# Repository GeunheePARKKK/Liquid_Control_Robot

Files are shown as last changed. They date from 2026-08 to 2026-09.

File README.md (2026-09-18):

# Liquid Control Robot

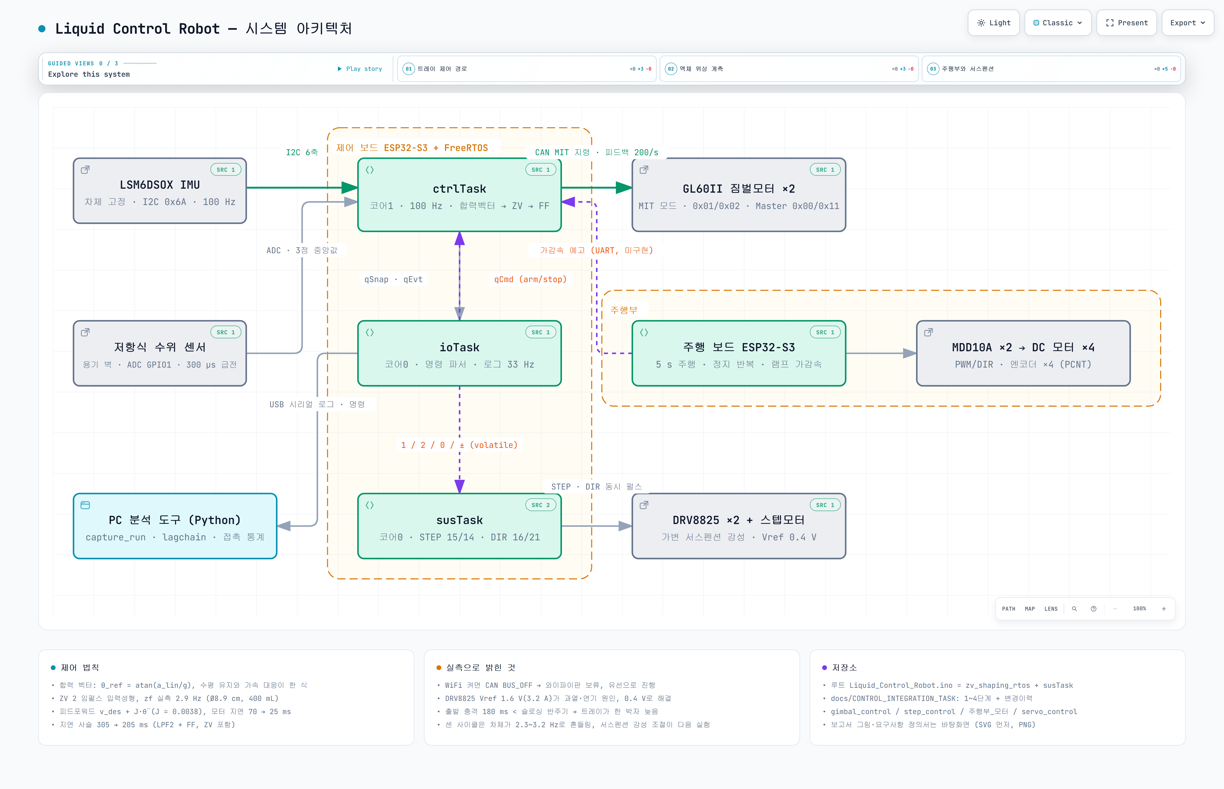
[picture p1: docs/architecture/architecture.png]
architecture


https://geunheeparkkk.github.io/Liquid_Control_Robot/architecture/architecture.html

액체 화물 이송 로봇 제어 시스템 프로젝트입니다.

2026 하계 논문경진대회, 한이음 드림업 공모전 

# 현재 구조

- 'docs': 설계 문서 및 제어 알고리즘 자료
- 'servo_control': 논문경진대회 제출 시 썼던 제어 코드
- 'hardware': 하드웨어와 관련된 파일들

현재는 프로젝트 구조만 구성한 초기 단계입니다.

# POWERSHELL에서 업데이트하는 법

git pull --rebase origin main

git add .

git commit -m "Update"

git push

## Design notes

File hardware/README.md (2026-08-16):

**URDF VIEWER**

https://gkjohnson.github.io/urdf-loaders/javascript/example/bundle/

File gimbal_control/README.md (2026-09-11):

# gimbal_control

짐벌모터 제어 코드.

| 파일 | 내용 |
|---|---|
| [motor_test.ino](motor_test.ino) | 짐벌모터 **2축 동시 구동 테스트** |

---

## 모터 설정 (CubeMars 툴에서 설정 완료)

같은 CAN 버스에 모터 2개가 물려 있다.

| 모터 | CAN ID | Master ID | 상태 |
|:---:|:---:|:---:|---|
| 1축 | `0x01` | `0x00` | 단독 구동 확인 완료 |
| 2축 | `0x02` | `0x11` | 2축 동시 구동 테스트 중 |

> Master ID는 모터가 피드백을 올릴 때 쓰는 식별자.
> 실제로 어떤 값으로 올라오는지는 `motor_test.ino` 로그의 `rxid` 로 확인할 것.

---

## motor_test.ino

두 모터에 **동일한 목표**를 보내 ±0.5 rad을 0.5초 주기로 왕복시킨다.
두 축이 같은 동작을 하는지, 피드백이 각각 정상적으로 올라오는지 확인하는 용도.

### CAN 프로토콜

| 항목 | 값 |
|---|---|
| 속도 | 1 Mbit/s |
| 핀 | TX = GPIO4, RX = GPIO5 |
| 종단저항 | 100Ω |
| 송신 ID | `0x100 \| CAN_ID` (위치/속도 모드) |
| 송신 데이터 | `[0:3]` 목표 위치 float LE / `[4:7]` 속도 제한 float LE |

**유니버설 명령** — `0xFF` × 7 + 명령 바이트

| 바이트 | 동작 |
|:---:|---|
| `0xFB` | 에러 해제 |
| `0xFC` | enable |
| `0xFD` | disable |
| `0xFE` | 현재 위치를 영점으로 |

**수신 프레임**

| 바이트 | 내용 |
|---|---|
| `data[0]` | 상위 4bit = 에러 코드, **하위 4bit = 모터 CAN ID** |
| `data[1:2]` | 위치 (±12.5 rad) |
| `data[6]` | MOS 온도 |
| `data[7]` | 로터 온도 |

> 모터가 2대이므로 수신 프레임은 반드시 `data[0] & 0x0F` 로 어느 모터 것인지
> 구분해야 한다. 1축 시절 코드는 이 구분이 없어 2축에서는 값이 섞인다.

### 정상 동작 예시

```
모터 2개 초기화 완료 (CAN ID: 0x01, 0x02)
[모터1] rxid=0x000 상태=0 pos=+0.50rad temp=32/35
[모터2] rxid=0x011 상태=0 pos=+0.50rad temp=31/34
```

### 한쪽만 응답할 때

1. 종단저항 — 모터 2개면 버스 양 끝에 각각 필요할 수 있음
2. 2축 모터의 CAN ID가 CubeMars 툴에서 실제로 저장됐는지
3. CANH / CANL 분기 배선

---

배선 상세는 [hardware/배선도.md](../hardware/배선도.md) 참고.

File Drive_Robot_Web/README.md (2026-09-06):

# Drive_Robot_Web — ESP32-S3 주행 로봇 웹 브라우저 리모컨

ESP32-S3가 직접 WiFi 핫스팟(AP)과 웹서버를 띄워서, 노트북/휴대폰 브라우저로
W/A/S/D 키를 눌러 실시간 주행 제어하는 리모컨 UI. 공유기·인터넷 불필요.

## 🌐 접속 주소

> ### http://192.168.4.1

⚠ **먼저 ESP32의 WiFi에 연결해야 접속됩니다.** `192.168.4.1`은 ESP32가 만든
자체 네트워크 안에서만 통하는 주소라서, 다른 WiFi나 LTE에서는 열리지 않는다.

| 항목 | 값 |
|---|-----|
| WiFi 이름 (SSID) | `Drive_Robot` |
| WiFi 비밀번호 | `drive1234` |
| 웹 UI | `http://192.168.4.1` |
| WebSocket 포트 | 81 (UI가 자동으로 연결) |

## 사용 순서

1. `drive_web_ui/drive_web_ui.ino` 를 ESP32-S3에 업로드 (보드: **ESP32S3 Dev Module**)
2. 노트북/휴대폰 WiFi 목록에서 **`Drive_Robot`** 접속 (비밀번호 `drive1234`)
3. 브라우저에서 **`http://192.168.4.1`** 열기
4. W/A/S/D — 누르고 있는 동안만 이동, 떼면 즉시 정지 (데드맨 방식)

## 기능

- **W/A/S/D 데드맨 조작** — 누르는 동안만 이동. W+A 같은 동시 입력 조합 가능
- **화면 터치 버튼** — 휴대폰에서도 리모컨으로 사용 가능
- **속도 슬라이더** (0~255)
- **시리얼 모니터 대체** — 하단 명령창에서 임의 명령 전송(`?`, `v200`, `stop` 등),
  보드 출력은 로그창에 실시간 표시. USB 시리얼(115200)도 그대로 공존
- **안전 장치 4중**
  1. 400ms 무소식이면 자동 정지 (WiFi 끊김·브라우저 멈춤 대비 워치독)
  2. 브라우저 탭 이탈/창 포커스 상실 시 정지
  3. WebSocket 연결 끊김 시 정지
  4. Space 키 / STOP 버튼 비상 정지

## 필요한 라이브러리

- **WebSockets** by Markus Sattler ([links2004/arduinoWebSockets](https://github.com/Links2004/arduinoWebSockets))
  — 라이브러리 매니저에서 `WebSockets` 검색 후 설치
- `WiFi.h` / `WebServer.h` 는 ESP32 보드 패키지 내장

## 주행 코드 연결점 (TODO)

현재 모터 출력은 스텁(로그 출력만)이라 모터 없이도 안전하게 UI 테스트 가능.
실제 주행 코드는 `drive_web_ui.ino` 의 두 함수만 채우면 된다:

| 함수 | 역할 |
|---|---|
| `setMotors(fl, fr, rl, rr)` | 4개 모터 드라이버에 PWM 출력 (−255 ~ +255, 부호 = 방향) |
| `handleLine(String)` | 시리얼/웹 명령창 공용 명령 처리 — 기존 코드의 handleLine 이식 자리 |

## 파일 구성

```
drive_web_ui/
├── drive_web_ui.ino   펌웨어 — WiFi AP + HTTP 서버 + WebSocket + 데드맨 워치독
└── web_ui.h           내장 웹 UI (HTML/CSS/JS) — 수정 시 재업로드 필요
```

## WebSocket 프로토콜 (포트 81)

| 방향 | 메시지 | 의미 |
|---|---|---|
| 브라우저 → 보드 | `k:<mask>` | 키 상태 비트마스크 (bit0=W, bit1=A, bit2=S, bit3=D). 눌린 동안 100ms마다 재전송 |
| 브라우저 → 보드 | `v:<0~255>` | 속도 |
| 브라우저 → 보드 | `c:<text>` | 임의 명령줄 (시리얼 모니터와 동일 처리) |
| 브라우저 → 보드 | `x` | 비상 정지 |
| 보드 → 브라우저 | 텍스트 줄 | UI 로그창에 표시 |

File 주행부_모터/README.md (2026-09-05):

# 주행부 ESP32-S3 배선

DC 모터 4개 + MDD10A 2개 + 엔코더 4개를 **별도의 ESP32-S3(2번 보드)** 한 장에 붙인다.
짐벌·수위센서·스텝모터는 지금까지 쓰던 1번 보드에 그대로 남는다.

작성 2026-09-06.

---

## 구성

| 보드 | 담당 | 핀 사용 |
|---|---|---|
| **1번 ESP32-S3** (기존) | 짐벌 CAN, 차체 IMU, 수위센서, **스텝모터 2개** | 1·2 수위 / 4·5 CAN / 11·12 I2C / 19·20 USB / 17·18 보드 간 UART / **14·15·16·21 스텝** |
| **2번 ESP32-S3** (신규) | **DC 모터 4개, MDD10A 2개, 엔코더 4개** | 아래 표 |

두 보드는 UART 한 줄로 잇는다. 2번 보드가 가감속 명령을 내는 순간 1번 보드에 알리면,
짐벌이 IMU로 가속을 재기 전에(65ms 앞서) 트레이를 먼저 기울일 수 있다.

---

## 2번 보드 핀맵

### 왼쪽 구동부 — MDD10A 1 + 왼쪽 앞/뒤 모터

| MDD10A 핀 | 기능 | ESP32-S3 |
|---|---|---|
| PWM 1 | 앞바퀴 속도 | **GPIO 4** |
| DIR 1 | 앞바퀴 방향 | **GPIO 5** |
| PWM 2 | 뒷바퀴 속도 | **GPIO 6** |
| DIR 2 | 뒷바퀴 방향 | **GPIO 7** |
| GND | 로직 GND | ESP32 GND (공통) |

### 오른쪽 구동부 — MDD10A 2 + 오른쪽 앞/뒤 모터

| MDD10A 핀 | 기능 | ESP32-S3 |
|---|---|---|
| PWM 1 | 앞바퀴 속도 | **GPIO 39** |
| DIR 1 | 앞바퀴 방향 | **GPIO 40** |
| PWM 2 | 뒷바퀴 속도 | **GPIO 41** |
| DIR 2 | 뒷바퀴 방향 | **GPIO 42** |
| GND | 로직 GND | ESP32 GND (공통) |

### 엔코더 4개

| 엔코더 | A상 (보라) | B상 (파랑) | Vcc (갈색) | GND (녹색) |
|---|---|---|---|---|
| 왼쪽 앞 | **GPIO 8** | **GPIO 9** | 3V3 | GND |
| 왼쪽 뒤 | **GPIO 10** | **GPIO 11** | 3V3 | GND |
| 오른쪽 앞 | **GPIO 12** | **GPIO 13** | 3V3 | GND |
| 오른쪽 뒤 | **GPIO 14** | **GPIO 15** | 3V3 | GND |

A상·B상 모두 **PCNT(펄스카운터) 하드웨어**가 센다. 우노에서 쓰던 인터럽트 0/1 + PCINT 구분이
필요 없고, 4개 엔코더 전부 쿼드러처(방향 포함)로 CPU 부하 없이 읽힌다.

### 보드 간 UART (1번 보드와)

| 2번 보드 | 1번 보드 | |
|---|---|---|
| **GPIO 17** (TX) | GPIO 18 (RX) | |
| **GPIO 18** (RX) | GPIO 17 (TX) | |
| GND | GND | **공통 필수** |

### 남는 핀

`1 2 16 21 47` 자유. `3`(스트래핑)·`38`/`48`(보드 LED)은 출력 용도로만.

---

## 우노 배선과의 대응

| 기능 | 우노 (예전) | 2번 ESP32-S3 |
|---|---|---|
| 왼앞 PWM / DIR | D5 / A0 | 4 / 5 |
| 왼뒤 PWM / DIR | D6 / A1 | 6 / 7 |
| 오른앞 PWM / DIR | D9 / A2 | 39 / 40 |
| 오른뒤 PWM / DIR | D10 / A3 | 41 / 42 |
| 왼앞 엔코더 A / B | D2 (INT0) / D4 | 8 / 9 |
| 왼뒤 엔코더 A / B | D8 (PCINT) / D11 | 10 / 11 |
| 오른앞 엔코더 A / B | D3 (INT1) / D7 | 12 / 13 |
| 오른뒤 엔코더 A / B | D12 (PCINT) / D13 | 14 / 15 |
| 엔코더 Vcc | 쉴드 V핀 (5V) | **3V3** ← 아래 참고 |

---

## 반드시 확인할 것

### 1. 엔코더 전압 — 5V를 넣으면 핀이 상한다

우노 쉴드에서는 엔코더 Vcc가 5V였고, 그러면 A/B 출력도 5V로 나온다.
**ESP32-S3 GPIO는 5V를 못 받는다.** 엔코더 갈색선을 **3V3**에 물려서 출력을 3.3V로 낮춘다.
대부분의 DC모터 홀 엔코더는 3.3~5V 동작이다. 사양이 5V 전용이면 A/B 각각에
저항 분압(예: 2kΩ + 3.3kΩ)이나 레벨시프터를 넣는다.

### 2. MDD10A 로직 레벨

MDD10A는 3.3V / 5V 로직을 모두 받는다. 별도 처리 없이 GPIO 직결.
**MDD10A GND와 ESP32 GND는 반드시 공통.**

### 3. 전원

- 모터 전원은 MDD10A의 배터리 단자로. ESP32에는 모터 전류가 흐르지 않게.
- ESP32 3V3에서 엔코더 4개(각 10~20mA) 정도는 문제없다.
- 1번 보드에서 CAN 두절이 반복된 이력이 있다. 모터 전원과 짐벌 24V가 같은 배터리면
  가감속 순간의 전압 처짐을 봐야 한다.

### 4. 2번 보드 Arduino IDE 설정

새 스케치 폴더마다 `Tools → USB CDC On Boot = Enabled`. 기본이 Disabled라 잊으면
시리얼이 안 뜬다.

---

## 1번 보드에 붙는 스텝모터 2개

| DRV8825 | 1번 보드 |
|---|---|
| STEP 1 / DIR 1 | **GPIO 15 / 16** |
| STEP 2 / DIR 2 | **GPIO 14 / 21** |
| ENABLE ×2 | GND (항상 켜짐) 또는 남는 핀 하나 공유 |
| RESET, SLEEP | 3V3 (필수) |

`step_control/drv8825_s3_test.ino` 의 STEP/DIR 5/4 는 CAN과 겹치므로 1번 보드에서는 위 핀으로 옮긴다.
1번 보드는 RTOS 라 STEP 펄스를 `delayMicroseconds` 루프로 만들면 100Hz 제어 태스크가 막힌다.
LEDC 나 RMT 로 내야 한다.

---

## 소프트웨어 (2번 보드)

- PWM: LEDC, 20kHz (MDD10A 상한), 4채널
- 엔코더: PCNT 4유닛, 쿼드러처 모드
- 주행 명령을 낼 때 UART 로 1번 보드에 `가속 시작 / 목표 가속도 / 램프 길이`를 보낸다
- 가감속 램프는 **0.7초 이상**으로 둔다. 짐벌 보상이 확실히 먹는 대역이 0.7Hz 아래다

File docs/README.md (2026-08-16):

# Documents

제어 알고리즘, 실험 계획, 논문 및 설계 문서를 보관합니다.

## AI 협업 문서

세 명이 역할을 나누어 각자의 AI와 작업할 때 다음 순서로 자료를 제공합니다.

1. [공통 작업 규약](COMMON_CONTEXT.md)
2. 본인의 역할 문서
3. 역할 문서에 지정된 소스와 데이터시트

역할별 문서:

- [담당 1: GL60II 및 CAN 통신](MOTOR_CAN_TASK/README.md)
- [담당 2: 이중 IMU 및 데이터](SENSOR_DATA_TASK/README.md)
- [담당 3: 제어 알고리즘 및 통합](CONTROL_INTEGRATION_TASK/README.md)

각 담당자는 AI가 제안한 변경사항을 검토하고 승인한 뒤 자신의 브랜치에서 작업합니다. 핀, 센서 종류, 통신 설정과 안전 제한은 `Config.h/.cpp`에서만 정의하며, 다른 모듈은 이를 읽어서 사용합니다.

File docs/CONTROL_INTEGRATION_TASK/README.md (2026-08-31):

# 제어 통합 — 축 정의 및 신호 규약

## 폴더 구성

| 폴더 | 내용 | 상태 |
|---|---|---|
| [`[0단계] 센서 및 모터 설정`](%5B0%EB%8B%A8%EA%B3%84%5D%20%EC%84%BC%EC%84%9C%20%EB%B0%8F%20%EB%AA%A8%ED%84%B0%20%EC%84%A4%EC%A0%95) | IMU 읽기, 배선·통신 진단 | 완료 |
| [`[1단계] 수평제어`](%5B1%EB%8B%A8%EA%B3%84%5D%20%EC%88%98%ED%8F%89%EC%A0%9C%EC%96%B4) | `motor_cmd = −θ_base` | `g1.0` 검증 완료 |
| [`[2단계] 합력벡터`](%5B2%EB%8B%A8%EA%B3%84%5D%20%ED%95%A9%EB%A0%A5%EB%B2%A1%ED%84%B0) | `θ_ref = atan(a_lin/g)` | **작업 중** |
| [`[3단계] ZV 입력성형`](%5B3%EB%8B%A8%EA%B3%84%5D%20ZV%20%EC%9E%85%EB%A0%A5%EC%84%B1%ED%98%95) | `θ_ref` 에 ZV / ZVD | **작업 중** |
| [`[4단계] RTOS 태스크 분리`](%5B4%EB%8B%A8%EA%B3%84%5D%20RTOS%20%ED%83%9C%EC%8A%A4%ED%81%AC%20%EB%B6%84%EB%A6%AC) | `loop()` 을 `ctrl`+`io` 로 분리 | **실기 검산 완료** |
| `capture.py` | 시리얼 로그 캡처 — **전 단계 공용 도구** | — |

`capture.py` 는 특정 단계에 속하지 않아 최상위에 둔다.

### 0단계 — 센서 및 모터 설정

| 파일 | 용도 |
|---|---|
| `IMU_Reading.ino` | IMU 읽기만 (SPI). 상보필터·신뢰도 가중 검증 |
| `MIT_안전점검.ino` | 무동력 상태로 CAN 주소 충돌·게인 탐침 |
| `IMU_핀찾기.ino` | SPI 응답 없을 때 CS 핀 스캔 |
| `IMU_I2C확인.ino` | SPI 죽었을 때 칩 생사 판별 |

### 1단계 — 수평제어

| 파일 | 용도 |
|---|---|
| `모터_수평제어_I2C.ino` | **현행** — IMU I2C |
| `모터_수평제어_MIT.ino` | 같은 제어, IMU 는 SPI (SPI 사망으로 보류) |
| `모터_수평제어.ino` | 위치/속도 모드판 (되돌릴 때용) |

### 2단계 — 합력벡터

| 파일 | 용도 |
|---|---|
| `합력벡터_제어.ino` | 1단계에 `θ_ref` 추가. `ACC_GAIN` 기본 0 |
| `README.md` | 시리얼 명령 파라미터 기능 정리 |

### 3단계 — ZV 입력성형

| 파일 | 용도 |
|---|---|
| `ZV_입력성형.ino` | `θ_ref` 에 ZV/ZVD. `ZV_ON` 기본 꺼짐 |

각 `.ino` 의 변경 이력은 같은 이름의 `_변경이력.md` 에 있다.
`gimbal_control/motor_test_MIT.ino` 는 모터만 돌려보는 테스트다.

## 진행 단계

```
[완료] 1단계  수평제어        motor_cmd = −θ_base
[다음] 2단계  합력 벡터        θ_ref = atan2(a_linear, g)
[작업] 3단계  ZV 입력성형      θ_shaped = ZV(θ_ref)   수평 항에는 걸지 않는다
```

---

## 축 정의

| 이름 | 회전축 | 의미 |
|---|---|---|
| **pitch** | **X축 중심 회전** | 앞뒤 기울기 |
| **roll** | **Y축 중심 회전** | 좌우 기울기 |

---

## 센서 → 각도 매핑

```cpp
// pitch : X축 중심 회전
float rate_pitch = ((float)gx - gyro_bias_x) / GYRO_LSB;                    // X축 자이로
float pitch_acc  = atan2((float)ay,  sqrt(ax*ax + az*az)) * (180.0 / PI);   // Y축 가속도

// roll : Y축 중심 회전
float rate_roll  = ((float)gy - gyro_bias_y) / GYRO_LSB;                    // Y축 자이로
float roll_acc   = atan2((float)-ax, sqrt(ay*ay + az*az)) * (180.0 / PI);   // X축 가속도
```

| | 회전축 | 자이로 | 가속도 |
|---|---|---|---|
| pitch | X | `gx` | `ay` |
| roll | Y | `gy` | `-ax` |

> 회전축과 사용하는 가속도 축이 서로 다르다. X축 중심으로 돌면 Y축 가속도가
> 변하기 때문. 코드 읽을 때 혼동하기 쉬운 지점.

---

## 시리얼 출력 4개

```cpp
Serial.printf("pitch:%.2f,pitch_acc:%.2f,roll:%.2f,roll_acc:%.2f\n",
              pitch_filtered, pitch_acc, roll_filtered, roll_acc);
```

| 출력 이름 | 변수 | 정체 | 용도 |
|---|---|---|---|
| **`pitch`** | `pitch_filtered` | 상보필터 결과 (자이로+가속도 융합) | **제어 입력** |
| `pitch_acc` | `pitch_acc` | 가속도계 단독 계산값 | 진단 전용 |
| **`roll`** | `roll_filtered` | 상보필터 결과 | **제어 입력** |
| `roll_acc` | `roll_acc` | 가속도계 단독 계산값 | 진단 전용 |

- 단위: **도(°)**, 4개 전부
- 기준: **중력 기준 절대 각도** (베이스 대비 상대각이 아님)
- 출력 주기: 10Hz (제어 루프는 100Hz)
- 포맷: `이름:값` 쉼표 구분 — 아두이노 시리얼 플로터 호환

### `_acc` 를 함께 출력하는 이유

제어에 쓰는 값이 아니라 **필터가 제대로 동작하는지 보는 참고선**이다.

| 관측 | 의미 |
|---|---|
| 정지 시 `pitch` ≈ `pitch_acc` | 정상 (실측 0.03° 이내) |
| 움직일 때 둘이 벌어짐 | 정상 — 가속도계가 관성에 오염된 것 |
| 둘이 **반대 방향**으로 움직임 | 자이로 부호 반전 필요 |
| 정지 후에도 안 붙음 | 드리프트 발생 |

제어 코드로 넘어가면 `_acc` 두 개는 디버깅 목적 외에는 빼도 된다.

---

## 모터 대응

### 확정된 것 — 물리 축과 모터 (2026-08-29 실측)

무동력 상태에서 각 축을 손으로 돌려 확인했다. 돌린 축의 모터만 위치가 변했다.

| 물리 축 | 모터 CAN ID | Master ID |
|---|---|---|
| **바깥축** | `0x01` | `0x00` |
| **안쪽축** | `0x02` | **`0x11`** |

> Master ID 가 `0x11` 인 이유는 MIT 모드 명령 주소(`0x001`/`0x002`)와 겹치지
> 않게 하기 위함이다. 겹치면 한 모터가 다른 모터의 피드백을 명령으로 읽어
> 폭주한다. [`모터_수평제어_MIT.ino_변경이력.md`](%5B1%EB%8B%A8%EA%B3%84%5D%20%EC%88%98%ED%8F%89%EC%A0%9C%EC%96%B4/%EB%AA%A8%ED%84%B0_%EC%88%98%ED%8F%89%EC%A0%9C%EC%96%B4_MIT.ino_%EB%B3%80%EA%B2%BD%EC%9D%B4%EB%A0%A5.md) 참고.

### 미확정 — pitch/roll 과 모터

코드의 `CAN_ID_PITCH` / `CAN_ID_ROLL` 은 **임시 배정**이다.

`pitch` 는 "IMU 보드의 X축 중심 회전"인데, 시운전 동안 IMU 를 손에 들고 있어
짐벌의 어느 축과도 고정된 관계가 없었다. **차체에 실장한 뒤** 아래 순서로 확정한다.

1. IMU 의 +X축이 짐벌의 어느 축과 나란한지 확인
2. 그 축을 담당하는 모터를 `CAN_ID_PITCH` 에 배정
3. `DIR_PITCH` / `DIR_ROLL` 부호를 다시 확인

### 참고 — 문서 간 표기가 엇갈린다

X/Y 라는 이름은 쓰지 않기로 했다. 출처마다 반대로 적혀 있기 때문이다.

| 출처 | Pitch | Roll |
|---|---|---|
| 논문 + 이전 서보 코드 | Y축 모터 | X축 모터 |
| 한이음 보고서 | Motor_X | Motor_Y |

그래서 코드에서는 담당 각도로 이름 붙였다 (`CAN_ID_PITCH`, `CAN_ID_ROLL`).

---

## 부호 방향 (검증 완료)

기준은 **브레이크아웃 보드에 인쇄된 X / Y / Z 축 화살표**다.
로봇의 앞뒤좌우가 아니라 보드 자체의 축을 기준으로 판단한다.

### 코드에서 유도한 예상

가속도계는 **위를 향한 축이 +1g** 를 읽는다 (ST 표준 규약).

```cpp
pitch_acc = atan2( ay, ...)    // ay > 0  →  pitch +
roll_acc  = atan2(-ax, ...)    // ax < 0  →  roll +
```

| | 조건 | 물리적 의미 |
|---|---|---|
| **`+pitch`** | `ay > 0` | 보드의 **+Y 축 쪽이 위로** 들림 |
| **`+roll`** | `ax < 0` | 보드의 **+X 축 쪽이 아래로** 내려감 |

### 실측 확인 결과 ✅ (2026-08-27)

**예상과 실측이 일치. 부호 반전 불필요, 코드 수정 없이 그대로 사용.**

| 항목 | 예상 | 실측 |
|---|---|---|
| +Y 축 상승 시 `pitch` | `+` | **`+` 일치** |
| +X 축 하강 시 `roll` | `+` | **`+` 일치** |

확정된 부호 규약.

| 부호 | 물리적 상태 |
|---|---|
| `pitch > 0` | 보드 **+Y 축 쪽이 위로** 들림 |
| `pitch < 0` | 보드 **+Y 축 쪽이 아래로** 내려감 |
| `roll > 0` | 보드 **+X 축 쪽이 아래로** 내려감 |
| `roll < 0` | 보드 **+X 축 쪽이 위로** 들림 |

> **제어기는 이 부호를 줄이는 방향으로 모터를 구동해야 한다.**
> 반대로 걸면 기울어짐을 키우는 방향이 되어 발산한다.

### 재확인 절차

센서를 다시 장착하거나 방향을 바꾸면 아래 절차로 다시 확인한다.
코드 수정 없이 기존 시리얼 출력만 보면 된다.

1. 보드를 평평하게 두고 `pitch` / `roll` 이 0 근처인지 확인
2. **+Y 축 쪽을 들어올린다** → `pitch` 부호 기록
3. 평평하게 되돌린 뒤 **+X 축 쪽을 내린다** → `roll` 부호 기록

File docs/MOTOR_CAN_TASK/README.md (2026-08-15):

# 담당 1: GL60II 및 CAN 통신

## 목표

ESP32-S3의 TWAI 컨트롤러와 외부 CAN 트랜시버를 사용하여 GL60II 두 대에 Position/Velocity 명령을 보내고, 모터 피드백과 통신 상태를 상위 모듈에 제공합니다.

## AI에 제공할 자료

1. `docs/ai-handoff/COMMON_CONTEXT.md`
2. 이 문서
3. `firmware/gimbal_control/Gimbal.h`
4. `firmware/gimbal_control/Gimbal.cpp`
5. `firmware/gimbal_control/Config.h` — 읽기 전용
6. `Gimbal Motor Drive User Manual.pdf`
7. `ESP32-S3-DEVKITC-1-N16R8V_Espressif_Systems.pdf`

## 파일 소유권

- 수정 가능: `Gimbal.h`, `Gimbal.cpp`
- 읽기 전용: `Config.h/.cpp`
- 수정 금지: `Sensor.*`, `Control.*`, `gimbal_control.ino`

새 테스트 파일이나 공용 헤더가 필요하면 팀의 승인을 먼저 받습니다.

## 구현 책임

- Config에서 CAN 핀, 속도, 모터 ID와 타임아웃을 읽어 TWAI 초기화
- GL60II Position/Velocity 표준 11-bit CAN 프레임 생성
- 활성화, 비활성화, 현재 위치 영점, 오류 해제 명령 제공
- 목표 위치 rad와 최대속도 rad/s를 GL60II 형식으로 변환
- 피드백에서 모터 ID, 위치, 속도, 토크, 온도와 오류 코드 해석
- Config에 설정된 두 모터의 최신 피드백을 각각 보관
- 마지막 정상 피드백 시각과 통신 건강 상태 제공
- 잘못된 CAN ID, DLC, 범위 또는 오래된 피드백 거부

## 공개 인터페이스 목표

```cpp
class GimbalBus {
public:
    bool begin();
    bool enable(uint8_t motorId);
    bool disable(uint8_t motorId);
    bool clearError(uint8_t motorId);
    bool setCurrentPositionZero(uint8_t motorId);
    bool commandPositionVelocity(
        uint8_t motorId,
        float positionRad,
        float maxVelocityRadS);
    void poll();
    bool getFeedback(uint8_t motorId, MotorFeedback& out) const;
    bool healthy(uint8_t motorId, uint32_t nowMs) const;
};
```

`GimbalBus`는 IMU, 합력 계산, P와 ZV를 알지 못합니다. 설정값은 Config에서 읽고 프로토콜 계층에서 명령 범위를 검증합니다.

## 구현 순서

1. 매뉴얼에서 Position/Velocity 프레임과 공통 명령 확인
2. ID와 float 바이트 순서 인코딩·디코딩 함수 작성
3. TWAI 초기화와 송수신 처리
4. 한 모터 활성화와 무부하 소각도 명령
5. 두 모터 피드백 분리
6. 타임아웃과 오류 상태 제공

## 안전 및 금지사항

- `begin()`에서 모터를 자동 활성화하지 않습니다.
- 영점 설정을 부팅 시 자동 호출하지 않습니다.
- 피드백을 받지 못했을 때 임의의 값을 만들지 않습니다.
- MIT와 Velocity 모드는 현재 범위에 추가하지 않습니다.
- 통신 타임아웃을 감지하되 시스템 전체 정책은 통합 담당자에게 맡깁니다.
- 핀, ID, 제한값을 `Gimbal` 파일에 하드코딩하지 않습니다.

## 완료 기준

- 매뉴얼 예제와 생성된 CAN ID 및 데이터 바이트가 일치함
- 한 모터가 무부하 소각도 명령을 수행하고 피드백이 갱신됨
- Config로 지정된 두 모터의 피드백이 서로 섞이지 않음
- 잘못된 DLC와 알 수 없는 ID가 거부됨
- 타임아웃 후 `healthy()`가 false를 반환함

## AI 전달용 프롬프트

```text
COMMON_CONTEXT.md, MOTOR_CAN_TASK.md와 제공된 소스 및 데이터시트를 모두 읽어라.
너는 GL60II/TWAI 담당자이며 Gimbal.h와 Gimbal.cpp만 소유한다.
먼저 현재 상태, 데이터시트에서 확인한 프로토콜과 구현 계획을 설명하고 변경 승인을 요청하라.
승인 전에는 파일을 수정하지 마라.
Position/Velocity 모드만 구현하고 센서 및 P/ZV 제어를 추가하지 마라.
핀, CAN ID, 속도와 제한값은 Config에서 읽고 Gimbal 파일에 하드코딩하지 마라.
다른 담당자의 파일은 수정하지 마라.
작업 후 변경 API, 프레임 검증, 하드웨어 시험 절차와 남은 위험을 보고하라.
```

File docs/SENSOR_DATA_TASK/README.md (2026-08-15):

# 담당 2: 이중 IMU 및 데이터

## 목표

하부 베이스와 상부 트레이의 IMU를 안정적으로 읽고, 센서별 물리 단위 데이터와 유효 상태를 제어 모듈에 제공합니다. 이후 슬로싱 주파수 학습에 사용할 데이터 형식을 준비합니다.

## AI에 제공할 자료

1. `docs/ai-handoff/COMMON_CONTEXT.md`
2. 이 문서
3. `firmware/gimbal_control/Sensor.h`
4. `firmware/gimbal_control/Sensor.cpp`
5. `firmware/gimbal_control/Config.h` — 읽기 전용
6. 실제로 확정된 각 IMU의 공식 데이터시트
7. 검증된 기존 센서 코드가 있다면 센서 관련 부분만 별도 제공

## 작업 전 필수 확인

Config에 설정할 두 IMU의 정확한 모델, CS 핀과 공용 SPI 핀을 먼저 확정해야 합니다. 공식 데이터시트에서 다음 항목을 확인하지 못하면 레지스터 코드를 추측하지 않습니다.

- WHO_AM_I 기대값
- 지원 SPI 모드와 최대 클럭
- 초기화 레지스터
- 연속 읽기 시작 주소와 바이트 순서
- 가속도·자이로 측정 범위와 스케일
- 센서 장착 축 변환

서로 다른 IMU 모델을 사용하면 각 센서의 초기화, SPI 설정, 엔디언과 스케일을 분리합니다.

## 파일 소유권

- 수정 가능: `Sensor.h`, `Sensor.cpp`, 승인된 데이터 관련 파일
- 읽기 전용: `Config.h/.cpp`
- 수정 금지: `Gimbal.*`, `Control.*`, `gimbal_control.ino`

## 구현 책임

- Config에서 SPI 핀, CS 핀, 센서 종류와 타임아웃을 읽어 초기화
- 센서별 WHO_AM_I 검사와 초기화 상태 반환
- 원시값을 m/s²와 rad/s로 변환
- 정지 상태 자이로 바이어스 측정
- 필요한 가속도 보정값 제공
- 센서별 샘플 타임스탬프와 `valid` 상태 제공
- 포화, 읽기 실패와 오래된 데이터 검출
- 두 센서 데이터를 일관된 베이스·트레이 축 기준으로 제공
- 시간, 두 IMU, 목표각과 모터 피드백을 결합할 CSV 열 정의 제안

## 공개 인터페이스 목표

```cpp
bool initSensors();
bool calibrateSensorsStationary(uint16_t sampleCount);
bool readSensors(ImuPair& out);
bool sensorsHealthy(uint32_t nowUs);
```

센서 모듈이 자세 추정까지 담당하게 변경하려면 통합 담당자와 먼저 인터페이스를 합의합니다.

## 구현 순서

1. 실제 IMU 모델과 공식 데이터시트 확정
2. 센서별 단독 WHO_AM_I 시험
3. 센서별 원시값과 물리 단위 변환 시험
4. 두 센서 공용 SPI 동시 구성
5. 정지 바이어스 보정
6. 축 방향과 부호 검증
7. 목표 제어주기에서 누락과 지연 측정
8. 통합 데이터 형식 제안

## 안전 및 금지사항

- 센서 초기화 실패를 정상 상태로 숨기지 않습니다.
- 한 센서의 레지스터, 스케일과 바이트 순서를 다른 센서에 재사용하지 않습니다.
- 모터, CAN, P와 ZV 코드를 Sensor에 넣지 않습니다.
- 핀과 센서 종류를 `Sensor` 파일에 하드코딩하지 않습니다.
- 검증되지 않은 데이터를 정상 CNN 학습 데이터로 표시하지 않습니다.

## 완료 기준

- 각 센서의 WHO_AM_I가 공식 기대값과 일치함
- 정지 상태에서 가속도 크기가 약 1 g이고 자이로 평균이 0에 가까움
- 알려진 방향으로 기울일 때 축과 부호가 정의와 일치함
- 두 센서를 함께 읽어도 데이터가 섞이지 않음
- 목표 제어주기에서 샘플 시각과 유효 상태가 안정적으로 갱신됨
- 센서를 분리하면 실패 상태를 보고함

## AI 전달용 프롬프트

```text
COMMON_CONTEXT.md, SENSOR_DATA_TASK.md와 제공된 센서 소스 및 공식 데이터시트를 모두 읽어라.
너는 이중 IMU와 데이터 담당자이며 Sensor.h와 Sensor.cpp만 소유한다.
먼저 두 IMU의 모델, 레지스터, SPI 모드와 스케일이 자료에서 확인되는지 보고하라.
확인되지 않은 하드웨어 정보는 추측하지 마라.
변경 대상과 이유를 설명하고 승인을 받은 뒤에만 파일을 수정하라.
핀, 센서 종류와 타임아웃은 Config에서 읽고 Sensor 파일에 하드코딩하지 마라.
모터, CAN, P, ZV 코드를 추가하거나 다른 담당자의 파일을 수정하지 마라.
작업 후 센서별 설정, 단위, 축 방향, 검증 결과와 장비 시험 항목을 보고하라.
```

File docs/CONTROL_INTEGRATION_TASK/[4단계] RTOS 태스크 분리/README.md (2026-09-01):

# 4단계 — RTOS 태스크 분리

3단계 [`ZV_입력성형.ino`](../%5B3%EB%8B%A8%EA%B3%84%5D%20ZV%20%EC%9E%85%EB%A0%A5%EC%84%B1%ED%98%95/ZV_%EC%9E%85%EB%A0%A5%EC%84%B1%ED%98%95.ino) 에서 출발해 `loop()` 을 태스크로 쪼갰다.

| 파일 | 용도 |
|---|---|
| [`zv_shaping_rtos.ino`](zv_shaping_rtos.ino) | **현행** — RTOS 분리 뒤 축별 게인·속도 피드포워드·지연 계측까지 반영 |
| [`zv_shaping_rtos.ino_변경이력.md`](zv_shaping_rtos.ino_변경이력.md) | 무엇을 왜 바꿨나 |
| [`지연_개선_실험/`](%EC%A7%80%EC%97%B0_%EA%B0%9C%EC%84%A0_%EC%8B%A4%ED%97%98/) | 합력 직접보상 지연 실험 방법·원본 로그·분석 도구·결과 |

> 아두이노 IDE는 스케치 폴더명과 `.ino` 이름이 같아야 한다. 레포에서는 단계별 문서와
> 함께 두기 위해 이 위치를 유지한다. 업로드할 때는 `zv_shaping_rtos`라는 ASCII 폴더에
> `.ino`를 복사해 연다. IDE가 레포 안의 파일을 임의로 옮기거나 개명하게 두지 않는다.

---

## 결론부터

| | 3단계 | 4단계 |
|---|---|---|
| 최초 RTOS 분리 시 제어식·명령 | — | 동일. 실행 구조만 2개 태스크로 분리 |
| 최초 RTOS 분리 당시 출력 문자열 | — | 동일 (문자열 131종 전수 대조) |
| 이후 현행판 추가 | — | 축별 게인, 속도 피드포워드, `raw_pitch/raw_roll` 계측 |
| 실행 구조 | `loop()` 하나 | `ctrl`(코어1) + `io`(코어0) |
| 제어 주기 보장 | `micros()` 폴링 | `vTaskDelayUntil` |
| 최대 틱 실행시간 | 미측정 | **550~593 µs** (예산 10 ms 의 5.6 %) |
| 시리얼이 제어를 막는가 | 막는다 | **안 막는다** |

실기 확인은 [변경이력](zv_shaping_rtos.ino_변경이력.md#실기-검산) 에 숫자로 적었다.

---

## ⚠ 설계안에서 바꾼 것 — 태스크를 5개가 아니라 2개로

앞선 4단계 제안은 `ctrl` / `can_tx` / `can_rx` / `io` / `safety` 5개였다.
**2개만 만들었다.** 이유는 셋이다.

### ① 제안이 짚은 핵심이 2개로 달성된다

> 핵심은 `io` 를 코어 0 의 낮은 우선순위로 빼는 것이다.

그대로 했다. `io` 가 아무리 막혀도 코어 1 의 `ctrl` 은 영향을 안 받는다.

### ② 남은 셋은 쪼갤 근거가 측정으로 사라졌다

한 틱이 **550 µs** 다. 10 ms 예산의 5.6 % 다.

| 제안 태스크 | 왜 안 만들었나 |
|---|---|
| `can_tx` | 송신은 틱 안에서 끝난다. 정상 CAN 에서 **TX실패 0**. 따로 뺄 이유가 없다 |
| `can_rx` | 피드백이 **초당 100회** (50Hz × 2축) 로 오고 100Hz 폴링이 그것과 같은 주기다. 유실 0 |
| `safety` | 판정 대상이 `act_deg` 와 `lastFb` 뿐이다. 별 태스크로 빼면 **읽는 시점이 제어와 어긋나** 오히려 늦게 잡는다 |

### ③ 태스크를 늘리면 공유 상태 위험이 제곱으로 늘어난다

제안서가 지적한 ZV 계수 문제가 정확히 그것이다. 태스크 2개에서도
**락 1개, 큐 3개, 요청 플래그 1개**가 필요했다. 5개면 여기에
`act_deg` · `armed` · `cmd_pitch/roll` · `lastFb` 가 전부 경합 대상이 된다.

**측정된 이득이 없는데 검증 못 할 위험을 늘리지 않는다.** 지금 구조는
"제어식이 안 바뀌었다"를 문자열 전수 대조와 로그 비교로 증명할 수 있다.

필요해지면 `can_rx` 부터 추가하면 된다. 락과 큐가 이미 그 자리에 있다.

---

## 정정 — 시리얼 61% 계산은 성립하지 않는다

제안서의 근거는 이랬다.

```
스트림 한 줄 140자 → 115200 8N1 에서 12.3 ms → 20ms 주기의 61%
```

**ESP32-S3 는 네이티브 USB CDC 라 baud 가 무의미하다.** `Serial.begin(115200)` 의
숫자는 무시되고 실제로는 USB Full-Speed(12 Mbps) 로 나간다. 170자 한 줄이
12.3 ms 가 아니라 수십 µs 다.

실측이 그것을 확인한다. 스트림을 33Hz 로 흘리는 중 **최대 틱 550 µs** 였다.
한 줄에 12.3 ms 가 걸린다면 틱이 최소 12.3 ms 였어야 한다.

**그런데 결론은 맞았다.** 이유가 대역폭이 아니라 이것이다.

> **USB CDC 는 PC 가 읽어가지 않으면 `Serial.printf` 가 그 자리에서 막힌다.**

호스트가 소비를 멈추면 TinyUSB 링버퍼가 차고, 쓰기가 타임아웃까지 블록한다.
그동안 IMU 읽기도 CAN 송신도 멈춘다. **분리해야 하는 이유는 대역폭이 아니라
호스트 의존성이다.** 그래서 4단계는 해야 하는 작업이 맞다.

`readStringUntil` 최대 1초 블록과 `lastLoop += 10000` 몰아치기 지적은 둘 다
맞았고, 각각 문자 단위 비동기 파서와 `vTaskDelayUntil` + 매 틱 재동기로 처리했다.

---

## 쓰는 법

3단계 명령 `arm` `stop` `g` `ag` `ad` `kp` `kd` `f` `r` `d` `dp` `dr` `zv`
`zf` `zd` `zm` `?` `t` `z`는 그대로다. 현행판에는 축별 게인 `kpp` `kpr` `kdp`
`kdr`과 속도 피드포워드 `vf`가 추가됐다.

```
① 24V 끄기
② zv_shaping_rtos 업로드   (도구 → USB CDC On Boot = Enabled)
③ 부팅 배너 확인
④ 24V 켜기                 ← 부팅 뒤에 켜면 모터가 disable 로 깨어난다
⑤ arm
```

부팅 배너에 `2단계 — 합력 벡터 목표각` 이라고 나온다. 3단계에서 안 고친 문구를
그대로 뒀다 (출력 동결). 아래 `zv1/zv0` 줄이 보이면 4단계다.

### 계측 줄

```
[rtos] 최대틱 556us  10ms초과 0  재동기 1 | TX실패 0 샘플드롭 0 이벤트드롭 0 명령드롭 0
```

2초마다 나온다. `#define RTOS_DIAG 0` 으로 두면 이 줄이 사라지고 출력이 3단계와
완전히 같아진다.

| 항목 | 정상값 | 의미 |
|---|---|---|
| `최대틱` | ~550 µs | 2초 창의 최대 제어 틱 시간. 예산 10,000 |
| `10ms초과` | 0 | 데드라인 놓친 횟수 |
| `재동기` | arm 당 1 | `arm` 의 `delay` 250 ms 뒤 시계 재설정 (설계대로) |
| `TX실패` | 0 | CAN 송신 실패. 모터 전원이 없으면 늘어난다 |
| `샘플드롭` | 0 | PC 가 안 읽어가면 늘어난다. **제어는 안 멈춘다** |

---

## 아직 안 된 것

### `ZV_FREQ` 실측 — 3단계에서 넘어온 숙제

`2.40Hz` 는 계산값이다. 물을 채우고 재야 한다.

```
한 번 기울였다 놓고 → 출렁임 10회에 몇 초인지 → 10 / 초 = Hz → zf<값>
```

### `t`(시험구동) 중에는 보호가 꺼져 있다 — 3단계에도 있는 문제

`motorSweep()` 은 앞에서 `motorsDisarm()` 을 부르므로 `armed == false` 다.
`drainCAN()` 안의 검사가 전부 `armed` 로 막혀 있어서, **8초 구동 내내
모터 이상·위치 폭주·피드백 두절이 감시되지 않는다.** 복귀 루프
(`while (fabsf(p) > 0.5f)`)는 `drainCAN()` 자체를 안 부른다.

이번에는 손대지 않았다 (제어 동작 동결). `sweeping` 플래그를 두고 검사 조건을
`(armed || sweeping)` 으로 바꾸면 된다. **실기에서 `t` 를 쓰기 전에 고치는 게 좋다.**

### 드라이버 `CAN Timeout = 0`

CAN 이 끊겨도 드라이버가 스스로 멈추지 않는다. 업로드 중 리셋되면 모터가
마지막 지령을 계속 붙잡는다. 로봇에 올리기 전에 200~500 ms 로 넣는 게 좋다.

### USB 로그 줄 깨짐 0.45%

1111줄 중 5줄에서 중간 몇 바이트가 빠졌다. 3단계 로그(1137줄)는 0줄이었으니
**이 구조에서 새로 생긴 것이 맞다.**

`Serial` 은 `io` 태스크 한 곳에서만 쓴다 (함수별 전수 감사 완료). 태스크 경합이
아니라 ESP32-S3 USB CDC 가 연속 `write()` 를 처리하다 흘리는 것으로 보이는데
**원인을 확정하지 못했다.**

지령은 CAN 으로 나가므로 **모터 제어와는 무관하고**, 로그 표시만의 문제다.
완화책은 `io` 태스크의 각 출력 뒤에 `Serial.flush()` 를 넣는 것이다 —
`io` 가 막혀도 제어는 코어 1 에서 계속 돈다. 아직 넣지 않았다.

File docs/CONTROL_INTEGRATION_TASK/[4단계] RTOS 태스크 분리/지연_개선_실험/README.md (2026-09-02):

# 4단계 합력 직접보상 지연 개선 실험

이 폴더는 `zv_shaping_rtos.ino`의 **합력 목표 생성부터 모터 엔코더 응답까지**
구간별 지연을 분리하고, 필터·CAN 주기·모터 게인이 응답성과 안정성에 미치는 영향을
실기에서 비교한 자료다.

현재 실물 시험의 목표는 ZV 성능 검증이 아니다. 단일 베이스 IMU가 계산한 합력 목표를
모터가 가능한 한 빠르고 안정적으로 추종하게 만드는 **직접보상 경로**를 먼저 확정한다.
ZV는 전 시험에서 껐다.

상세 수치와 판단은 [`결과_분석.md`](%EA%B2%B0%EA%B3%BC_%EB%B6%84%EC%84%9D.md)에 있다.

## 폴더 구성

| 경로 | 내용 |
|---|---|
| `tools/capture.py` | ESP32-S3 시리얼을 arm 전후로 캡처한다 |
| `tools/check_tuning.py` | 드룹·슬루·지연·추종률·정지 떨림을 계산한다 |
| `logs/` | 이 문서의 판단에 사용한 원본 로그 15개 |
| `requirements.txt` | PC 분석 도구 의존성 |
| [`soft_return_rtos.ino`](soft_return_rtos.ino) | 가속 종료 HOLD·최소저크 복귀를 추가한 실험 펌웨어 |
| [`소프트_복귀_제어.md`](%EC%86%8C%ED%94%84%ED%8A%B8_%EB%B3%B5%EA%B7%80_%EC%A0%9C%EC%96%B4.md) | 로직·명령·안전·실험 및 판정 방법 |

`capture.py`와 `check_tuning.py`는 실험 당시 사용한 버전을 그대로 보존했다.

`soft_return_rtos.ino`는 아래 지연 개선 결과 뒤에 추가한 후속 실험 코드다. 기존
15개 로그와 `결과_분석.md`의 수치는 모두 소프트 복귀를 사용하기 전 결과이며, 새 로직은
아직 액체 실험으로 검증되지 않았다.

## 실험 환경

```text
상자 바닥               LSM6DSOX IMU 1개
상자 위                 2축 GL60II 짐벌
안쪽축 PITCH            CAN 0x02
바깥축 ROLL             CAN 0x01, 안쪽 짐벌과 트레이 전체를 함께 회전
제어 태스크             100 Hz
로그 스트림             약 33 Hz
```

이 시험에는 트레이 IMU가 없다. `act_pitch/act_roll`은 모터 엔코더 관절각이지 트레이
절대각이 아니다. 강체·영점·유격이 이상적이라는 가정 아래에서만 트레이 움직임의
대용값으로 쓴다.

또한 앞뒤 방향은 바퀴가 굴러가지만 좌우 방향은 상자를 바닥에서 끈다. 좌우 시험에는
정지마찰·stick-slip·상자 회전·바닥 충격이 섞일 수 있으므로 PITCH와 ROLL의 절대 성능을
그대로 비교하지 않는다. 같은 방향, 비슷한 입력 대역의 로그끼리만 A/B 비교한다.

## 로그 신호

현행 펌웨어는 다음 필드를 출력한다.

```text
t
raw_pitch/raw_roll
pre_pitch/pre_roll
pitch/roll
ref_pitch/ref_roll
zv_pitch/zv_roll
cmd_pitch/cmd_roll
act_pitch/act_roll
```

신호 사슬은 다음처럼 해석한다.

```text
물리 가속
  → raw
  → ACC_LPF
  → ref
  → ZV
  → want = ACC_GAIN·zv − GAIN·base_angle
  → CMD_LPF
  → pre
  → slew
  → cmd
  → CAN/MIT 모터
  → act
```

`want`는 로그에 직접 없으며 분석기가 `zv`, 베이스 자세, `GAIN`, `ACC_GAIN`, 각도
제한으로 재구성한다. 재구성한 `want`에 동일한 `CMD_LPF`를 적용하면 `pre`가 약 1%
오차로 재현되는 것을 확인했다.

## PC 준비

Python 3 환경에서:

```powershell
python -m pip install -r requirements.txt
```

시리얼 모니터와 `capture.py`는 같은 포트를 동시에 열 수 없다. 캡처 전에 Arduino IDE
시리얼 모니터를 닫는다.

## 안전 절차

1. 펌웨어 업로드 때 24 V 모터 전원을 끈다.
2. ESP32 부팅 뒤 24 V를 켠다.
3. 트레이가 중립이고 걸리는 물체가 없는지 확인한다.
4. 24 V 차단 스위치에 손을 둔 상태에서 `arm`한다.
5. 발진·충격·이상음이 나면 즉시 전원을 차단한다.
6. 이 시험에는 물을 올리지 않는다.
7. `t` 시험구동은 보호 로직이 꺼지는 구간이 있으므로 사용하지 않는다.

포트를 열면 ESP32가 리셋되어 이전 시리얼 설정이 모두 사라진다. 비교에 필요한 설정은
반드시 `capture.py --cmd`에 전부 적는다.

## 표준 수동 입력

완전한 정현파 입력 장치를 사용할 수 없어 다음 절차로 반복성을 높였다.

1. 메트로놈을 60 BPM으로 켠다.
2. 네 박자를 한 동작 구간으로 사용한다.
3. 두 손으로 상자 중심을 잡아 앞뒤로 밀고 정지한다.
4. 같은 방식으로 좌우로 밀고 정지한다.
5. 회전이 섞이지 않도록 양손 힘을 대칭으로 준다.
6. 모든 후보에서 같은 박자·거리·순서로 26초를 기록한다.

수동 입력은 완전히 같지 않다. 분석 결과의 `흔든 대역`이 약 0.15~0.20 Hz 이상 다르면
시간지연을 직접 비교하지 않는다. 동일 설정도 최소 2회, 기준 설정은 3회 반복한다.

## 캡처

현행 잠정 설정의 예다.

```powershell
cd tools

python capture.py --port COM8 `
  --cmd "zv0,vf1,ad0.20,f0.30,r120,d1,kpp2.0,kdp0.13,kpr2.0,kdr0.40,arm" `
  --pre 6 --post 26 --out run_01.txt
```

핵심 설정:

| 명령 | 의미 |
|---|---|
| `zv0` | ZV 끔. 직접보상 경로만 시험 |
| `vf1` | MIT `v_des` 속도 피드포워드 켬 |
| `ad0.20` | ACC 목표각 EMA의 현재값 비율 20% |
| `f0.30` | 최종 명령 EMA의 현재값 비율 30% |
| `r120` | 슬루 상한 120 deg/s |
| `d1` | CAN 명령 100 Hz |
| `kpp/kdp` | 안쪽 PITCH 게인 |
| `kpr/kdr` | 바깥 ROLL 게인 |

### 소프트 복귀 후속 실험

가속 종료 때 남은 합력 목표각을 잠시 유지한 뒤 최소저크 곡선으로 수평 복귀하는
실험 버전은 `soft_return_rtos.ino`다. 상세 원리와 파라미터 범위는
[`소프트_복귀_제어.md`](%EC%86%8C%ED%94%84%ED%8A%B8_%EB%B3%B5%EA%B7%80_%EC%A0%9C%EC%96%B4.md)를
참고한다.

```powershell
python capture.py --port COM8 `
  --cmd "zv0,sr1,sra1.5,sre0.75,srd30,srh100,srr120,vf1,ad0.20,f0.30,r120,d1,kpp2.0,kdp0.13,kpr2.0,kdr0.40,arm" `
  --pre 6 --post 26 --out SOFT_RETURN_01.txt
```

기능은 기본 OFF이며 `sr1`로 켠다. `sr1`과 기존 `zv1`은 동시에 동작하지 않는다.

## 분석

한 파일:

```powershell
python check_tuning.py ..\logs\CAN100_01.txt
```

여러 파일 비교:

```powershell
python check_tuning.py `
  ..\logs\baseline_01.txt `
  ..\logs\baseline_02.txt `
  ..\logs\baseline_03.txt `
  ..\logs\CAN100_01.txt `
  ..\logs\CAN100_02.txt
```

중요 지표:

| 지표 | 해석 |
|---|---|
| `cmd→act` | CAN·모터·기구의 동적 응답 |
| `want→act − cmd→act` | CMD_LPF 기여분의 근사 |
| `raw→act − want→act` | ACC 전처리 기여분의 근사 |
| 추종률 | `std(act)/std(cmd)`. 1 초과는 동적 증폭 |
| 외란 몫 | 모터 명령으로 설명되지 않는 출력 분산 |
| 떨림 | 정지 구간 엔코더의 고주파 표준편차 |
| 흔든 대역 | 입력 스펙트럼 누적파워 50% 지점 |

`check_tuning.py`의 지연은 광대역 수동 입력의 상호상관 최대점이다. 고정된 물리적
전달지연이 아니며 입력 주파수에 따라 달라진다. 출력되는 `슬로싱 위상`도 계산 주기
456 ms에 지연을 단순 환산한 참고값일 뿐, 실제 액체 위상이나 ZV 효과의 측정값이 아니다.

## 현재 잠정값

```text
zv0, vf1, ad0.20, f0.30, r120, d1
kpp2.0, kdp0.13, kpr2.0, kdr0.40
```

이 값은 펌웨어 기본값으로 확정한 것이 아니다. 캡처 명령으로 적용한 현재 최선 후보다.
ROLL은 여전히 `cmd→act` 약 85 ms, 추종률 약 1.4라 추가 검증이 필요하다.

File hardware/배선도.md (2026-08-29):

# 배선도 (ESP32-S3)

현재 배선 상태 정리. 연결 절차는 [모터_ESP32연결.md](모터_ESP32연결.md) 참고.

| 구분 | 상태 |
|---|---|
| 짐벌모터 ×2 (CAN) | 연결 완료 |
| 베이스 IMU (**I2C**, 0x6A) | 연결 완료 |
| 트레이 IMU (**I2C**, 0x6B) | 예정 |
| 모터 드라이버 UART | 핀만 예약 (미사용) |

---

## 1. ESP32-S3 핀 배정 (전체)

| GPIO | 연결 대상 | 신호 | 비고 |
|:---:|---|---|---|
| **4** | CAN 트랜시버 | TXD | TWAI TX |
| **5** | CAN 트랜시버 | RXD | TWAI RX |
| **11** | IMU 공통 | **SDA** | I2C 데이터 |
| **12** | IMU 공통 | **SCL** | I2C 클럭 |
| ~~9, 10, 13~~ | — | — | SPI 시절 CS·MISO. **현재 미사용** |
| **17** | — | UART TX | 예약 (드라이버 UART 전환용) |
| **18** | — | UART RX | 예약 |
| **3V3** | 트랜시버 + IMU ×2 | VCC | |
| **GND** | 전체 공통 | GND | 전원(−)까지 전부 묶기 |

---

## 2. 전원

| 항목 | 값 |
|---|---|
| 공급 전압 | **24V** (모터 허용 8~32V) |
| 전류 제한 | 1~2A (테스트 시) |
| ESP32 / IMU / 트랜시버 | 3.3V |

---

## 3. CAN — 짐벌모터 ×2

모터 케이블: XT30(2+2) ↔ 4가닥

| 케이블 색 | 신호 | 연결 위치 |
|---|---|---|
| 🔴 빨강 | 전원 + | 전원공급기 + (24V) |
| ⚫ 검정 | 전원 − | 전원공급기 − (+ 공통 GND) |
| ⚪ 흰색 | CAN_H | 트랜시버 CANH |
| 🔵 파랑 | CAN_L | 트랜시버 CANL |

> 흰색/파랑이 바뀌면 통신만 안 되고 고장은 안 남. 빨강/검정 극성만 주의.

### 트랜시버 ↔ ESP32-S3

| 트랜시버 | ESP32-S3 |
|---|---|
| VCC | 3V3 |
| GND | GND |
| TXD | GPIO 4 |
| RXD | GPIO 5 |

### 종단저항

- CANH ↔ CANL 사이에 **100Ω**
- 모터 2개가 같은 버스에 붙으므로 **CAN ID를 서로 다르게** 설정해야 함

---

## 4. SPI — IMU ×2

보드 라벨이 I2C 표기(`SDA`/`SCL`/`SDO`)지만 SPI 4-wire 모드에서는 아래와 같이 동작.

| IMU 보드 라벨 | SPI 기능 | ESP32-S3 |
|---|---|---|
| **SDA** | MOSI | GPIO 11 |
| **SCL** | SCK | GPIO 12 |
| **SDO** | MISO | GPIO 13 |
| **CS** | Chip Select | **베이스 10** / 트레이 9 |
| VIN | 전원 | 3V3 |
| GND | 접지 | GND |

`SDA` / `SCL` / `SDO` 3개는 두 IMU가 **병렬 공유**, `CS`만 개별.

```
ESP32-S3                    베이스 IMU        트레이 IMU
                            (현재 사용)       (미연결, 예정)
─────────                   ──────────        ──────────
  3V3 ──────┬─────────────── VIN ──────┬──────── VIN
  GND ──────┼─────────────── GND ──────┼──────── GND
GPIO11 ─────┼─────────────── SDA ──────┼──────── SDA
GPIO12 ─────┼─────────────── SCL ──────┼──────── SCL
GPIO13 ─────┼─────────────── SDO ──────┼──────── SDO
GPIO10 ─────┼─────────────── CS         │
GPIO 9 ─────┼──────────────────────────┴──────── CS
            └── 10kΩ 풀업 ×2 → 3V3
```

### SPI 설정

| 항목 | 값 |
|---|---|
| 클럭 | 1 MHz |
| 모드 | SPI_MODE0 |
| 비트 순서 | MSBFIRST |

```cpp
SPI.begin(12, 13, 11);   // (SCK, MISO, MOSI)
```

### 트레이 IMU 케이블 (회전부)

트레이 IMU는 짐벌 위에서 회전하므로 일반 배선과 다르게 처리.

| 항목 | 사양 |
|---|---|
| 전선 | 연선(stranded) 실리콘, 28~30 AWG |
| 배선 경로 | 회전축에 최대한 가깝게 + 서비스 루프 |
| 차폐 | 실드는 ESP32 쪽 **한쪽만** 접지 |
| 직렬저항 | SCL·SDA에 33~100Ω |
| 디커플링 | IMU 옆 100nF + 케이블 끝단 10µF |
| 모터 전원선 | 같이 묶지 말고 물리적으로 분리 |

---

## 5. 공통 그라운드

아래 4곳을 반드시 한 점으로 묶는다.

```
전원공급기 (−)  ─┐
CAN 트랜시버 GND ─┤
ESP32-S3 GND     ─┼── 공통 GND
IMU ×2 GND       ─┘
```

IMU GND는 모터 전류가 흐르는 경로와 공유하지 않고 **전용선으로 ESP32까지 직결**.

---

## 6. ESP32-S3 사용 금지 핀

| GPIO | 이유 |
|---|---|
| 19, 20 | USB D− / D+ |
| 22 ~ 25 | S3에 존재하지 않음 |
| 26 ~ 32 | SPI 플래시 |
| 33 ~ 37 | 옥타 PSRAM 모듈(N8R8 등) |
| 0, 3, 45, 46 | 스트래핑 핀 |
| 43, 44 | UART0 (시리얼 모니터) |
| 38 | DevKit RGB LED |

**여유 핀:** 1, 2, 6, 7, 8, 14, 15, 16, 21, 47, 48

---

## 7. 배선 검증

전원 인가 후 순서대로 확인.

| 대상 | 확인 방법 | 정상 |
|---|---|---|
| 모터 보드 | 표시등 | 초록불(Enable) 점등 / 빨간불 미점멸 |
| IMU (LSM6DSOX) | `WHO_AM_I` = `0x0F \| 0x80` | `0x6C` |

IMU 응답 이상 시:

| 응답 | 의심 |
|---|---|
| `0xFF` | MISO 미연결 / CS가 안 내려감 |
| `0x00` | MISO 단선 / GND 미연결 |

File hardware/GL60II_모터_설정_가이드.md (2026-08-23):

# GL60II 모터 — ESP32 연결 및 설정 가이드

작업일: 2026-08-23 · 상태: **배선 완료 + CAN ID 변경(파라미터 설정) 완료**

간단한 CAN 배선만 필요하면 [`모터_ESP32연결.md`](모터_ESP32연결.md) 를 본다.
이 문서는 거기서 한 걸음 더 나가서, **드라이버 파라미터(CAN ID 등)를 직접 바꿔야 할 때**
필요한 시리얼 배선·설정·절차와, 그 과정에서 겪은 문제들을 정리한 것이다.

- CAN 프로토콜과 실제 동작 코드: [`hardware/MOTOR_HANDOFF.md`](MOTOR_HANDOFF.md)
- 진단용 스케치: `hardware/motor_serial_tools/`

---

## 0. ⚠️ 먼저 확인하세요 — 가장 많이 걸리는 함정 두 가지

시리얼이 안 뜬다고 배선을 다시 뜯기 전에, 이 두 개부터 확인한다.
아래를 안 보고 몇 시간을 배선 탓으로 돌린 적이 있어서 맨 위에 적어둔다.

### ① 이 ESP32-S3 보드는 USB-C 단자가 **두 개**다

보드에 `USB`, `COM` 이라고 적힌 USB-C 포트가 각각 따로 있다. 물리적으로 완전히
다른 경로다 (하나는 ESP32 칩의 네이티브 USB, 다른 하나는 온보드 USB-시리얼 변환칩을
거친다).

| CDC 설정 (Tools → USB CDC On Boot) | 꽂아야 하는 단자 |
|---|---|
| **Enabled** | 반드시 **`USB`** 라고 적힌 단자 |
| Disabled | `COM` 이라고 적힌 단자 |

**엇갈리면 화면이 완전히 텅 빈다.** 배선(TX/RX, GND, 풀다운 등)은 전부 정상인데 그냥
"연결은 됐지만 코드가 보는 포트가 아닌" 상태가 되고, 증상만 보면 배선 불량과 구분이 안 된다.
시리얼이 안 뜨면 배선보다 **이 단자 매칭을 제일 먼저** 확인한다.

### ② 드라이버는 전원만 켠다고 먼저 말을 걸지 않는다

매뉴얼 p17에는 "전원을 인가하면 시리얼 포트가 정보를 출력한다"고 적혀 있지만,
**실제로는 상위 SW(CubeMars)가 먼저 질의를 보내야 응답이 온다.** 드라이버가 자발적으로
보내는 데이터는 없다. 그래서 "포트 열고 → 전원 켜고 → 로그 뜨는지 기다리기"는
애초에 성립하지 않는 테스트다. 확인하려면 상위 SW로 `ReadParam`을 눌러야 한다 (4장 참고).

이 두 가지가 겹치면 "배선 다 맞는데 아무것도 안 뜬다"는 증상이 나오고, 케이블 연속성
체크·GND 교차검증·TX/RX 스왑·풀다운 테스트를 아무리 해도 원인이 안 잡힌다. 그 테스트들
자체가 틀린 게 아니라, 순서상 **① 단자 확인이 먼저**여야 한다는 뜻이다.

---

## 1. 시리얼 3핀 배선 (파라미터 설정용, 별도 케이블 필요)

CAN/전원 배선은 [`모터_ESP32연결.md`](모터_ESP32연결.md) 를 그대로 따르고, 거기에
아래 시리얼 3핀만 추가로 연결한다. 드라이버에는 커넥터가 두 개이고, **둘 다 동시에
연결한 상태로 작업했다.**

| 드라이버 3핀 | ESP32-S3 |
|---|---|
| GND | GND |
| **가운데 핀** | **GPIO17** |
| **끝 핀** | **GPIO18** |

> **매뉴얼(p7)의 핀 순서(1=GND, 2=TX, 3=RX)와 실제가 반대였다.**
> 처음에 GND 다음 핀을 GPIO18에 연결했을 때는 통신이 안 됐고,
> GPIO17로 바꾸자 바로 됐다. 위 조합을 기준으로 삼는다.

이 커넥터는 **CJT A1257, 1.25mm 간격**이라 모터에 딸려온 케이블에는 없다.
`GH1.25 3핀 케이블` (JST GH 호환) 을 별도로 구해야 한다. 브레드보드용 흔한
듀폰 점퍼(2.54mm)는 간격이 두 배라 안 들어간다.

### 배선 시 주의 (노이즈)

드라이버 PWM 노이즈(40kHz, 25µs 주기)가 시리얼 선에 유도되어 통신을 방해할 수 있다.

- 3핀 시리얼 선을 모터 3상 선·24V 전원선에서 멀리 뗄 것
- 신호선을 GND 선과 꼬아서(트위스트) 배선할 것
- 선 길이를 최소화할 것

### 전체 배선도 (실제로 동작한 구성)

```
  전원공급기 24V (전류제한 2A 이상)
    |
    +- 빨강 --------------------------+
    +- 검정 ------------+-------------+
    |                   |         +---+---------------------------+
    |                   |         |    GL60II 드라이버             |
    |                   |         |                               |
    |                   |         |  (2) XT30(2+2)  전원 + CAN     |
    |                   |         |      빨강 = 전원 +             |
    |                   |         |      검정 = 전원 -             |
    |                   |         |      흰색 = CAN_H  ---------+  |
    |                   |         |      파랑 = CAN_L  --------+|  |
    |                   |         |                           ||  |
    |                   |         |  (1) 3핀 시리얼 (1.25mm)   ||  |
    |                   |         |      GND ----------+      ||  |
    |                   |         |      가운데 -------|--+   ||  |
    |                   |         |      끝 ----------|--|-+  ||  |
    |                   |         +-------------------|--|-|--++--+
    |                   |                             |  | |  ||
    |              +----+-----------------------------+--+-+--++---+
    |              |                                  |  | |  ||   |
    |              |   SN65HVD230 트랜시버              |  | |  ||   |
    |              |     GND   CANH   CANL  <----------|--|-|--++   |
    |              |            +--100옴--+            |  | |       |
    |              |     VCC   TXD    RXD              |  | |       |
    |              +------+-----+------+---------------+--+-+-------+
    |                   3V3  GPIO4  GPIO5           GND GPIO17 GPIO18
    |              +------+-----+------+---------------+--+-+-------+
    +- GND 공통 ---+              ESP32-S3                            |
                   |         "USB" 단자 --> PC                        |
                   +------------------------------------------------+
```

---

## 2. 확정된 시리얼 통신 설정 (파라미터 읽기/쓰기용)

| 항목 | 값 |
|---|---|
| **Baud rate** | **921600** |
| Data bits / Parity / Stop bits | 8 / None / One |
| COM 포트 (PC 쪽, Windows 장치관리자 표시) | ESP32 네이티브 USB CDC 포트 (PC마다 번호 다름) |
| CubeMars USB모드 | UART |

### Arduino IDE 설정

```
Tools -> Board            -> ESP32S3 Dev Module
Tools -> USB CDC On Boot  -> Enabled
케이블                     -> 보드의 "USB" 단자 ("COM" 단자 아님, 0장 참고)
```

### 사용한 스케치

`hardware/motor_serial_tools/serial_bridge/serial_bridge.ino` (MOTOR_BAUD = 921600)

---

## 3. 드라이버 파라미터 원본 (변경 전 백업)

**모터 #1 기준. 문제 생기면 이 값으로 되돌린다.**

원본 화면 캡처: [`docs/img/motor_params_original.png`](../docs/img/motor_params_original.png)

### Drive parameters

| 항목 | 값 | 비고 |
|---|---|---|
| **CAN ID** | 0x01 → **0x02 로 변경** | 이번 작업 대상 |
| **Master ID** | 0x00 | 변경 안 함 |
| NPP (극쌍수) | 14 | |
| GR (감속비) | 1 | 직결 |
| UV / OV (저·과전압) | 15 / 32 | V |
| OT (과열) | 100 | °C |
| CAN Timeout | 0 | 비활성 |
| Acc / Dec | 2 / -2 | |
| SpeedLimit | 53.37238 | |
| Overcurrent | 0.8 | |

### Amplitude — ⚠ 여기가 중요

| 항목 | 값 | 매뉴얼 기본값 |
|---|---|---|
| PMAX | 12.5 | 12.5 (일치) |
| **VMAX** | **30** | **200 (다름!)** |
| TMAX | 10 | 10 (일치) |
| KT_OUT | 0 | |
| Gear factor | 1 | |
| Damping factor | 4 | |

### Motor parameters

| 항목 | 값 |
|---|---|
| PhaseRes (R) | 2950.447 mR |
| PhaseInd (L) | 2547.01 uH |
| FluxLinkage (λ) | 0.01676579 Wb |
| Fri Coeff | 0.0004747659 |
| Inertia | 0.0001308374 kg·m² |

### Control settings

| 항목 | 값 |
|---|---|
| ControlMode | **2:Pos** (위치 모드) |
| CurrentBW | 1000 |
| Speed KP / KI | 0.003630572 / 0.003926991 |
| Position KP / KI | 54 / 0 |

### 기타

| 항목 | 값 |
|---|---|
| Firmware 버전 | V1.6.8.5 |

---

## 4. 상위 SW 조작 순서 (파라미터 변경 재현용)

```
1. Arduino IDE 시리얼 모니터 닫기 / IDE 닫기
2. ESP32 에 serial_bridge.ino 업로드 (MOTOR_BAUD 921600)
3. 모터 24V 전원 ON        <- 반드시 켜야 한다. 안 켜면 무조건 시간 초과
4. CubeMars.exe 실행
5. Serial Port 구역: 포트 선택, Baud 921600 확인 -> OpenPort
6. "Set parameters" 탭 -> "ReadParam"           <- 반드시 먼저 읽어야 한다 (0-② 참고)
7. 값 수정 (예: CAN ID)
8. "WriteParam"
9. 모터 전원 OFF -> ON
10. "ReadParam" 으로 변경 확인
```

상위 SW: 제조사 배포판 `gl-ii-upper-computer-v1-0.zip` 을 풀면 `CubeMars.exe` 하나가 나온다.
별도 설치 없이 실행된다. 서명이 없어 Windows SmartScreen 경고가 뜨면
"추가 정보" → "실행" 으로 넘기면 된다. (리포에는 포함하지 않았다 — 제조사 배포물)

### 절대 누르지 말 것

| 금지 | 이유 |
|---|---|
| **Calibrate** | 모터가 회전하며 센서 교정을 다시 한다. 드라이버 보드 재장착·3상 배선 변경·펌웨어 업데이트 시에만 필요(매뉴얼 4.3). 기존 교정값이 깨진다 |
| **Upgrade (펌웨어)** | 실패하면 드라이버가 벽돌된다 |
| CAN ID 외 다른 파라미터 | 위 3장 백업값과 달라지면 원인 추적이 어려워진다 |

### COM 포트는 한 프로그램만 독점한다

**Arduino IDE 시리얼 모니터가 열려 있으면 CubeMars 가 포트를 못 연다.**
"포트를 먼저 열어라" 메시지가 뜨면 이것부터 확인한다.
업로드할 때는 반대로 CubeMars 를 닫아야 한다.

---

## 5. ⚠ VMAX = 30 — 코드 수정이 필요하다

[`hardware/MOTOR_HANDOFF.md`](MOTOR_HANDOFF.md) 와 매뉴얼은 속도 범위를 **±200 rad/s** 로
적고 있지만, **이 드라이버의 실제 VMAX 는 30** 이다. 매뉴얼 p48에도 명시돼 있다.

> Pos, Vel, Torque 는 각각 ±12.5, ±200, ±10 으로 프리셋되어 있으며, 이 세
> 파라미터는 모터의 실제 파라미터에 따라 조정할 수 있다. **제어 명령을 보낼 때는
> 설정된 값과 일치시키는 것이 필수적이다.**

### 영향받는 곳

**① 피드백 속도 해석** — 12bit 값을 ±VMAX 로 환산해야 한다

```cpp
// 틀림 (±200 가정)
motor_spd = uint_to_float(spd_int, -200.0f, 200.0f, 12);

// 맞음 (이 드라이버는 VMAX=30)
motor_spd = uint_to_float(spd_int, -30.0f, 30.0f, 12);
```

**② 위치/속도 명령의 속도 제한** — 상한이 30 rad/s 다. 그 이상 보내도 잘린다.

**③ 위치(±12.5)와 토크(±10)는 매뉴얼과 같으므로 그대로 두면 된다.**

`Config.h` 에 상수로 넣고 하드코딩하지 말 것.

---

## 6. 추가로 알아낸 사실 (같은 삽질 반복 금지)

### S-link 는 필요 없다

S-link 는 USB를 시리얼+CAN 으로 나눠주는 어댑터일 뿐이다(5V, 39×29×10mm).
**파라미터 읽기/쓰기는 시리얼로만 이루어지므로** ESP32 를 USB-시리얼 중계기로
쓰면 대체된다. CAN 연결은 PC에서 모터를 직접 돌리는 "Test" 화면에만 필요하고,
우리는 ESP32 로 돌리니 불필요하다.

근거: 제어 모드는 CAN으로 바꿀 수 없는데(매뉴얼 p41의 CAN 명령은 4개뿐),
CAN ID 가 제어 모드와 같은 `Drive parameters` 그룹에 있다 → 이 화면은 시리얼 경로다.

### CAN 으로는 ID / 제어모드를 바꿀 수 없다

매뉴얼 p41 Universal CAN 명령은 4개뿐이다.

| 명령 | 데이터 |
|---|---|
| Enable | `FF FF FF FF FF FF FF FC` |
| Disable | `FF FF FF FF FF FF FF FD` |
| 현재 위치 영점 | `FF FF FF FF FF FF FF FE` |
| 에러 해제 | `FF FF FF FF FF FF FF FB` |

ID·모드는 드라이버 플래시에 저장되고 상위 SW(시리얼)로만 쓴다.

### baud 는 듣기만 해서 알아낼 수 없다

`serial_probe` 로 8개 baud 전부 시도 → 어디서도 읽을 수 있는 데이터 없음.
`baud_measure` 로 비트폭 측정 → 값이 매번 다름(1000000, 500000, 41666...) = 노이즈였다.
25µs(40kHz) 성분이 반복 등장 → 드라이버 PWM 스위칭 노이즈가 선에 유도된 것.

**결론: baud 는 상위 SW의 `Serial Port` 설정 칸에서 눈으로 확인하는 게 정답이었다.**
(이것도 0-② "드라이버는 먼저 말하지 않는다"의 연장선이다.)

---

## 7. 남은 작업

- [ ] **모터에 라벨 붙이기** — CAN ID 0x02 로 바꾼 모터에 "2번" 표시.
      안 하면 나중에 어느 게 어느 건지 알 수 없다
- [ ] 두 번째 모터는 0x01 그대로 (바꿀 필요 없음)
- [ ] 두 모터를 같은 CAN 버스에 연결하고 개별 제어 확인
      `hardware/MOTOR_HANDOFF.md` 3장의 최소 동작 코드에서 `MOTOR_ID` 를
      `0x01` / `0x02` 로 바꿔가며 한쪽만 움직이는지 확인
- [ ] `Gimbal.cpp` 구현 시 **VMAX = 30** 반영 (5장)
- [ ] 시리얼 배선 노이즈 대책 (1장)
- [ ] `hardware/MOTOR_HANDOFF.md` 의 속도 범위 ±200 → ±30 정정

### 개별 제어 확인 방법

```
모터 #1 (ID 0x01) -> CAN ID 0x101
모터 #2 (ID 0x02) -> CAN ID 0x102

피드백은 둘 다 ID 0x0 로 오지만 Data[0] 하위 4비트가 모터 ID 라서 구분된다.
따라서 Master ID 는 둘 다 0x00 으로 둬도 된다.
```

---

## 부록: 사용한 진단 스케치

`hardware/motor_serial_tools/` 에 있다. 나중에 같은 문제가 생기면 순서대로 쓰면 된다.

| 스케치 | 용도 |
|---|---|
| `serial_bridge` | **PC ↔ 모터 중계 (고정 baud 921600). 실제로 성공한 것** |
| `pin_check` | 핀이 실제로 연결됐는지 판정 (풀업/풀다운 비교). UART 안 씀. 배선이 의심될 때 최단 판정 도구 |

### 만들었지만 리포에 포함하지 않은 것 (기록)

`serial_probe`, `serial_probe2`, `baud_measure`, `serial_bridge_auto` 네 개는
**baud 와 TX 핀을 알아내려고** 만든 도구다. 두 값이 확정됐으므로 제외했다.

특히 `serial_probe` / `baud_measure` 계열 — 드라이버가 스스로 보내는 출력을 잡아
baud 를 역산하는 접근 — 은 **이 드라이버에서는 원리적으로 불가능하다** (6장 참고).
**같은 시도를 반복하지 말 것.**

---

## 부록 B: 배경 개념 (처음 보는 사람용)

### 이 모터는 "말을 알아듣는 모터"다

보통 모터는 전선에 전기를 흘리면 돕니다. GL60II는 모터 뒤에 **작은 컴퓨터 보드(드라이버)**
가 붙어 있어서, 전기를 그냥 흘리는 게 아니라 **문장으로 명령을 보내야** 합니다.

> "3라디안 위치로 가라, 속도는 1rad/s로"

이걸 전기 신호로 만들어 보내면 드라이버가 알아듣고 알아서 그 각도까지 돌립니다.

### 대화 통로가 두 개 있다

드라이버 보드에 **꽂는 구멍(= 커넥터)이 두 개** 있습니다.

```
        +------------------------------+
        |    GL60II 드라이버 보드        |
        |                              |
        |   [#] (1)번 구멍 - 작은 3핀   |  ← 설정용 (시리얼)
        |                              |
        |   [#] (2)번 구멍 - 큰 XT30    |  ← 전원 + 조종용 (CAN)
        +------------------------------+
```

| 번호 | 커넥터 | 핀 구성 | 용도 |
|---|---|---|---|
| (1) | 작은 3핀 (CJT A1257, 1.25mm 간격) | GND / TX / RX | **설정** 변경 |
| (2) | 큰 XT30(2+2) | 전원+ / 전원− / CAN_H / CAN_L | 전원 공급 + **조종** |

### CAN = 단체 카톡방

CAN은 **전선 딱 두 가닥을 여러 장치가 공유**하는 통신입니다.

```
   ESP32 --+---------+---------+---- 전선 2가닥 (CAN_H, CAN_L)
           |         |         |
         모터1     모터2    (나중에 더)
```

전선이 하나뿐이니 메시지 앞에 **이름표(ID)** 를 붙입니다. 모터들은 흐르는 메시지를
전부 듣지만 **자기 이름표가 붙은 것만 실행**합니다.
단체 카톡방에서 "@철수 이거 해줘" 하면 철수만 반응하는 것과 같습니다.

장점: 모터가 10개여도 전선은 2가닥이면 됩니다.

### 시리얼(UART) = 1:1 면담

시리얼은 **장치 두 개를 일대일로 직접 연결**하는 방식입니다. 이름표 개념이 없고,
선으로 연결된 상대와만 대화합니다.

우리 경우엔 **PC와 모터 드라이버를 직접 연결**할 때 씁니다. ESP32는 여기 안 끼어듭니다.

### 용도 정리

| | CAN — (2)번 구멍 | 시리얼 — (1)번 구멍 |
|---|---|---|
| 하는 일 | **조종** "움직여라" | **설정** "이름을 2번으로 바꿔라" |
| 연결 | ESP32 ↔ 모터 | PC ↔ 모터 |
| 사용 시점 | 로봇 동작 중 계속 | 처음 한 번, 설정할 때만 |

### 헷갈리는 용어 두 개

**TWAI** = ESP32 칩 안에 들어있는 **CAN 통신 담당 회로의 이름**.
그냥 "ESP32의 CAN 기능"으로 읽으면 됩니다. (Espressif가 상표 문제로 CAN이라 안 부릅니다)

**트랜시버 (SN65HVD230)** = **통역사**.
ESP32는 3.3V로 신호를 만드는데 CAN 전선 위의 신호는 생김새가 다릅니다(두 선의
전압 차이로 0/1 표현). 그 사이를 변환해주는 작은 부품입니다.

```
  ESP32 --(3.3V 신호)-- 트랜시버 --(CAN 신호)-- 모터
        내부 언어           통역          외부 언어
```

### 커넥터 규격 주의

(1)번 구멍은 **1.25mm 간격**입니다. 브레드보드용 흔한 점퍼선(2.54mm)은
**간격이 두 배라서 안 들어갑니다.** 이거 모르고 시도하다 포기하는 경우가 많습니다.

```
   1.25mm 간격        2.54mm 간격
   ###                #  #  #
   ↑ 드라이버          ↑ 흔한 듀폰 점퍼
```

검색어: `GH1.25 3핀 케이블` / `1.25mm 3P 하네스` / `JST GH 3핀`
(CJT A1257은 JST GH와 호환됩니다. 디바이스마트, 엘레파츠 등에서 판매)

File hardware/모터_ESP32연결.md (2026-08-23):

# 모터 ESP32 연결 방법

**1. 모터에 원래 딸려온 케이블 확인**

한쪽 끝은 모터 보드에 이미 꽂혀있는 XT30(2+2) 커넥터, 반대쪽 끝은 피복 벗겨진 4가닥(빨강/검정/흰색/파랑)입니다.

- 빨강 = 전원 +
- 검정 = 전원 −
- 흰색 = CAN_H
- 파랑 = CAN_L

(흰색/파랑 중 어느 게 H인지 L인지는 반대로 연결해도 고장나지 않고 그냥 통신이 안 될 뿐이니, 안 되면 나중에 서로 바꿔보면 됩니다. 극성 있는 빨강/검정만 조심하면 돼요.)

**2. 전원 연결**

- 전원공급기 전압 24V로 맞추기 (허용범위 8~32V)
- 전류 제한 있으면 1~2A 정도로 낮게 설정
- 악어클립: 빨강 → 전원 +, 검정 → 전원 −
- 아직 전원 켜지 마세요, 배선 다 끝난 다음에 켤 겁니다

**3. CAN 트랜시버 배선**

- 모터 케이블의 흰색 → 트랜시버의 CANH
- 모터 케이블의 파랑 → 트랜시버의 CANL
- 트랜시버 VCC → ESP32-S3의 3V3 핀 (트랜시버가 3.3V 호환인 경우)
- 트랜시버 TXD → ESP32 아무 GPIO (예: GPIO4) — 나중에 코드에서 TWAI TX로 지정
- 트랜시버 RXD → ESP32 아무 GPIO (예: GPIO5) — 코드에서 TWAI RX로 지정

**4. 종단저항(100Ω) 연결**

트랜시버의 CANH-CANL 단자 사이에 그 100Ω 저항 다리를 양쪽에 걸쳐서 연결 (납땜하거나, 브레드보드 쓰면 그냥 꽂으면 됨)

**5. 그라운드 공통 연결 (제일 중요, 빼먹으면 안 됨)**

검정선(전원 −) ↔ 트랜시버 GND ↔ ESP32 GND, 이 세 군데를 전부 한 군데로 묶기

**6. 전원 켜기**

- 전원공급기 켜고 모터 보드 표시등 확인: 초록불(Enable) 켜지는지, 빨간불(Malfunction) 깜빡이지 않는지

- 이상 없으면 배선 완료

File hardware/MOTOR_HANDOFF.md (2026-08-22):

# GL60II 모터 구동 핸드오프 문서 (검증 완료: 2026-08-22)

## 1. 하드웨어 구성 (확정)
- MCU: **ESP32-S3** (Arduino IDE, 내장 TWAI 컨트롤러 사용)
- CAN 트랜시버: **SN65HVD230** (3.3V, VCC→3V3)
- 모터: **CubeMars GL60II KV28 + 전용 드라이버**
- 배선: 트랜시버 TXD→**GPIO4**, RXD→**GPIO5**, CANH↔흰색, CANL↔파랑,
  종단저항 100Ω CANH-CANL 사이, **GND 공통 필수** (전원− ↔ 트랜시버 GND ↔ ESP32 GND)
- 전원: 24V, 전류 제한 **최소 2A** (1A는 방향 전환 피크에 컷오프됨 — 실측)

## 2. CAN 프로토콜 (매뉴얼 `hardware/gl-ii-gimbal-motor-drive-user-manual.pdf` p.41~49에서 추출, 실기 검증됨)
- **표준 11-bit 프레임, 1Mbps 고정** (`TWAI_TIMING_CONFIG_1MBITS()`)
- CAN ID = `(제어모드 << 8) | 모터ID`
  - 모드 0 = MIT, 모드 1 = 위치/속도, 모드 2 = 속도
- **⚠️ 제어 모드는 CAN으로 변경 불가** — 드라이버 플래시에 저장, 상위 PC 툴(시리얼)로만 변경
- **현재 우리 드라이버 설정 (스캔으로 확정): 모드 1 (위치/속도), 모터 ID = 1, 피드백 ID(Master ID) = 0x0**
  - → 모든 명령은 **ID `0x101`** 로 전송

### 공통 명령 (DLC=8, ID=0x101)
| 명령 | 데이터 |
|---|---|
| Enable | `FF FF FF FF FF FF FF FC` |
| Disable | `FF FF FF FF FF FF FF FD` |
| 현재 위치 영점 | `FF FF FF FF FF FF FF FE` |
| 에러 해제 | `FF FF FF FF FF FF FF FB` |

### 위치/속도 명령 (DLC=8, ID=0x101)
- Data[0..3] = 목표 위치 (IEEE754 **float, little-endian**, 범위 ±12.5 rad)
- Data[4..7] = 속도 제한 (float LE, 범위 ±200 rad/s)

### 피드백 프레임 (ID=0x0)
- Data[0]: 상위니블=상태코드, 하위니블=모터ID
  - 0=Disable, 1=Enable, 8=과전압, 9=저전압, A=과전류, B=MOS과열, C=권선과열, D=통신끊김, E=과부하
- Data[1..2]: 위치 16bit → `raw*25.0/65535 - 12.5` rad
- Data[3..4]: 속도 12bit(±200), Data[4하위..5]: 토크 12bit(±10)
- Data[6]/Data[7]: 드라이버/모터 온도 (int8, °C)

## 3. 검증된 최소 동작 코드 (0.5초 왕복)
```cpp
#include "driver/twai.h"
#define MOTOR_ID 0x01
#define POS_RAD  0.5f   // 살살: ±0.5 rad
#define VEL_LIMIT 1.0f  // 살살: 1 rad/s

void sendPosVel(float pos, float vel) {
  twai_message_t m = {};
  m.identifier = 0x100 | MOTOR_ID;
  m.data_length_code = 8;
  memcpy(&m.data[0], &pos, 4);
  memcpy(&m.data[4], &vel, 4);
  twai_transmit(&m, pdMS_TO_TICKS(10));
}
void sendUniversal(uint8_t last) {
  twai_message_t m = {};
  m.identifier = 0x100 | MOTOR_ID;
  m.data_length_code = 8;
  memset(m.data, 0xFF, 7); m.data[7] = last;
  twai_transmit(&m, pdMS_TO_TICKS(10));
}
void setup() {
  Serial.begin(115200);
  twai_general_config_t g = TWAI_GENERAL_CONFIG_DEFAULT(GPIO_NUM_4, GPIO_NUM_5, TWAI_MODE_NORMAL);
  twai_timing_config_t  t = TWAI_TIMING_CONFIG_1MBITS();
  twai_filter_config_t  f = TWAI_FILTER_CONFIG_ACCEPT_ALL();
  twai_driver_install(&g, &t, &f); twai_start(); delay(100);
  sendUniversal(0xFB); delay(50);  // 에러 해제
  sendUniversal(0xFE); delay(50);  // 영점
  sendUniversal(0xFC); delay(100); // enable
}
void loop() {
  static bool dir = true; static uint32_t last = 0;
  if (millis() - last >= 500) { last = millis(); dir = !dir; }
  sendPosVel(dir ? POS_RAD : -POS_RAD, VEL_LIMIT);
  twai_message_t rx;
  while (twai_receive(&rx, 0) == ESP_OK)
    Serial.printf("상태=%X pos=%.2f\n", rx.data[0]>>4,
                  ((float)((rx.data[1]<<8)|rx.data[2]))*25.0f/65535.0f-12.5f);
  delay(20);
}
```

## 4. 삽질 로그 (같은 실수 반복 금지)
1. ❌ AK시리즈용 **확장 29-bit + ERPM int32** 프로토콜 → GL II는 완전히 다름 (표준 11-bit + float)
2. ❌ RMD식 `0x140+ID / 0xA1/0xA2` 프로토콜 → GL II 아님
3. ❌ 속도 모드(`0x201`) 명령 → 드라이버가 위치/속도 모드로 설정돼 있어 무시됨
4. ✅ **모드/ID 불명확할 땐 스캔**: 모드 0~2 × ID 0~127에 enable을 쏘고 피드백이 오는 조합을 찾으면 확정됨
5. 진단 순서: TWAI `state=1`+에러0 → 물리층 OK / `twai_transmit`이 ESP_OK(ACK) → 비트레이트 OK / 피드백 무응답 → 프레임 내용(모드/ID) 문제

## 5. 다음 단계
- 이 프로토콜을 팀 규약(`docs/ai-handoff/MOTOR_CAN_TASK.md`)대로 `firmware/gimbal_control/Gimbal.h/.cpp`의 `GimbalBus` 클래스로 이식
- 핀/ID/제한값은 `Config.h`에서 읽기 (하드코딩 금지)
- 두 번째 모터 추가 시 CAN ID 분리 필요 (PC 툴로 설정)

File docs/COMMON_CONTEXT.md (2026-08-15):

# Liquid Control Robot 공통 작업 규약

이 문서는 세 명의 팀원과 각 팀원이 사용하는 AI가 공유하는 프로젝트 기준입니다. 역할별 작업을 시작하기 전에 이 문서와 본인의 역할 문서를 순서대로 제공합니다.

## 프로젝트 목표

하부 IMU로 이동 베이스의 자세와 가속도를 측정하여 액체에 작용하는 합력 방향을 계산하고, 트레이가 합력 벡터에 수직하도록 목표 자세를 생성합니다. 상부 IMU는 실제 트레이 자세를 측정하며 외부 P 제어기는 추종 오차를 보정합니다. ZV 입력성형기는 이동 명령으로 발생하는 잔류 슬로싱을 줄입니다.

1D CNN은 제어기가 아니라 슬로싱 주파수 추정기입니다. 학습 데이터와 검증된 모델이 준비되기 전에는 고정 주파수 ZV를 사용합니다.

## 시스템 경계

```text
하부·상부 IMU
    ↓
Sensor: 센서 읽기와 물리 단위 변환
    ↓
Control: 합력 목표각 → P → ZV
    ↓
Gimbal: GL60II CAN 명령·피드백
    ↓
GL60II 내장 드라이버: 위치·속도·전류 제어
```

- MCU는 ESP32-S3-DevKitC-1-N16R8V를 사용합니다.
- 모터는 GL60II 두 대를 사용합니다.
- ESP32-S3의 TWAI와 외부 CAN 트랜시버로 모터 버스에 연결합니다.
- GL60II의 실제 모드와 CAN ID는 초기 설정 과정에서 확인한 뒤 `Config`에 반영합니다.
- 두 IMU의 모델과 핀 배치는 확정 후 `Config`에 반영합니다.

## Config 단일 설정 원칙

핀, 센서 종류, 통신 설정, 제어주기, 축 방향과 안전 제한은 `Config.h/.cpp`에서만 정의합니다. 다른 파일은 값을 직접 선언하거나 숫자로 하드코딩하지 않고 `Config.h`를 포함하여 사용합니다.

```cpp
#include "Config.h"
```

Config가 제공해야 할 설정 범주는 다음과 같습니다. 실제 이름과 자료형은 공용 인터페이스를 확정할 때 정합니다.

```text
CAN_TX_GPIO, CAN_RX_GPIO, CAN_BITRATE
SPI_SCK_GPIO, SPI_MISO_GPIO, SPI_MOSI_GPIO
BASE_IMU_CS_GPIO, TRAY_IMU_CS_GPIO
BASE_IMU_TYPE, TRAY_IMU_TYPE
MOTOR_X_CAN_ID, MOTOR_Y_CAN_ID, MASTER_CAN_ID
CONTROL_PERIOD_US
MOTOR_POSITION_LIMIT_RAD, MOTOR_VELOCITY_LIMIT_RAD_S
FEEDBACK_TIMEOUT_MS, SENSOR_TIMEOUT_US
MOTOR_X_DIRECTION, MOTOR_Y_DIRECTION
MOTOR_X_ZERO_OFFSET_RAD, MOTOR_Y_ZERO_OFFSET_RAD
```

- 모터·센서 담당자는 필요한 설정항목을 통합 담당자에게 제안합니다.
- `Config.h/.cpp`는 통합 담당자만 수정합니다.
- 설정값이 확정되지 않은 경우 담당 파일에 임시 숫자를 넣지 않고 미확정 사항으로 보고합니다.
- 데이터시트로 확인되는 통신 규격과 실험으로 정해야 하는 배선·축 설정을 구분합니다.

## 파일 소유권

| 담당 | 수정 가능 파일 | 책임 |
|---|---|---|
| 모터·CAN | `Gimbal.h/.cpp` | TWAI, GL60II 명령·피드백 |
| 센서·데이터 | `Sensor.h/.cpp`, 승인된 `data/` 파일 | 이중 IMU, 물리 단위 데이터 |
| 제어·통합 | `Control.h/.cpp`, `Config.h/.cpp`, `gimbal_control.ino` | 목표각, P, ZV, 상태기계 |

- 담당자는 자신의 전담 파일만 수정합니다.
- 공용 자료형이나 공개 함수 변경은 세 담당자가 합의한 뒤 별도 변경으로 처리합니다.
- 다른 모듈의 내부 변수에 직접 접근하지 않고 공개 함수만 사용합니다.
- 새 파일 생성, 공용 파일 변경, Git 작업은 팀의 변경 절차에 따라 별도로 합의합니다.

## 공용 데이터 계약

다음은 모듈 사이에서 교환해야 하는 최소 정보입니다. 실제 공용 헤더를 만들기 전까지 역할별 AI가 서로 다른 단위나 중복 자료형을 임의로 만들지 않습니다.

```cpp
struct MotorFeedback {
    float positionRad;
    float velocityRadS;
    float torqueNm;
    int8_t driverTemperatureC;
    int8_t motorTemperatureC;
    uint8_t errorCode;
    uint32_t receivedAtMs;
    bool valid;
};

struct ImuSample {
    float axMps2;
    float ayMps2;
    float azMps2;
    float gxRadS;
    float gyRadS;
    float gzRadS;
    uint32_t sampledAtUs;
    bool valid;
};

struct ImuPair {
    ImuSample base;
    ImuSample tray;
};

struct ControlOutput {
    float xPositionRad;
    float yPositionRad;
    float maxVelocityRadS;
    bool enable;
};
```

내부 각도는 rad, 각속도는 rad/s, 가속도는 m/s², 토크는 N·m를 사용합니다. 사람이 읽는 출력에서 degree를 사용할 때는 필드명에 단위를 명시합니다.

## 안전 원칙

- 부팅 직후 모터를 자동 활성화하거나 자동 영점 설정하지 않습니다.
- 초기 모터 시험은 무부하 소각도에서 수행합니다.
- 위치·속도·제어 출력은 Config의 안전 제한을 적용합니다.
- 모터 피드백이나 IMU 값이 유효하지 않으면 신규 이동 명령을 생성하지 않습니다.
- 통신 모듈은 상태를 보고하고, 전체 비활성화 정책은 통합 상태기계가 결정합니다.
- 센서 축과 모터 방향은 추측하지 않고 축별 시험 후 Config에 기록합니다.
- 데이터시트에 없는 프로토콜, 레지스터, 핀 특성을 추측하지 않습니다.

## 개발 순서

1. GL60II 한 대 CAN 통신
2. GL60II 두 대 독립 통신
3. 이중 IMU 단독·동시 읽기
4. 합력 방향과 목표각 생성
5. 외부 P 제어
6. 고정 주파수 ZV
7. 데이터 수집과 1D CNN 검증
8. 검증된 CNN 주파수로 ZV 갱신

이번 구현에서 ESO, LQR, MPC는 제외합니다.

## AI 작업 공통 지시

- 제공된 자료를 먼저 읽고 현재 상태와 불확실한 부분을 보고합니다.
- 변경 전에 대상 파일, 변경 내용, 이유와 영향을 설명하고 팀원의 승인을 받습니다.
- 맡지 않은 파일은 수정하지 않습니다.
- Config에 있어야 할 값을 담당 파일에 하드코딩하지 않습니다.
- 컴파일·시험·Git 작업은 팀원의 승인을 받은 범위에서만 수행합니다.
- 종료 시 변경 파일, 검증 결과, 실제 장비에서 확인할 항목을 보고합니다.

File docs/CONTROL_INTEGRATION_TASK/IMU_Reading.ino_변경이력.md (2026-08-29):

# IMU_Reading.ino 변경 이력

[`IMU_Reading.ino`](IMU_Reading.ino) — 트레이 IMU(LSM6DSOX) 기울기 측정 코드의
작성 및 수정 기록. (2026-08-26)

| 푸시 시각 | 커밋 | 내용 |
|---|---|---|
| 2026-08-26 22:14 | `6f8df5f` | [최초 작성 — BMI160 코드에서 LSM6DSOX 로 이식](#1-최초-작성-6f8df5f) |
| 2026-08-26 22:52 | `369ac00` | [연속 무보정 구간 추적 + 파워다운 즉시 감지](#3-연속-구간-추적-추가-369ac00) |
| 2026-08-26 23:07 | `90e3c8c` | [가속도 신뢰도 가중 방식 전환 + ±4g 상향](#5-신뢰도-가중-전환-90e3c8c) |
| 2026-08-26 23:33 | `b7e41eb` | [중력 스케일 부팅 정규화 + 2차 벤치 테스트 기록](#7-중력-스케일-정규화-b7e41eb) |
| 2026-08-26 23:39 | `9763260` | [3차 벤치 테스트 기록 — IMU 읽기 단계 종료](#8-3차-벤치-테스트--정규화-검증-및-최종-확인) |
| 2026-08-26 23:44 | `f3d9854` | [정지 노이즈 원인 정정 — 모터 진동 아닌 손 떨림](#6-2차-벤치-테스트-신뢰도-가중--4g) |
| 2026-08-26 23:46 | `d74166c` | 작업기록.md → IMU_Reading.ino_변경이력.md 개명 |
| 2026-08-29 21:24 | `2369911` | 푸시 시각 컬럼 추가 |
| 2026-08-29 21:32 | `40b7384` | 표 항목에 본문 절 링크 연결 |

---

## 1. 최초 작성 (`6f8df5f`)

기존 서보 구조 코드에서 상보 필터, 자이로 영점 캘리브레이션, 100Hz 루프 구조를
가져오고 센서와 핀을 교체.

### 핀 변경

기존 코드의 SPI 핀은 ESP32-S3 에서 사용 불가.

| 기존 | 문제 | 변경 |
|---|---|---|
| `SDI_PIN = 23` | **S3 에 GPIO 22~25 자체가 없음** | `11` (MOSI) |
| `SDO_PIN = 19` | USB D− | `13` (MISO) |
| `SCK_PIN = 18` | UART 로 재배정됨 | `12` (SCK) |
| `CS_ACTIVE = 5` | CAN 으로 재배정됨 | `10` |

IMU 보드 라벨이 I2C 표기(`SDA`/`SCL`/`SDO`)지만 SPI 4-wire 에서는
`SDA` = MOSI, `SCL` = SCK, `SDO` = MISO 로 동작.

### 센서 변경 (BMI160 → LSM6DSOX)

| 항목 | BMI160 | LSM6DSOX |
|---|---|---|
| 데이터 주소 | `0x0C` | `0x22` |
| WHO_AM_I | `0x00` → `0xD1` | `0x0F` → `0x6C` |
| **`GYRO_LSB`** | 16.4 | **14.286** |
| 전원 시퀀스 | `0x7E` 커맨드 반복 | `CTRL3_C` 리셋 1회 |

> `GYRO_LSB` 주의. 16.4 는 ICM/MPU 계열 값이고 LSM6DSOX 는 70 mdps/LSB 라
> 14.286 이다. 안 바꾸면 에러 없이 각속도가 15% 작게 나온다.

바이트 순서(리틀엔디안, 자이로 먼저)는 BMI160 과 동일해 파싱 로직 재사용.

### 이때 추가한 방어 로직

디버깅 과정(아래 2절)에서 확인된 문제에 대응해 3가지를 함께 넣었다.

1. **부팅 진단** `dumpDiag()` — WHO_AM_I / CTRL 레지스터 / raw 12바이트 덤프
2. **리셋 감지 및 복구** — `CTRL1_XL` 이 변하면 재초기화
3. **`|a|` 검사** — 1g 를 벗어난 샘플은 가속도 보정 제외

---

## 2. 디버깅 이력

### 증상 1 — `pitch_acc` 가 `0.00` / `35.26` 두 값만 출력

```
pitch:6.82,pitch_acc:35.26,roll:6.20,roll_acc:-35.26
pitch:17.57,pitch_acc:0.00,roll:14.90,roll_acc:0.00
```

`arctan(1/√2) = 35.264°` 이므로 **ax = ay = az** 일 때만 나오는 값.
포화가 아니라 **데이터가 아예 안 들어오는 상태**였다.

```cpp
pitch_acc = atan2(ay, sqrt(ax² + az²))    // ax=ay=az=k 면 항상 35.26°
```

각도가 365° 까지 발산한 것은 원인이 아니라 결과였다. 가속도계가 죽으면
상보 필터가 절대 기준을 잃고 순수 자이로 적분이 되기 때문.

→ 배선 수정 후 해결. 이 판별을 자동화하기 위해 `dumpDiag()` 추가.

### 증상 2 — 잘 되다가 갑자기 깨짐

```
pitch:-52.50,pitch_acc:-52.49    ← 정지 상태, 0.01° 일치
pitch:-52.52,pitch_acc:-52.98    ← 여기까지 정상
pitch:-51.65,pitch_acc:-48.79    ← 움직이기 시작
pitch:-54.04,pitch_acc:-72.09    ← 즉시 깨짐
```

정지 상태에서는 완벽했고 **움직인 순간부터** 깨졌다. 설정 문제가 아닌 간헐적 오류.
`pitch_acc` 가 정확히 `0.00` 인 구간은 센서 리셋(파워다운) 신호.

→ 리셋 감지 및 복구 로직이 이 문제의 핵심 대응이었다. 이전에는 리셋 한 번에
센서가 파워다운으로 영구 방치되어 세션이 죽었다 (증상 1의 365° 발산이 그것).
복구 로직 추가 후 자가 회복되어 장시간 안정 동작.

### 증상 3 — 거부 카운터로 판단이 안 됨

```
[stat] reset:1  bit_err:1999 / 12323 (16.2%)
```

통신 오류인지 실제 움직임인지 구분 불가. 카운터가 두 원인을 섞어 세고 있었다.

또한 거부 **개수**보다 **연속 길이**가 중요하다는 점이 반영되지 않았다.
샘플을 버리면 그 순간 자이로 단독 적분이 되는데, 흩어져 있으면 무해하고
뭉치면 각도가 틀어진다. (1샘플 = 0.01초)

---

## 3. 연속 구간 추적 추가 (`369ac00`)

### ① 연속 무보정 구간 추적

```cpp
if (acc_ok) {
  rej_run = 0;
} else {
  if (++rej_run > rej_run_max) rej_run_max = rej_run;
}
```

| 최대연속 | 자이로 단독 시간 | 판정 |
|---|---|---|
| ≤ 5 | 0.05초 | 무해 |
| ~50 | 0.5초 | 드리프트 발생 |

### ② 파워다운 즉시 감지

기존에는 `CTRL1_XL` 을 1초 주기로만 확인해 리셋 시 최대 1초간 방치됐다.
`|a|` 가 0 에 가까우면 파워다운 신호이므로 그 자리에서 복구하도록 변경.

```cpp
if (a_mag < ACC_MAG_DEAD && readReg(REG_CTRL1_XL) != CTRL1_XL_VAL) {
  err_reset++;
  configSensor();
}
```

---

## 4. 1차 벤치 테스트 (하드 컷 / ±2g)

| 조건 | 결과 | 판정 |
|---|---|---|
| **정지** | 오류 **0 / 304** | 배선 정상 ✅ |
| 가볍게 움직임 | 최대연속 7~8 (0.08초) | 무해 ✅ |
| 격하게 흔듦 | 최대연속 **44** (0.44초), `\|a\|` **2.77g** | 문제 ❌ |

**정지 시 오류 0** — 이전의 16% 는 전부 실제 움직임이었고 하드웨어는 정상이었다.

격한 동작에서 두 가지 문제 확인.

1. `|a| = 2.77g` → **±2g 범위 포화**
2. 0.44초 연속 무보정 → 자이로 단독 적분으로 `roll` 이 -103° 까지 붕괴

로봇 주행 시 출발·정지에서 동일 상황이 발생하므로 제어 진입 전 수정 필요.

> 로그 해석 주의점도 발견. `최대연속` 이 부팅 이후 최고 기록이라 한 번 올라가면
> 안 내려가는데, 이를 "지금도 계속 빠지는 중" 으로 오해할 수 있었다.
> `bit_err` 가 122 에서 멈춰 있었던 것이 실제로는 정상이라는 증거였다.

---

## 5. 신뢰도 가중 전환 (`90e3c8c`)

### ① 측정 범위 ±2g → ±4g

```cpp
#define CTRL1_XL_VAL  0x68      // ±4g  (기존 0x60 = ±2g)
const float G_LSB = 8192.0;     // 기존 16384.0
```

### ② 하드 컷 → 신뢰도 가중

버리면 연속 구간이 생기므로, **버리지 않고 비중만 줄인다.**

```cpp
float dev   = fabsf(a_mag - 1.0f);
float trust = constrain(1.0f - dev / ACC_TRUST_FALLOFF, 0.0f, 1.0f);
float alpha = 1.0f - (1.0f - alpha_cf) * trust;

pitch_filtered = alpha*(pitch_filtered + rate_pitch*dt) + (1.0f-alpha)*pitch_acc;
```

| `\|a\|` | trust | 동작 |
|---|---|---|
| 1.00g | 1.00 | 평소대로 보정 |
| 1.25g | 0.50 | 절반만 반영 |
| 1.50g+ | 0.00 | 자이로 단독 |

가속 중에도 가속도계가 완전히 입을 다물지 않아 드리프트 누적이 줄어든다.
이 로직은 통신 오류 차단과 **선형 가속으로 인한 기울기 오염 방지**를 동시에
수행하므로 짐벌 제어 진입 후에도 유지할 것.

### ③ 진단 로그를 구간 기준으로

누적 표시는 한 번 튄 값이 계속 남아 오해를 만들었다. 직전 1초 구간 기준으로
바꾸고, 연속 길이는 최근/전체를 함께 표시.

```
[stat] reset:0  무보정:0/101  연속:0최근/44전체  |a|=1.01 trust=1.00
```

---

## 6. 2차 벤치 테스트 (신뢰도 가중 / ±4g)

### 결과 — 전 항목 개선 확인

| 조건 | 1차 (하드 컷 / ±2g) | 2차 (가중 / ±4g) | 개선 |
|---|---|---|---|
| 정지 — `pitch_acc` 흔들림 | 0.15° | **0.25°** | 동등 (정상) |
| 가볍게 기울임 — 최대연속 | 14 | **0** | 완전 해소 |
| 격하게 흔듦 — 최대연속 | 44 (0.44초) | **12 (0.12초)** | **3.7배 단축** |
| 격하게 흔듦 — `\|a\|` | 2.77g (포화) | **3.21g (포화 없음)** | 해소 |

가볍게 기울이는 구간에서 `trust` 가 0.82~0.90 으로 부드럽게 내려가며
**한 샘플도 버리지 않았다.** 격한 동작에서도 무보정 구간이 12샘플 이하로
짧게 끊겨 이전처럼 각도가 -103° 로 붕괴하지 않았다.

### 정지 상태 노이즈 원인 = 손 떨림 (센서를 들고 있었음)

정지 상태 `pitch_acc` 흔들림 폭 비교.

| 조건 | 흔들림 폭 | 통신 오류 |
|---|---|---|
| 센서를 손에 들고 정지 | **9.56°** | 0 |
| 센서를 바닥에 내려놓고 정지 | **0.25°** | 0 |

통신 오류는 양쪽 다 0 이므로 데이터는 정상이었고, **센서가 실제로 흔들린 것**이다.
원인은 손 떨림. 가만히 들고 있어도 미세 진동이 그대로 측정된다.

> **진동은 신뢰도 가중으로 걸러지지 않는다.**
> 옆방향 진동 0.087g 는 각도를 5° 흔들지만 크기는
> `√(1² + 0.087²) = 1.004g` 로 거의 그대로라 `|a|` 검사를 통과한다.
>
> 진동원이 손이든 모터든 동일하게 적용되는 특성이므로, 실장 후 진동이
> 확인되면 방진 마운트(고무 부싱·실리콘 그로밋)를 검토할 것.

> **초기 오판 기록.** 이 노이즈를 처음에 모터 진동으로 결론냈으나 오류였다.
> 노이즈가 사라진 측정에서 모터 전원이 꺼져 있었던 것은 사실이나, 같은 측정에서
> 센서를 손에서 내려놓은 변화가 함께 있었다. 교란 변수가 둘인 비교를 근거로
> 인과를 단정한 것. **모터 진동의 영향은 아직 측정된 바 없다.**

### 잔여 항목 — 중력 스케일 편차

```
|a|=0.97 trust=0.94
```

정지 상태인데 `trust` 가 1.00 이 아니었다. 가속도계가 1g 를 0.97g 로 3% 낮게
읽는 개체 편차 때문. 센서 스펙 범위 내지만 두 가지 부작용이 있다.

- 정지 시에도 가속도계를 94% 만 반영
- 신뢰도 감쇠 기준이 실제 1g 가 아닌 0.97g 에서 출발

→ 아래 7절에서 정규화로 해결.

---

## 7. 중력 스케일 정규화 (`b7e41eb`)

부팅 캘리브레이션에서 자이로 영점을 잴 때 정지 상태 `|a|` 도 함께 측정해
그 값으로 정규화한다.

```cpp
// setup() — 200회 루프에서 함께 누적
smag += sqrtf(fax*fax + fay*fay + faz*faz) / G_LSB;
...
float measured = smag / 200.0;
if (measured > 0.5f && measured < 1.5f) g_scale = measured;   // 이상값이면 생략

// loop()
float a_mag = sqrtf(...) / G_LSB / g_scale;    // 정지 시 정확히 1.000
```

캘리브레이션 중 센서를 움직이면 엉뚱한 값이 잡히므로 0.5~1.5 범위를
벗어나면 정규화를 건너뛰고 `g_scale = 1.0` 을 유지한다.

부팅 로그에 측정값이 찍힌다.

```
gyro bias  x:-12.3  y:5.7   g_scale:0.9712
```

---

## 8. 3차 벤치 테스트 — 정규화 검증 및 최종 확인

### 정지 상태에서 `trust = 1.00` 달성

```
[stat] reset:0  무보정:0/101  연속:0최근/0전체  |a|=1.00 trust=1.00
```

| 항목 | 정규화 전 | 정규화 후 |
|---|---|---|
| `\|a\|` | 0.97 | **1.00** |
| `trust` | 0.94 | **1.00** |
| `pitch` 변동 | — | **0.03°** (67.92 ~ 67.95) |
| `pitch_acc` 흔들림 | 0.25° | 0.34° |

가속도계를 100% 활용하게 됐고 신뢰도 감쇠 기준도 실제 1g 에서 출발한다.

### 축·부호 검증 통과

자이로 부호가 반대면 필터가 가속도계와 반대로 튀거나 발산하는데,
움직이는 동안 두 값이 같은 방향으로 움직이고 정지 시 다시 일치했다.

```
pitch:10.82,pitch_acc:15.44     ← 같이 상승
pitch:62.05,pitch_acc:61.64
pitch:67.92,pitch_acc:67.91     ← 정지 후 일치
```

roll 도 `-27 → +9` / `roll_acc` `-21 → +3.8` 로 동일. **두 축 모두 정상.**

### 전체 추이

| 조건 | 1차 (하드컷/±2g) | 2차 (가중/±4g) | 3차 (+정규화) |
|---|---|---|---|
| 정지 `trust` | — | 0.94 | **1.00** |
| 조금씩 — 최대연속 | 14 | 0 | 3 (0.03초) |
| 많이 — 최대연속 | **44** (0.44초) | 12 | **14** (0.14초) |

3차의 14는 2차의 12와 흔든 강도 차이 수준이며, 1차의 44 대비 약 1/3 로
안정화된 상태가 유지된다.

**IMU 읽기 단계는 검증 완료.** 이후 작업은 실장(방진·배선)과 제어 연동이다.

---

## 현재 설정 요약

| 항목 | 값 |
|---|---|
| 센서 | LSM6DSOX, SPI 1MHz MODE0 |
| 핀 | MOSI 11 / SCK 12 / MISO 13 / CS 10 |
| 가속도 | ±4g, ODR 416Hz, `G_LSB` 8192.0 |
| 자이로 | ±2000dps, ODR 416Hz, `GYRO_LSB` 14.286 |
| 제어 루프 | 100Hz (`dt` 0.01) |
| 상보 필터 | `alpha_cf` 0.98 |
| 신뢰도 감쇠 | `ACC_TRUST_FALLOFF` 0.5 |
| 중력 정규화 | `g_scale` — 부팅 시 자동 측정 (실측 0.97) |
| 출력 | 10Hz, 시리얼 플로터 포맷 |

---

## 검증 완료 항목 — IMU 읽기 단계 종료

- [x] 배선 정상 — 정지 시 통신 오류 0
- [x] 신뢰도 가중 효과 — 최대연속 44 → 12~14 (0.44초 → 0.14초)
- [x] ±4g 상향 유효 — 3.21g 포화 없이 측정
- [x] 정지 노이즈 원인 규명 — 손 떨림 (들고 9.56° / 내려놓고 0.25°)
- [x] 중력 정규화 — 정지 시 `trust = 1.00`
- [x] 축·부호 검증 — pitch / roll 양축 자이로 부호 정상
- [x] 물리 부호 방향 확정 (2026-08-27) — `+pitch` = +Y축 상승, `+roll` = +X축 하강.
      예상과 실측 일치, 코드 부호 반전 불필요. 상세는 [README](README.md)

## 다음 단계

- [ ] **모터 진동 영향 측정** — 센서를 고정한 상태에서 모터 전원 ON/OFF 비교 (미측정)
- [ ] 진동이 확인되면 트레이 IMU 방진 마운트 적용
- [ ] 트레이 IMU 를 짐벌 회전부에 실장 (연선·차폐·서비스 루프)
- [ ] 베이스 IMU (CS = GPIO9) 추가 → 이중 IMU 차동 센싱 복원
- [ ] 합력 벡터 목표각 산출 (논문 Phase 2) 이식
- [ ] roll 축에도 ZV 적용 — 이전 구조의 누락 사항
- [ ] CAN 짐벌모터 제어 연동
- [ ] `|a|` 가 3.9g 를 넘으면 ±8g 로 재상향 (`0x6C` / `G_LSB` 4096.0)

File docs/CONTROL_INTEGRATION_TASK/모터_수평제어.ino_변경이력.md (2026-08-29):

# 모터_수평제어.ino 변경 이력

[`모터_수평제어.ino`](모터_수평제어.ino) — 베이스 IMU 기반 트레이 수평제어 코드의
작성 및 수정 기록.

센서 읽기 부분의 이력은 [`IMU_Reading.ino_변경이력.md`](IMU_Reading.ino_변경이력.md),
축·부호 규약은 [`README.md`](README.md) 참고.

| 푸시 시각 | 커밋 | 내용 |
|---|---|---|
| 2026-08-27 20:49 | `35b67f5` | [최초 작성 — 순수 수평제어 (ZV·합력벡터 없음)](#1-최초-작성-35b67f5) |
| 2026-08-27 20:55 | `bd6a8fc` | 변경이력 신규 |
| 2026-08-27 21:03 | `0c82f2d` | [Enable 상태를 오류로 오판하던 버그 수정 + t 시험구동](#시운전-중-발견한-문제) |
| 2026-08-27 21:21 | `21dcbba` | [arm 무충격화, 주기 재동기, 지령 LPF](#시운전-중-발견한-문제) |
| 2026-08-27 21:32 | `768dc3e` | [모터 실제 위치 로깅 + CAN 전송 분주](#시운전-중-발견한-문제) |
| 2026-08-27 21:41 | `8db992a` | [발진 측정 기록 및 과한 결론 정정](#시운전-중-발견한-문제) |
| 2026-08-29 21:24 | `2369911` | 푸시 시각 컬럼 추가 |

---

## 진단 도구 — `capture.py`

시리얼 모니터를 열지 않고 **명령 전송과 로그 수집을 한 번에** 하는 스크립트.
Claude Code 터미널에서 바로 돌리면 로그가 그대로 대화에 들어와 분석할 수 있다.

```
!python docs/CONTROL_INTEGRATION_TASK/capture.py --port COM14 --pre 5 --post 12 --out C:\arm_test.txt
```

| 인자 | 뜻 |
|---|---|
| `--port` | COM 포트 (장치관리자 또는 아두이노 IDE에서 확인) |
| `--pre` | 명령 전 관찰 시간 [초] |
| `--cmd` | 보낼 명령 (기본 `arm`, `t`, `none` 가능) |
| `--post` | 명령 후 기록 시간 [초] |
| `--out` | 저장 파일 |

동작 순서

```
pre초 관찰 → 명령 전송 → post초 기록 → stop 자동 전송 → 파일 저장
```

- 각 줄 앞에 **명령 시점 기준 상대시간**이 붙는다. 음수 = 명령 이전
- 끝나면 항상 `stop` 을 보내므로 모터가 켜진 채 방치되지 않는다
- **아두이노 시리얼 모니터를 반드시 닫고** 실행할 것 (포트는 하나만 점유 가능)

> Windows 콘솔(cp949)이 일부 문자를 못 찍어 예외가 나던 문제로 파일 저장이
> 통째로 날아간 적이 있어, 출력은 실패해도 무시하고 저장은 `finally` 로 옮겼다.

---

## 1. 최초 작성 (`35b67f5`)

### 목적과 범위

1단계로 **순수 수평제어만** 구현한다. 차체가 기운 만큼 트레이를 반대로 돌려
절대 수평을 유지하는 것까지.

```
motor_cmd = −θ_base
```

**이 단계에 넣지 않은 것** (다음 단계로 미룸)

| 항목 | 이유 |
|---|---|
| 합력 벡터 목표각 | 수평제어가 안정된 뒤 `θ_ref` 자리에 넣는다 |
| Convolved ZV 입력성형 | 위와 동일. 두 개를 동시에 켜면 원인 분리가 안 됨 |
| 상단(트레이) IMU | 제어에 쓰지 않는다. 성능 검증과 CNN 데이터 수집 전용 |

### 제어 구조 — 개루프 피드포워드

제어에 쓰는 센서는 **베이스(차체) IMU 하나뿐**이다. 트레이 IMU 는 루프에 없다.

```
베이스 IMU → 상보필터 → θ_base → (−1) → 슬루/제한 → CAN → 모터
                                                          ↑
                                              모터 내부 엔코더가 위치 루프를 닫음
```

이 구조를 택한 이유.

1. **진동하는 센서가 루프에 없다** — 트레이 IMU 는 짐벌 위에서 흔들린다.
   그 노이즈가 피드백에 들어가면 그대로 모터 지령이 된다.
2. **모터 엔코더가 이미 루프를 닫는다** — CAN 통합형이라 위치 제어는 모터
   내부에서 처리. IMU 로 유도한 각도보다 훨씬 깨끗하다.
3. **평가의 독립성** — 트레이 IMU 가 제어에 관여하면 "제어가 잘 됐는지" 를
   객관적으로 측정할 수 없다. 루프 밖에 있어야 독립적인 측정치가 되고
   CNN 학습 데이터도 오염되지 않는다.

한이음 보고서의 "Feed-forward Pre-emptive Control" 이 이 구조.

### 두 코드의 병합

| 출처 | 가져온 부분 |
|---|---|
| `IMU_Reading.ino` | SPI 읽기, 상보필터, 신뢰도 가중, 중력 정규화, 진단 |
| `motor_test.ino` | TWAI 초기화, `sendPosVel`, `sendUniversal`, 피드백 파싱 |

**신뢰도 가중을 그대로 유지한 이유** — 수평제어에도 필요하다. 차체가 가속하면
가속도계가 오염되어 `θ_base` 가 틀어지고, 그러면 트레이를 엉뚱한 방향으로
돌리게 된다.

### 모터 이름을 X/Y 대신 담당 각도로

```cpp
#define CAN_ID_PITCH  0x01
#define CAN_ID_ROLL   0x02
```

문서 간 대응이 **서로 반대**로 적혀 있어 X/Y 라는 이름 자체를 쓰지 않기로 했다.

| 출처 | Pitch | Roll |
|---|---|---|
| 논문 + 이전 구동 코드 | Y축 모터 | X축 모터 |
| 한이음 보고서 | Motor_X | Motor_Y |

실제 물리 모터가 반대로 물려 있으면 위 두 상수만 맞바꾸면 된다.

### 안전 설계

센서 입력으로 모터가 움직이는 첫 코드이므로 아래를 넣었다.

| 장치 | 값 | 목적 |
|---|---|---|
| **arm 필수** | 부팅 시 `0xFD` | 전원 인가만으로 움직이지 않게 |
| **GAIN** | 0.3 시작 | 방향이 반대여도 천천히 움직여 대응할 시간 확보 |
| 각도 제한 | ±25° | 기구 간섭 방지 |
| 슬루 제한 | 60 deg/s | 지령 급변 방지 |
| 속도 제한 | 2 rad/s | 모터 측 제한 |
| 자동 disarm | — | 센서 파워다운 / 무보정 1초 초과 / 모터 오류코드 |

가장 큰 위험은 **모터 방향이 반대인 경우**다. 기울어짐을 줄이는 게 아니라
키우는 양의 피드백이 되어 발산한다. GAIN 을 낮게 시작하고 슬루를 건 것이
이에 대한 대비.

`DIR_PITCH` / `DIR_ROLL` 을 `-1.0` 으로 바꾸면 해당 축 방향이 뒤집힌다.

### 시리얼 명령

| 명령 | 동작 |
|---|---|
| `arm` | 에러해제 → 영점 → enable |
| `stop` / `s` | disable |
| `z` | 현재 위치를 모터 영점으로 |
| `g<값>` | 게인 변경 (0.0 ~ 1.5) |
| `?` | 현재 상태 출력 |

### 출력 포맷

```
pitch:12.34,cmd_pitch:-3.70,roll:-5.21,cmd_roll:1.56
[stat] ARMED reset:0 무보정:0/200 |a|=1.00 trust=1.00
```

`cmd_*` 는 실제로 CAN 으로 내보낸 지령각. 시리얼 플로터로 `pitch` 와
`cmd_pitch` 를 겹쳐 보면 추종 상태를 바로 확인할 수 있다.

---

## 시운전 중 발견한 문제

### ① Enable 상태를 오류로 오판 (`0c82f2d`)

피드백 `data[0]` 상위니블은 **오류코드가 아니라 상태코드**다.
정상 동작 중이면 `1`(Enable) 이 온다.

```cpp
if (err != 0 && armed) motorsDisarm(...);   // Enable(1) 도 오류로 판정
```

arm → enable → 모터가 "Enable" 보고 → 즉시 disarm. **모터가 아예 안 움직였다.**
`motor_test.ino` 가 이 니블을 `err` 라는 이름으로 출력만 하고 있어서 그대로 믿고
안전장치를 붙인 것이 원인. 판정 기준을 `>= 0x8` 로 고쳤다.

### ② arm 순간 크게 튐 (`21dcbba`)

enable 전에 목표 위치를 지정하지 않아, 드라이버가 **마지막으로 기억하던 목표**로
달려갔다. 시험 구동(`t`) 직후면 그 값이 ±0.5 rad = ±28°.
GAIN 을 낮춰도 그대로였던 이유가 이것. enable 전에 목표=현재위치를 먼저 보낸다.

### ③ 밀린 주기 몰아치기 (`21dcbba`)

100Hz 를 `lastLoop += 10000` 으로 누적하는데, 시험 구동(6초)처럼 오래 걸리는
작업 뒤에는 밀린 600회가 순식간에 실행되며 자이로를 6초치 적분하고 CAN 을
수백 프레임 쏟아냈다. 0.1초 이상 밀리면 재동기하도록 변경.

### ④ 지령은 고정인데 모터가 왕복 → 모터 `0x01` 쪽 문제 (원인 조사 중)

`capture.py` 로 12초 캡처한 결과, **지령은 완벽하게 안정적**이었다.

```
+0.27  cmd_pitch:-0.30     ← arm 직후, 0 에서 시작
+0.80  cmd_pitch:-16.58    ← 0.53초에 걸쳐 램프 (슬루 30°/s 대로)
+0.92 ~ +12.03             ← 이후 11초간 -16.58 ~ -16.67 (변동 0.09°)
```

계산도 정확했다. `pitch 55.27° × GAIN 0.3 = 16.58` → `cmd -16.58`.
IMU 도 정상 (`trust` 0.96~1.00, 무보정 0, 리셋 0).

그런데 **모터는 물리적으로 계속 왕복했다.** 지령이 고정인데 모터가 움직이므로
원인은 제어 코드 밖 — 드라이버 위치루프 또는 기구 쪽이다.

확인을 위해 추가한 것

- **모터 실제 위치 로깅** — 피드백 `data[1..2]` 를 각도로 변환해 `act_*` 로 출력.
  `cmd` 와 `act` 를 나란히 보면 진동의 진폭과 주기를 잴 수 있다.
- **CAN 전송 분주 (`CAN_DIV`)** — 위치/속도 모드 드라이버는 프레임을 받을 때마다
  내부 궤적을 새로 시작할 수 있다. 같은 목표를 100Hz 로 재전송하면 계속
  재시작하며 떨 수 있으므로 기본을 50Hz(`d2`)로 낮췄다.
  `motor_test.ino` 가 문제없던 주기가 50Hz 였다.
- 출력 주기를 10Hz → 50Hz 로 올려 진동을 관찰할 수 있게 했다.

#### 측정 결과 — 한 축만 발진

실제 위치를 찍어보니 **두 축의 거동이 완전히 달랐다.**

| | 지령 | 실제 | 변동폭 |
|---|---|---|---|
| 안정 축 | `+10.02` | `9.98 ~ 10.04` | **±0.03°** |
| 발진 축 | `-16.70` | `-35.8 ~ +1.9` | **약 38° p-p** |

발진 파형의 특징

- **주파수 1.75 Hz** (주기 0.575초, 8주기에 걸쳐 일정)
- 진폭이 12° → 25° → 35° → 38° 로 커지다 수렴 — **리밋사이클**
- 진동 **중심은 지령과 일치** (`(-35.8+1.8)/2 = -17.0` vs 지령 `-16.70`)
  → 목표는 제대로 받았고, 그 주위에서 멈추지 못하는 것
- 우리가 건 `LIMIT_DEG` 25° 를 넘어 -35.8° 까지 갔다.
  우리가 보낸 적 없는 각도이므로 **드라이버 내부 루프의 오버슛**

#### CAN ID 를 맞바꿔 확인

`CAN_ID_PITCH` / `CAN_ID_ROLL` 을 서로 바꿔 다시 측정했다.

| | 바꾸기 전 | 바꾼 후 |
|---|---|---|
| 물리 모터 `0x01` (바깥축) | pitch 지령 → **발진** | roll 지령 → **발진** |
| 물리 모터 `0x02` (안쪽축) | roll 지령 → 안정 | pitch 지령 → **안정** |

주파수는 양쪽 경우 모두 1.75 Hz 로 동일했다.

**이 시험으로 증명된 것**

> 모터 `0x01` 은 어떤 지령값(`-16.7°` / `+9.9°`)을 받든, 어느 제어 채널에
> 물리든 발진한다. 즉 제어 코드나 특정 지령값의 문제가 아니다.

**이 시험으로 증명되지 않은 것 (주의)**

코드에서 CAN ID 를 바꿔도 **모터가 물리적으로 도는 축은 바뀌지 않는다.**
바뀐 것은 "어느 지령이 어느 모터로 가느냐" 뿐이다. `0x01` 은 시종일관
바깥축에 붙어 있으므로, 아래 두 원인은 여전히 구분되지 않았다.

| 후보 | 상태 |
|---|---|
| `0x01` 드라이버 게인 | 파라미터 미확인 |
| 바깥축 관성 (roll 조립체 전체를 짊어짐) | 미확인. 1.75Hz 라는 낮은 주파수는 큰 관성과 부합 |

구분하려면 **바깥축에서 안쪽 조립체를 분리하고 `0x01` 단독으로** 돌려본다.

| 결과 | 원인 |
|---|---|
| 부하 없이도 발진 | 드라이버 게인 |
| 부하 없으면 안정 | 관성 대비 게인 과다 → `Position KP` 하향 |

#### 다음 조치

`hardware/GL60II_모터_설정_가이드.md` 3장 백업은 **"모터 #1 기준"** 인데
`CAN ID 0x01 → 0x02 로 변경` 이라고 적혀 있다. 즉 **백업에 기록된 모터가 지금
안정적인 `0x02`** 이고, 발진하는 `0x01` 은 파라미터를 손대지 않은 다른 개체다.
두 드라이버의 설정이 다를 수 있다.

CubeMars 툴로 양쪽을 `ReadParam` 해서 비교하고, 안정적인 `0x02` 기준으로 맞춘다.
특히 아래 4개.

| 항목 | `0x02` 백업값 | 비고 |
|---|---|---|
| **VMAX** | **30** | 가이드가 "매뉴얼 기본값 200과 다름" 이라 표시. `0x01` 은 공장값 200 일 수 있다 |
| **Position KP** | **54** | 위치루프 게인 — 발진의 직접 원인 |
| Speed KP / KI | 0.003630572 / 0.003926991 | |
| Damping factor | 4 | |

안정적으로 도는 모터가 이미 있으므로 새로 튜닝할 필요 없이 그 값을 복사하면 된다.

---

## 시운전 결과

아래 순서로 진행하고 결과를 기록할 것.

| 단계 | 확인 항목 | 결과 |
|---|---|---|
| 1 | 모터 없이 부호 확인 — `pitch` 와 `cmd_pitch` 가 반대 부호인가 | (미실시) |
| 2 | 모터 방향 — 트레이가 반대로 돌아 수평을 유지하는가 | (미실시) |
| 3 | 게인 상승 — 어느 GAIN 에서 진동이 시작되는가 | (미실시) |
| 4 | 정량 확인 — 20° 기울일 때 GAIN 1.0 에서 수평이 유지되는가 | (미실시) |

> 2단계 확인 전에는 GAIN 을 올리지 말 것. 방향이 반대면 발산한다.

### 기록할 항목

- `DIR_PITCH` / `DIR_ROLL` 최종 부호
- 진동 없이 쓸 수 있는 최대 GAIN
- 필요했던 `VEL_LIMIT` / `MAX_RATE` 조정값
- 20° 기울임에서의 트레이 실제 각도 (각도기 또는 상단 IMU)

---

## 축 대응은 아직 미확정

`CAN_ID_PITCH` / `CAN_ID_ROLL` 의 현재 값은 **임시 배정**이다.

`pitch` 는 "IMU 보드의 X축 중심 회전"인데, 시운전 동안 IMU 를 손에 들고 있어
짐벌의 어느 축과도 고정된 관계가 없다. 차체에 실장한 뒤 아래 순서로 확정한다.

1. IMU 의 +X축이 짐벌의 어느 축과 나란한지 확인
2. 그 축을 담당하는 모터를 `CAN_ID_PITCH` 에 배정
3. `DIR_PITCH` / `DIR_ROLL` 부호를 다시 확인

그 전까지는 "두 모터가 각각 지령 각도를 안정적으로 유지하는가" 만 본다.

---

## 다음 단계

- [ ] 시운전 4단계 완료 및 파라미터 확정
- [ ] `θ_ref` 자리에 합력 벡터 목표각 산출 추가
- [ ] Convolved ZV 입력성형 추가 (roll 축 포함 — 이전 구조의 누락 사항)
- [ ] 상단 트레이 IMU 추가 → 제어 성능 검증 및 CNN 데이터 수집

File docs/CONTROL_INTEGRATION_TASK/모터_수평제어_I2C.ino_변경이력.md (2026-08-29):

# 모터_수평제어_I2C.ino 변경 이력

[`모터_수평제어_I2C.ino`](모터_수평제어_I2C.ino) — IMU 를 I2C 로 읽는 수평제어 코드.

제어식·게인·안전장치는 [`모터_수평제어_MIT.ino`](모터_수평제어_MIT.ino) 와 같다.
그쪽 이력은 [`모터_수평제어_MIT.ino_변경이력.md`](모터_수평제어_MIT.ino_변경이력.md) 참고.

| 푸시 시각 | 커밋 | 내용 |
|---|---|---|
| 2026-08-29 21:00 | `b3faa3c` | [최초 작성 — SPI 에서 I2C 로 전환](#왜-i2c-로-바꿨나) |
| 2026-08-29 21:24 | `2369911` | [변경이력 신규](#검증-결과-2026-08-29) |

---

## 왜 I2C 로 바꿨나

### SPI 가 죽었다

베이스 IMU 가 SPI 로 `WHO_AM_I` 에 `0x00` 만 돌려주기 시작했다. 오전에는 같은
보드·같은 코드로 `0x6C` 가 정상으로 나오던 센서였다.

배제한 것들 — **전부 정상이었다.**

| 확인 | 방법 | 결과 |
|---|---|---|
| VIN 전원 | 보드 전원등 점등 | 정상 |
| GND | 도통 | 정상 |
| SDA (GPIO11) | 도통 | 0Ω |
| SCL (GPIO12) | 도통 | 0Ω |
| CS (GPIO10) | 도통 | 0Ω |
| SDO 풀다운 | SDO↔GND 저항 | 10kΩ (정상값) |
| CS 핀 위치 | `IMU_핀찾기.ino` 로 13핀 스캔 | 전부 `0x00` |
| 브레드보드 | 통째로 교체 | 변화 없음 |
| ESP32 | 오전에 되던 그 보드 | — |

### 그런데 I2C 로는 응답했다

`IMU_I2C확인.ino` 로 확인.

```
응답 주소: 0x6A
0x6A → WHO_AM_I 0x6C   ★ 칩 살아있음
판정: 칩 정상. SPI 경로만 문제다.
```

**칩은 멀쩡하고 SPI 인터페이스만 죽었다.** I2C 와 SPI 는 같은 다이에 있지만
입력단 회로가 일부 다르므로 한쪽만 상할 수 있다.

원인은 그 전에 몇 시간 이어진 **VIN 접촉 불량**으로 보인다. 전원이 빠르게
끊겼다 붙었다 하며 브라운아웃 구간을 반복해서 지나갔다.

> **오진 기록.** 이 시점에 칩 전체가 죽은 것으로 결론냈으나 틀렸다.
> I2C 를 시도해 보자는 판단이 나온 뒤에야 살아있음이 확인됐다.
> SPI 가 안 되면 I2C 를 먼저 시도할 것. 5분이면 갈린다.

### 성능은 문제없다

| | SPI | I2C |
|---|---|---|
| 속도 | 1 MHz | 400 kHz |
| 12바이트 읽기 | ~0.1 ms | **~0.3 ms** |
| 제어 주기 | 10 ms | 10 ms |

10ms 주기에 0.3ms 면 여유가 충분하다.

### 오히려 유리한 점 — 회전부 배선

트레이 IMU 는 짐벌 위에서 계속 회전한다. 그쪽으로 가는 선은 적을수록 좋다.

| | SPI | I2C |
|---|---|---|
| 공유 가능한 선 | SDA·SCL·SDO | SDA·SCL |
| IMU 마다 따로 필요한 선 | **CS** | 없음 (주소로 구분) |

```
베이스 IMU : SDO → GND → 주소 0x6A
트레이 IMU : SDO → 3V3 → 주소 0x6B
```

두 IMU 가 같은 두 선만 쓰면 되므로 **회전부로 가는 선이 하나 줄어든다.**

---

## 배선

```
IMU        ESP32-S3      비고
---        --------      ----
VIN   →    3V3
GND   →    GND
SDA   →    GPIO 11
SCL   →    GPIO 12
CS    →    3V3           ★ HIGH 고정 — 이래야 I2C 모드
SDO   →    GND           ★ 주소 하위비트 (GND=0x6A, 3V3=0x6B)
```

**GPIO10·13 은 쓰지 않는다.** SPI 판에서 CS·MISO 로 쓰던 핀이다.

풀업은 브레이크아웃 내장으로 동작했다. 선이 길어지면 4.7kΩ 을 SDA·SCL
각각에서 3V3 으로 달 것.

---

## 코드 차이

SPI 판에서 **센서 읽기 계층만** 바뀌었다.

| 항목 | SPI 판 | I2C 판 |
|---|---|---|
| 읽기 | `SPI.transfer(reg \| 0x80)` | `Wire` — MSB 규칙 없음 |
| 쓰기 | `SPI.transfer(reg & 0x7F)` | `Wire.write(reg, val)` |
| CS | GPIO10 토글 | 3V3 고정 (코드가 건드리지 않음) |
| 연속 읽기 | 12바이트 버스트 | repeated start 후 12바이트 |
| 오류 계수 | 없음 | `i2c_err` 추가 |

레지스터 주소·설정값(`CTRL1_XL 0x68` 등)은 인터페이스와 무관하게 동일하다.
`IF_INC`(CTRL3_C 의 `0x44`)가 1 이어야 연속 읽기에서 주소가 자동 증가하는 것도 같다.

**그대로 유지한 것** — 제어식, 게인(Kp 1 / Kd 0.1), 상보필터, 신뢰도 가중,
중력 정규화, 폭주 차단(±50°), 피드백 두절 감지, 시리얼 명령, MIT 모드 CAN 전송.

### 추가된 진단

```
[stat] ARMED ... 무보정:0/201 I2C오류:0
                              ↑
```

I2C 읽기 실패를 누적해 표시한다. 이 값이 계속 오르면 풀업이나 배선을 의심한다.

---

## 검증 결과 (2026-08-29)

| 항목 | 결과 |
|---|---|
| `WHO_AM_I` | `0x6C` (주소 0x6A) ✅ |
| `arm` | 정상 ✅ |
| **`GAIN 1.0`** | **정상 동작** ✅ |

**수평제어 완성.** 차체가 기운 만큼 트레이가 반대로 돌아 수평을 유지한다.

### SPI 판에서 측정해 둔 성능 (참고)

I2C 전환 전 `g0.3` 에서 `capture.py` 로 측정한 값. 제어식이 같으므로
I2C 판에서도 비슷할 것으로 보나 재측정하지 않았다.

| | PITCH | ROLL |
|---|---|---|
| 추종오차 (지연 보정 후) | 1.26° | 0.69° |
| **지연** | **150 ms** | **180 ms** |
| cmd 대비 act 진폭 | 78% | 81% |
| 축 간 간섭 | 0.077° | 거의 없음 |
| 정지 시 act 떨림 | 0.163° | 0.091° |

---

## 남은 항목

- [ ] `g1.0` 상태에서 성능 재측정 (지연·추종오차)
- [ ] **지연 150~180ms** — 안티슬로싱 단계에서 문제.
      슬로싱 주기 420ms 의 36% 다. `CMD_LPF`(57ms)·슬루·낮은 Kp 가 원인
- [ ] `act` 가 `cmd` 의 78% 까지만 가는 처짐 — `kp` 상향 검토
- [ ] 트레이 IMU 를 0x6B 로 추가
- [ ] 미세 진동·공진 — 차체 실장 후 재평가
- [ ] 다음 단계: 합력 벡터 목표각 → ZV 입력성형

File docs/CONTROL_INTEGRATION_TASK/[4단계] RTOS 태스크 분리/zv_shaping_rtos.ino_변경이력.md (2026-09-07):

# zv_shaping_rtos.ino 변경 이력

[`zv_shaping_rtos.ino`](zv_shaping_rtos.ino) — 4단계. 3단계를 태스크로 쪼갠 코드.

3단계는 [`../[3단계] ZV 입력성형/ZV_입력성형.ino_변경이력.md`](../%5B3%EB%8B%A8%EA%B3%84%5D%20ZV%20%EC%9E%85%EB%A0%A5%EC%84%B1%ED%98%95/ZV_%EC%9E%85%EB%A0%A5%EC%84%B1%ED%98%95.ino_%EB%B3%80%EA%B2%BD%EC%9D%B4%EB%A0%A5.md) 참고.

| 내용 |
|---|
| [최초 작성 — `loop()` 를 `ctrl` + `io` 로 분리](#무엇이-바뀌었나) |
| [나누면서 생긴 위험 6가지 — 찾아서 막은 내역](#나누면서-생긴-위험-6가지--전부-막았다) |
| [실측값 3개를 기본값으로](#실측값을-기본값으로) |
| [로그에 `t` / `pre_*` 추가](#슬루-판정용-필드) |
| [주기 CAN 송신 대기 0](#can-송신-대기-0) |
| [실기 검산](#실기-검산) |
| [축별 임피던스 게인 분리 — `kpp`/`kpr`/`kdp`/`kdr`](#축별-게인-분리-2026-09-01) ★ 절대 규칙 예외 |
| [`.ino` 를 상위 폴더로 이동](#ino-를-상위-폴더로-이동) |
| [`kp6` 실측 — 지연 절반으로](#kp6-실측-2026-09-01) |
| [회전시키면 부호가 뒤집힌다 — 지렛대 오차](#회전시키면-부호가-뒤집힌다) |
| [가속 종료 소프트 복귀 — `sr` 계열](#가속-종료-소프트-복귀) |
| [합력각 직접 방식 + 자세 보정 게이트 + SR v2](#합력각-직접-방식으로-바꿨다) |
| [실측 기본값 — `kpp4 kdp0.2 r120 f0.30 d1 zv1`](#실측-기본값) |
| [각도 상한 20/25/50 → 45/45/55](#각도-상한을-기구-한계까지) |
| [`zf` 2.40 → 2.00 실측값으로](#zf-를-실측값-200-으로) |
| [가속도계 내부 LPF2 켬 — 바퀴 충격 앨리어싱 제거](#가속도계-lpf2)|
| [모터 피드포워드 — `v_des` + `t_ff = J·θ̈`](#모터-피드포워드) |
| [피드포워드 실측 — 모터 70 → 25 ms, 기본 켜짐](#피드포워드-실측) |
| [수위 센서 로그 필드 `lvl:` 추가](#수위-센서-로그) |
| [와이파이판 `WIFI_이용/zv_shaping_wifi.ino` 추가](#와이파이판) |
| [와이파이판: CAN 을 와이파이보다 먼저 설치, 설치 결과 확인](#와이파이판-can-설치-순서) |
| [루트 통합본 `Liquid_Control_Robot.ino` — 가변 서스펜션 스텝모터 합침](#루트-통합본-liquid_control_robotino) |

---

## 절대 규칙

> **제어 수식, 명령어, 출력 내용을 바꾸지 않는다. 실행 구조만 바꾼다.**

계산식은 복사만 했다. 손으로 다시 쓰지 않았다.

검증은 두 가지로 했다.

**① 문자열 전수 대조** — 두 파일의 리터럴을 모두 뽑아 비교했다.

```
3단계 131종 137개  /  4단계 137종 143개
사라진 출력 : 0건
새 문자열   : "%s\n"(qprintln 내부)  "ctrl"  "io"  그리고 [rtos] 계측 줄 2개
```

**② 삭제된 코드 줄 전수 확인** — 들여쓰기·주석을 무시하고 원본에서 없어진 줄을
전부 뽑았더니 아래 6가지뿐이었고, **제어 수식 줄은 하나도 없었다.**

| 없어진 줄 | 수 | 왜 |
|---|---|---|
| `float GAIN = ...` 등 선언 | 17 | `volatile` 이 붙음 |
| `Serial.printf` / `println` | 13 | `qprintf` / `qprintln` 로 (내용 동일) |
| `arm` `stop` `t` `z` 처리 | 7 | 요청 큐로 |
| `float &d = ...` | 1 | `volatile float &d` |
| `zvRecalc(); zvClear();` | 4 | 잠금 추가 |
| `loop()` 머리 + 스트림 printf | 15 | `vTaskDelayUntil` + 스냅샷 큐 |

---

## 무엇이 바뀌었나

```
3단계                          4단계
loop() {                       ctrl (코어1, 우선순위6)   io (코어0, 우선순위2)
  handleSerial()                 vTaskDelayUntil(10ms)     큐에서 꺼내 출력
  10ms 지났나?                   요청 실행 (arm/stop/t/z)   handleLine()
  IMU→필터→ZV→제어→CAN           IMU→필터→ZV→제어→CAN
  로그 출력                      숫자만 큐에 ──────────────→
}                              loop() = vTaskDelay(1000)  껍데기
```

`ctrl` 본문의 순서는 3단계 `loop()` 와 같다.
`readIMU` → 상보필터 → 이상감지 → `drainCAN` → 합력벡터 → ZV → 제어 →
`sendBoth` → 출력 → 2초 상태.

`loop()` 를 지우지 않은 이유는 아두이노 `loopTask` 가 태스크 워치독에게 살아있다고
보고하는 역할을 겸하기 때문이다. 지우면 리셋이 걸릴 수 있어 껍데기로 남겼다.

### `dt` 가 가정에서 약속으로

`const float dt = 0.01;` 을 상보필터와 슬루(`MAX_RATE * dt`)가 쓴다.
3단계에는 그것을 보장하는 장치가 없었다 — 안 늦었을 뿐이다.
`vTaskDelayUntil` 은 OS 가 지킨다.

---

## 나누면서 생긴 위험 6가지 — 전부 막았다

**RTOS 자체의 문제가 아니다.** 일이 한 줄로 서 있으면 원리적으로 불가능했던 일들이
두 줄로 나누면 가능해진다. 그 "가능해진 것"이 위험이다.

```
3단계    A가 끝나야 B가 시작   →  둘이 부딪힐 수가 없다
4단계    A와 B가 진짜 동시에   →  부딪힐 수 있다
```

그래서 나누기 전에 여섯 곳을 막아야 했다. **여섯 개가 남아 있는 것이 아니라,
여섯 개를 찾아서 막았고 실기로 확인했다는 뜻이다.**

| # | 나누면 가능해지는 일 | 막은 장치 | 실기 확인 |
|---|---|---|---|
| ① | 두 태스크가 동시에 `Serial` 에 써서 줄이 섞인다 | 큐 2개, `io` 만 `Serial` 을 만진다 | 태스크 경합으로 인한 섞임 0건 |
| ② | `arm` 250ms 동안 제어 지령이 계속 나간다 | 명령 큐 + `ctrlBusy` | `arm` 중 지령 없음, `재동기 1` |
| ③ | ZV 계수 4개가 섞인 조합으로 읽힌다 | 스핀락 `zvMux` | `zd` 응답의 `A1/A2/A3` 가 3단계와 동일 |
| ④ | 시리얼 파서가 최대 1초 막혀 큐가 넘친다 | 문자 단위 비동기 파서 | `샘플드롭 0` |
| ⑤ | 밀린 틱을 간격 없이 몰아서 실행한다 | 매 틱 끝에서 재동기 | `10ms초과 0` |
| ⑥ | IDLE 태스크가 굶어 워치독이 리셋한다 | 반드시 기다리는 함수만 사용 | 26초 연속 구동 중 리셋 0 |

①②③④는 **코드 리뷰에서 지적받아 고친 것**이다. 처음 구현에는 `pendingCmd` 변수
유실, sweep 중 설정 변경, `zv1` 의 락 밖 대입, `readStringUntil` 블록이 실제로
남아 있었다. 아래에 각각 어떤 상태였고 어떻게 바꿨는지 적는다.

---

### ① 동시 출력 → 줄이 섞인다

**3단계에서는 불가능했다.** 출력하는 곳이 `loop()` 한 군데뿐이었다.

**안 막으면** 이렇게 된다.

```
정상 : t:123,pre_pitch:6.28,...,cmd_pitch:6.28
섞임 : t:123,pre_p!! 모터 이상itch:6.28,...
```

`check_tuning.py` 는 한 줄 안에서 `pre_pitch` 와 `cmd_pitch` 를 짝지어 읽는다.
줄이 깨지면 분석이 무너진다.

**막은 방법.** `Serial` 은 `io` 태스크만 만진다. `ctrl` 은 큐에 넣고 지나간다.
함수별로 전수 감사해 `ctrl` 쪽 출력 13곳을 `qprintf` / `qprintln` 으로 바꿨다.

```cpp
QueueHandle_t qEvt  = NULL;     // 텍스트 12통  — 모터이상·폭주차단·두절·DISARM 이유
QueueHandle_t qSnap = NULL;     // 샘플 32통   — 33Hz 스트림
```

**큐를 두 개로 나눈 이유가 따로 있다.** 하나로 두면 PC 가 멈춘 순간 샘플이 자리를
먼저 차지해서 **정작 원인이 되는 이벤트가 버려진다.** 제어는 돌아도 사후 분석이
막힌다. `io` 는 `qEvt` 를 먼저 비운다.

스트림은 **숫자만** 큐에 넣는다. `%.2f` 13개 포맷(수백 µs)은 `io` 가 진다.

`ctrl` 쪽 출력은 **대기 0** 이다. 처음에는 5ms 를 기다리게 했는데, PC 가 안 읽어서
큐가 차면 로그 한 줄마다 제어가 멈춘다 — 그걸 없애려고 나눈 것이라 앞뒤가 안 맞았다.
리뷰 지적으로 0 으로 바꿨다. 잃은 줄은 `dgEvtDrop` 으로 센다.

> **남은 것.** 태스크 경합은 없앴지만 USB 계층에서 0.45% 가 깨진다.
> 원인 미확정. [README 의 「아직 안 된 것」](README.md#usb-로그-줄-깨짐-045) 참고.

---

### ② `arm` 은 250ms, `t` 는 8초 블록한다  ← 제일 위험했다

```cpp
broadcastUniversal(0xFB);  delay(50);   // 에러 해제
broadcastUniversal(0xFE);  delay(50);   // 영점
sendBoth();                delay(50);
broadcastUniversal(0xFC);  delay(100);  // enable
```

**3단계에서는 이 250ms 동안 제어도 같이 멈춰 있었다.**

**안 막으면** — `io` 에서 실행하면 그동안 `ctrl` 이 CAN 지령을 계속 쏜다.
**영점을 재정의하는 중에 지령이 끼어든다.** 3단계에서는 물리적으로 불가능한
상황이고, 모터가 어디로 갈지 모른다. `motorsArm()` 은 I2C 도 쓰는데 `Wire` 는
두 태스크가 동시에 만지면 깨진다.

**막은 방법.** 요청 큐로 넘기고 `ctrl` 이 직접 실행한다. 같은 코드가 같은 것을
멈춘 채로 돌아서 3단계와 동작이 같아진다.

```cpp
QueueHandle_t qCmd = NULL;        // 명령 6통
volatile bool ctrlBusy = false;   // arm / t 실행 중
```

여기서 세부 세 가지를 리뷰에서 지적받아 고쳤다.

| 처음 구현 | 무엇이 잘못됐나 | 고친 것 |
|---|---|---|
| `volatile uint8_t pendingCmd` 변수 하나 | `ctrl` 이 읽고 지우는 사이에 들어온 명령이 사라지고, 연속 입력은 앞의 것을 덮어쓴다 | **큐** 로 바꿨다. `stop` 은 자리가 없으면 앞 명령을 하나 버려서라도 넣는다 |
| 명령 처리 뒤 공통으로 `ctrlBusy = false` | 큐에 `[z, arm]` 이 있으면 `z` 가 먼저 풀어버려 arm 250ms 동안 파서가 다시 열린다 | **`arm` 과 `t` 가 끝날 때만** 푼다 |
| `ctrlBusy = true; ctrlSend(1);` | 큐에 못 넣으면 풀어줄 사람이 없어 파서가 영영 멈춘다 | `ctrlSend` 를 `bool` 로 바꿔 **실패하면 되돌린다** |

**`ctrlBusy` 를 "차단" 이 아니라 "파서 정지" 로 한 이유.** 3단계는 sweep 8초 동안
`handleSerial()` 이 아예 안 불려서, 입력이 UART 버퍼에 쌓였다가 끝난 뒤 처리된다.
`ctrlBusy` 중 `Serial.read()` 를 하지 않으면 바이트가 그대로 남아 **동작이 정확히
같아진다.** 거부하거나 따로 보관하는 것보다 정확하다.

이걸 안 막으면 sweep 도중 `dr` 이 들어와 복귀 직후 roll 방향이 뒤집힌다.
출력 순서 문제가 아니라 모터가 달라지는 문제였다.

---

### ③ ZV 계수는 4개가 한 세트다

```cpp
void zvRecalc() {
  zv_n1 = ...;   // 반주기 [샘플]
  zv_A1 = ...;   // 임펄스 진폭
  zv_A2 = ...;
  zv_A3 = ...;
}
```

**안 막으면** `ctrl` 이 바꾸는 도중에 읽는다.

```
zv_A1 = 새 값,  zv_A2 = 옛 값   ← 섞인 조합
→ 그 틱만 엉뚱한 성형을 한다
```

`zvClear()` 는 링버퍼 float 256개를 지우므로 반만 지워진 것을 읽을 수도 있다.

**막은 방법.** 스핀락. `zvRecalc` · `zvClear` · `ctrl` 의 ZV 계산 블록 세 곳이다.

```cpp
portMUX_TYPE zvMux = portMUX_INITIALIZER_UNLOCKED;
```

**처음 구현에서 `zv1` 하나가 빠져 있었다.** 리뷰 지적으로 고쳤다.

```cpp
ZV_ON = ...;                                    // 락 밖 — 그 사이 한 틱이 지나간다
if (ZV_ON) { ZV_LOCK(); zvClear(); ZV_UNLOCK(); }
```

```cpp
bool zvOn = (s.substring(2).toInt() != 0);      // 변환은 락 밖에서 먼저
ZV_LOCK();
ZV_ON = zvOn;
if (zvOn) zvClear();
ZV_UNLOCK();
```

문자열 변환을 락 밖으로 뺀 것도 의도적이다. 임계구역 안에서 `String` 을 만들면
**인터럽트가 막힌 채로 힙을 건드린다.**

`zf` `zd` `zm` 은 처음부터 변경 전체를 잠갔다. 요청 큐 대신 락을 쓴 이유는 `zd` 가
계산 직후 `A1/A2/A3` 를 바로 찍기 때문이다 — 미루면 옛 값이 찍혀 출력이 달라진다.

**반면 홑겹 변수는 막을 필요가 없다.** `GAIN` `MOTOR_KP` `MAX_RATE` `ZV_ON`
`stream` 등은 32비트 단일 접근이 원자적이라 옛 값 아니면 새 값이지 섞인 값이
안 나온다. `volatile` 만 붙였다. `dp`/`dr` 의 `float &d` 는 `volatile float &d`
로 바꿔야 컴파일된다.

---

### ④ `readStringUntil` 은 최대 1초 막힌다

```cpp
String s = Serial.readStringUntil('\n');   // 개행이 안 오면 기본 1초 대기
```

**3단계에서는 이래도 됐다.** 막히면 전체가 같이 멈추니 잃는 것이 없었다.

**안 막으면** — `io` 가 그 1초 동안 큐를 못 비운다. **32칸 샘플 큐는 33Hz 에서
1초면 찬다.** 터미널이 `k` `p` `2` 를 나눠 보내기만 해도 로그가 통째로 날아간다.

**막은 방법.** 문자 단위 비동기 파서. `handleSerial()` 을 `handleLine(const char*)`
로 바꿨고, 명령·응답 내용은 그대로다.

```cpp
while (!ctrlBusy && Serial.available()) {
  char c = Serial.read();
  if (c == '\n' || c == '\r') { if (n) { line[n] = 0; n = 0; handleLine(line); } }
  else if (n < sizeof(line) - 1) line[n++] = c;
}
```

`'\r'` 도 종결로 본다. 3단계는 `readStringUntil('\n')` 뒤에 `trim()` 을 했으니
결과가 같다.

---

### ⑤ 밀린 틱을 몰아서 실행한다

**처음 구현은 `arm`/`t` 뒤에만 시계를 맞췄다.** 리뷰에서 이것으로 부족하다는
지적을 받았다.

`configSensor()` 는 **명령이 아니라 센서 이상 감지에서 자동으로 불리고**, 정상
실행만으로 150ms 를 쓴다.

```cpp
writeReg(REG_CTRL3_C, 0x01);  delay(50);    // 소프트 리셋
...                           delay(100);
```

I2C 가 응답 없으면 여기에 최대 50ms 가 더 붙는다.

**안 막으면** `vTaskDelayUntil` 이 밀린 틱을 **10ms 간격 없이 연속으로 따라잡는다.**
제어 계산과 CAN 전송이 한꺼번에 몰린다.

**막은 방법.** 특정 명령 뒤가 아니라 **매 틱 끝에서** 실제 지연을 검사한다.

```cpp
if ((TickType_t)(xTaskGetTickCount() - xLastWake) >= pdMS_TO_TICKS(20)) {
  xLastWake = xTaskGetTickCount();
  dgResync = dgResync + 1;
}
```

계측 시작점도 명령 처리 **뒤**로 옮겼다. `arm` 의 의도된 250ms 정지를 같이 세면
(실측 270,621 µs 로 찍혔다) 정작 제어 틱이 늦었는지를 볼 수 없다.

---

### ⑥ 바쁜 대기는 워치독 리셋을 부른다

FreeRTOS 워치독은 어떤 태스크가 CPU 를 놓지 않으면 죽은 것으로 보고 **보드를
리셋한다.** 3단계에는 태스크가 하나였으니 해당이 없었다.

```cpp
while (!Serial.available()) { }     // ← 이렇게 짜면 리셋된다
```

**막은 방법.** 둘 다 반드시 기다리는 함수를 쓴다.

- `ctrl` → `vTaskDelayUntil(&xLastWake, pdMS_TO_TICKS(10))`
- `io`   → `xQueueReceive(qSnap, &sn, pdMS_TO_TICKS(5))`

아두이노 `loopTask` 도 지우지 않고 `vTaskDelay(1000)` 껍데기로 남겼다. 이 태스크가
워치독에게 살아있다고 보고하는 역할을 겸한다.

---

## 실측값을 기본값으로

3단계 기본값은 매번 손으로 넣어야 해서 빠뜨리는 사고를 두 번 겪었다.
시리얼 명령으로 여전히 바꿀 수 있다.

| 항목 | 3단계 | 4단계 | 근거 |
|---|---|---|---|
| `MAX_RATE` | 30 | **120** | 요구 변화율 p95 가 101~112 °/s. 30 이면 지령의 31% 가 잘려 ZV 성형이 무너진다 |
| `MOTOR_KP` | 1.0 | **2.0** | 드룹 54~82% → 89% |
| `MOTOR_KD` | 0.13 | **0.13** | `Kd ∝ √(Kp+k)`, `k ≈ 0.28 N·m/rad` |

`k` 는 트레이 무게중심이 축보다 아래에 있어 생기는 복원 강성이다.
정지 구간에서 `act/cmd` 가 일정 비율로 모자란 것(오프셋 −0.38°/+0.10°, 거의 0)에서
`k = Kp·(1/droop − 1)` 로 냈다. 마찰이면 비율이 아니라 고정 오프셋으로 나타난다.

### ZV 성형은 슬루를 더 걸지 않는다

같은 로그에서 ZV 만 뺀 반사실 계산을 돌렸다 (`ref_*` 와 `zv_*` 가 둘 다 기록돼 있다).

| | ZV 끔 | ZV 켬 |
|---|---|---|
| pitch 슬루 걸림 | 10.8% | 10.9% |
| roll 슬루 걸림 | 12.3% | **10.0%** |
| roll 요구 p95 | 133 °/s | **122 °/s** |

임펄스 합이 1이고 둘 다 양수라 **가중 이동평균**이다. 계단이 하나 늘지만 각 계단
높이가 절반이라 최대 변화율은 오히려 내려간다.
(절대값은 33Hz 로그를 100Hz 로 재구성한 탓에 부풀려져 있다. 차이만 유효하다.)

---

## 슬루 판정용 필드

출력 앞에 세 개를 붙였다.

```
t:23561,pre_pitch:-2.62,pre_roll:-8.91,pitch:2.36,ref_pitch:0.82,zv_pitch:0.82,...
```

| 필드 | 왜 |
|---|---|
| `t` | 펌웨어 시각. PC 수신 시각에는 USB 지터가 섞여 변화율 계산에 못 쓴다 |
| `pre_*` | 슬루 **걸기 전** 지령(`lpf_*`). `cmd` 와 다르면 잘린 것이고, 차이가 잘려나간 양이다 |

`cmd` 만 보면 잘린 흔적이 이미 지워져 알 수가 없다. `MAX_RATE = 120` 을 고른
근거가 이 `pre_*` 에서 나왔다.

기존 `ref_*` · `zv_*` 는 그대로다. 새 변수를 만든 게 아니라 이미 있는 `lpf_*` 를
출력에 실었을 뿐이라 제어 계산은 한 줄도 안 바뀌었다.

주기는 조건이 `> 20` 이라 10ms 루프에서 **30ms** 마다 나간다. 33Hz 다 (주석의 50Hz 수정).

---

## CAN 송신 대기 0

```cpp
if (twai_transmit(&m, 0) != ESP_OK) dgTxFail = dgTxFail + 1;   // sendMIT
```

`sendMIT` 은 50Hz 로 계속 나가는 주기 지령이라 한 장 버려도 20ms 뒤 다음 장이 간다.
반면 5ms 를 기다리면 두 축이 10ms — **한 틱 예산 전부**다.

**실측 근거.** 모터 전원을 끈 채 `arm` 하면 CAN ACK 가 없어 송신 큐가 막힌다.

| | 5ms 대기 | 대기 0 |
|---|---|---|
| `10ms초과` | **17** | **1** |
| `TX실패` | 36 | 36 |

실패 **횟수**는 같고 **대기 시간**만 사라진다 (송신 큐 5칸이 차면 그 뒤는 어차피 실패).
정상 CAN 에서는 큐가 안 차므로 `TX실패 0` 이고 동작이 같다.

남은 1건은 `motorsDisarm` 의 `broadcastUniversal(0xFD)` 다. `sendUniversal` 은
비주기 명령이라 **한 장이 중요해서 5ms 를 그대로 뒀다.** 2축 × 5ms + 1ms = 11.0ms 이고
실측 11,023 µs 와 맞는다. CAN 이 이미 죽었을 때 정지하는 순간 한 번이라 그대로 둔다.

---

## 실기 검산

`RTOS_DIAG` 계측을 넣고 실기에서 확인했다.
`t:` 간격만으로는 100Hz 누락을 못 잡는다 — 출력 게이트가 틱 안에 있어서
**틱 하나가 빠져도 앞뒤 출력이 30ms 로 보인다.** 그래서 틱 자체를 쟀다.

### 모터 전원 OFF, arm 안 함

```
최대틱 490~630us   10ms초과 0   재동기 0   TX실패 0   드롭 전부 0
```

### 모터 전원 ON, `arm`, 26초 캡처

```
최대틱 550~593us   10ms초과 0   재동기 1   TX실패 0   드롭 전부 0
피드백 2523회 (100/s = 50Hz × 2축)
```

`재동기 1` 은 `arm` 의 `delay` 250ms 때 한 번이다. 설계대로다.
계측 시작점을 명령 처리 **뒤**로 두었다. `arm` 의 의도된 정지를 같이 세면
(실측 270ms 로 찍혔다) 제어 틱이 늦었는지를 볼 수 없다.

### 3단계 로그와 비교

같은 도구(`capture.py` → `check_tuning.py`)로 같은 조건에서 비교했다.

| | 3단계 | 4단계 |
|---|---|---|
| pitch 드룹 | 89% | **89%** |
| pitch 추종오차 RMS | 3.31° | 3.18° |
| pitch 슬루 걸림 | 6% | 4% |
| roll 슬루 걸림 | 7% | 6% |
| pitch 요구 p95 | 101 °/s | 96 °/s |

**드룹이 정확히 같다.** 나머지 차이는 흔든 세기 차이다 (요구 변화율이 전반적으로
낮다 = 덜 세게 흔들었다). roll 드룹과 떨림은 계속 흔들어 정지 구간이 없어서
안 나왔다 — 다음에는 흔들다가 2초쯤 멈추기를 서너 번 섞어야 한다.

### 피드백 두절 워치독

모터 전원 없이 `arm` 했을 때 **302ms 만에 스스로 내려갔다.**

```
>>> ARMED  GAIN=1.00  ACC_GAIN=1.00  Kp=2.0  Kd=0.13  제한 ±25°
!! 피드백 302ms 끊김
>>> DISARM — 피드백 두절
```

---

## 되돌리기

3단계 [`ZV_입력성형.ino`](../%5B3%EB%8B%A8%EA%B3%84%5D%20ZV%20%EC%9E%85%EB%A0%A5%EC%84%B1%ED%98%95/ZV_%EC%9E%85%EB%A0%A5%EC%84%B1%ED%98%95.ino) 를 그대로 올리면 된다.
그 파일은 건드리지 않았다.

---

## 축별 게인 분리 (2026-09-01)

`b41de99` · 2026-09-01 10:04 푸시

> ⚠ **위의 절대 규칙("명령어·출력을 바꾸지 않는다")을 깬 변경이다.**
> 사용자 요청으로 넣었다. 명령 4개와 상태 출력 1줄이 늘었다.
> 제어 수식은 건드리지 않았다.

### 왜 필요했나

지령→실제 지연을 상호상관으로 쟀더니 두 축이 크게 달랐다. 두 번의 캡처에서
같은 값이 나왔다.

| 축 | 최적 지연 | 그때 상관 | 지연 0 에서 상관 |
|---|---|---|---|
| 안쪽 (PITCH, `0x02`) | **108 ms** | +0.961 | +0.681 |
| 바깥 (ROLL, `0x01`) | **189 ms** | +0.925 | **+0.192** |

지연을 보정하면 둘 다 지령을 잘 따라간다. **부호도 배선도 정상이고 바깥축이
느릴 뿐이다.** 다만 지연 0 에서의 상관이 +0.19 라, 지금 이 순간의 트레이
자세가 지금 필요한 자세와 거의 무관하다. 눈으로 보면 엉뚱하게 도는 것처럼
보이는 이유다.

189 ms 는 슬로싱 주기 420 ms 의 **45%**, 위상으로 162° 다. 거의 역위상이라
직전 반주기에 대한 보정이 지금 나타난다. 액체를 올리면 이 축은 슬로싱을
억제하지 않고 키운다.

힘이 모자란 것이 아니다. 추종률 **0.94** 로 크기는 충분히 간다. 대역폭이
문제고, 원인은 바깥축이 안쪽 짐벌과 트레이를 통째로 이고 있어 관성이 크기
때문이다. `ω ≈ √(Kp / J)` 이므로 하나의 `Kp` 로 두 축을 맞출 수 없다.

### 명령

| 명령 | 대상 | 예 |
|---|---|---|
| `kp<값>` `kd<값>` | 두 축 함께 (기존과 동일) | `kp2.0` |
| `kpp` `kdp` | 안쪽 `0x02` | `kpp2.0` |
| `kpr` `kdr` | 바깥 `0x01` | `kpr6` |

> ⚠ `kpp`/`kpr` 은 `kp` 보다 **먼저** 검사해야 한다. 순서가 뒤바뀌면
> `kpr6` 이 `kp` 접두에 걸려 `substring(2)` = `"r6"` → `toFloat()` = **0** 이
> 된다. 게인이 0 으로 조용히 들어가 모터가 풀린다.
> `ag` 를 `g` 보다 먼저 보는 것과 같은 함정이다.

게인을 바꾸면 항상 두 축을 나란히 찍는다. 한쪽만 올리고 다른 쪽을 잊는 것이
이 구조에서 가장 하기 쉬운 실수라서다. `Kp` 만 올리고 `Kd` 를 안 올리면
경고도 띄운다 — 바깥축은 1.75Hz 한계진동 이력이 있다.

### 기본값은 그대로 두었다

```cpp
KP_PITCH 2.0   KD_PITCH 0.13
KP_ROLL  2.0   KD_ROLL  0.13     // 올려야 할 쪽
```

189 → 108 ms 로 줄이려면 `ω` 를 1.75배, 즉 `Kp` 를 3배(2.0 → 6.0) 로 올려야
한다. 그러면 `ζ = Kd / 2√(Kp·J)` 가 √3 배 떨어지므로 `Kd` 도 1.7배
(0.13 → 0.22) 를 같이 올린다.

계산값은 출발점일 뿐이고, 발진 이력이 있는 축이라 컴파일에 박지 않았다.
`kpr`/`kdr` 로 올려가며 **지연을 다시 재서** 확정할 것.

### 아직 안 끝났다

`kpr4` `kdr0.22` 로 올린 상태에서도 바깥축이 반대로 도는 것으로 관측됐다.
`Kp` 2→4 는 `ω` 가 √2배라 지연이 189 → 약 134 ms, 위상 115° 로 예상된다.
나아지지만 여전히 늦다.

남은 판단.

| 항목 | 값 | 성격 |
|---|---|---|
| `CMD_LPF` 0.15 | τ ≈ 67 ms | **두 축 공통.** `Kp` 로는 이 아래로 못 내려간다 |
| ZV 성형 | +102 ms | 켜면 바깥축이 290 ms = 주기의 69% 가 된다 |

**바깥축 지연을 잡기 전에는 ZV 를 켜면 안 된다.**

부호 오류인지 지연인지는 **아주 느린 가속**으로 가른다. 느리면 지연이 문제가
안 되므로, 그때도 반대로 기울면 진짜 부호 오류이고 `DIR_ACC` 를 축별로 나눠야
한다. 툭툭 미는 동작으로는 둘을 구분할 수 없다.

---

## `.ino` 를 상위 폴더로 이동

`a962ca7` · 2026-09-01 14:04 푸시

```
[4단계] RTOS 태스크 분리/zv_shaping_rtos/zv_shaping_rtos.ino
   ↓
[4단계] RTOS 태스크 분리/zv_shaping_rtos.ino
```

다른 단계와 같은 구조로 맞췄다. `README.md` 와 이 파일의 링크 경로도 함께
고쳤다.

> 아두이노 IDE 는 스케치 폴더 이름과 `.ino` 이름이 같아야 연다. 중첩 폴더는
> 그 안내를 피할 수 있었는데, 이제 1~3단계 파일들과 마찬가지로 열 때
> "스케치 폴더를 만들어 옮길까요?" 가 뜬다.

---

## `kp6` 실측 (2026-09-01)

느린 가속 시험. `g1.0 ag1.0 zv0 kp6 kd0.22`.

| 축 | `kp2` 지연 | **`kp6` 지연** | 지연0 corr | 최적 corr | 추종 |
|---|---|---|---|---|---|
| PITCH (2번) | 108 ms | **60 ms** | +0.890 | +0.994 | 0.87 |
| ROLL (1번) | 189 ms | **90 ms** | +0.567 | +0.802 | **1.32** |

`Kp` 3배 → `ω` 1.73배 → 지연 절반. 예상대로다.

**지연 0 에서의 상관이 roll 도 양수(+0.567)로 올라왔다.** 부호가 뒤집혀 있다면
여기가 음수여야 한다. 제어식→지령→모터 사슬에 부호 오류는 없다.

### 남은 문제 — roll 감쇠 부족

추종이 **1.32** 다. `act` 가 `cmd` 보다 32% 더 간다. 최적 상관도 0.802 로
pitch(0.994) 보다 낮다. `kd0.22` 로는 `kp6` 을 못 잡는다.

`ζ = Kd / 2√(Kp·J)` 이므로 `Kp` 2→6 이면 `Kd` 는 0.13×√3 = 0.225 가 같은
감쇠비다. 계산상 맞춘 값인데도 부족하다는 것은 원래 이 축의 `ζ` 가 이미
빠듯했다는 뜻이다. `kdr0.3` 부터 올려볼 것.

---

## 회전시키면 부호가 뒤집힌다

roll 축이 슬로싱을 키우는 쪽으로 기운다고 관측됐던 건이 여기서 풀렸다.
**평행이동이 아니라 로봇 뒷부분만 밀어 회전시키고 있었다.** 좌우로 평행이동
시키면 pitch 와 똑같이 올바른 방향으로 기운다.

### 왜 그런가

제어는 이 전제 위에 있다.

```
IMU 가 느끼는 가속도  =  트레이(액체)가 느끼는 가속도
```

평행이동이면 강체의 모든 점이 같은 가속도를 받으니 성립한다. **회전이면
성립하지 않는다.**

```
a(점) = a_중심 + α × r + ω × (ω × r)
```

회전 중심에서 거리가 다르면 가속도가 다르고, **IMU 와 트레이가 회전 중심의
반대쪽에 있으면 부호까지 반대**가 된다. 뒷부분만 밀었을 때 IMU 는 크게
휘둘렸지만 트레이는 덜 움직였거나 반대로 움직였다.

### 시험 방법 문제가 아니다

**바퀴 로봇이 코너를 돌면 정확히 이 상황이다.** 제자리 선회든 곡선 주행이든
회전이 섞이고, 그때마다 IMU 와 트레이의 가속도가 달라진다.

### 고칠 재료는 이미 있다

```cpp
readIMU(ax, ay, az, gx, gy, gz);
//                          ^^ 읽기만 하고 쓰지 않는다
```

`gz`(요 각속도)로 지렛대 보정이 가능하다.

| 필요한 것 | 상태 |
|---|---|
| `gz` | 이미 읽고 있다 |
| `gz` 미분 (각가속도 α) | 계산 가능 |
| **IMU→트레이 거리 벡터 `r`** | **차체 완성 후 실측** |

차체가 확정되고 `r` 이 정해지면 넣는다. 지금 순서로는 지연 단축이 먼저다.

---

## 슬로싱 주파수 — 계산값과 실패한 측정

용기 11×11 cm, 물 350 mL → 수심 2.89 cm, `h/L = 0.263`.

```
직육면체 1차 모드   ω² = (πg/L)·tanh(πh/L)
                    f  = 2.194 Hz,  주기 456 ms
```

| 모드 | 주파수 |
|---|---|
| **1차** | **2.19 Hz** ← ZV 대상 |
| 2차 | 3.63 Hz |
| 3차 | 4.58 Hz |

정사각형이라 두 축의 슬로싱 주파수가 같다. `zf` 하나로 두 축을 덮는다.

기존 설정 2.40 Hz 는 **9.4% 높다.** 천수 근사 `√(gh)/2L = 2.42 Hz` 와 거의
같은데, `h/L = 0.26` 은 천수 영역이 아니라 `tanh` 를 살려야 한다.

### `act` 로 재려던 시도는 실패했다

모터를 켜두면 출렁이는 물이 트레이를 밀고, 그 흔들림이 `act` 에 잡힐 것이라
보고 `kp1.0` 으로 낮춰 캡처했다. **틀린 설계였다.**

- 용기가 트레이 위에 있어 **손으로 친 것과 물이 민 것을 구분할 수 없다**
- `Kp 1.0` 에서 트레이 자체 공진이 **0.8 Hz** 다. 슬로싱 2.2 Hz 보다 **아래**라
  트레이가 2.2 Hz 를 감지할 수 있는 조건이 아니었다

스펙트럼도 0.8 Hz 와 그 2배인 1.6 Hz 가 지배했고 2.2 Hz 에는 거의 없었다.
`Kp` 를 낮추면 민감해질 것이라 본 것부터 반대였다.

### 제대로 재려면 로봇을 쓰지 않는다

슬로싱 주파수는 용기와 물 높이만으로 정해진다. 짐벌도 모터도 무관하다.

```
1. 용기를 단단한 책상에 올린다
2. 10~15° 기울였다 놓는다
3. 옆에서 촬영 (슬로우모션이면 더 좋다)
4. f = 왕복 횟수 / 걸린 시간
5. 진폭이 절반 되는 데 n 주기 →  ζ ≈ 0.11 / n
```

`ζ` 는 계산으로 안 나온다. 오직 실측이다.

---

## 지연 계측용 `raw_pitch` / `raw_roll` 추가 (2026-09-01)

> **제어 로직은 변경하지 않았다.** `ACC_LPF` 적용 전 합력 목표각을 33 Hz
> 스트림에 두 필드로 추가한 계측 변경이다.

기존 출력에는 `ref`·`pre`·`cmd`·`act`가 있었지만 `ACC_LPF` 전의 값이 없어
전체 지연을 모터 구간과 소프트웨어 필터 구간으로 분리할 수 없었다. 아래 두 값을
추가했다.

```text
raw_pitch:<deg>,raw_roll:<deg>
```

신호 사슬은 다음처럼 해석한다.

```text
raw → ACC_LPF → ref → ZV → want → CMD_LPF → pre → slew → cmd → motor → act
```

변경은 세 곳뿐이다.

1. `Snap`에 `raw_p`, `raw_r` 두 `float` 추가
2. 같은 제어 틱의 지역변수 `raw_ref_p/r`을 스냅샷에 복사
3. `ioTask`의 `Serial.printf`에 두 필드 추가

`ctrlTask`의 목표각·필터·게인·슬루·CAN 계산은 바꾸지 않았다. 큐 항목이 8 byte
커졌고 32개 큐 기준 정적 사용량이 약 256 byte 증가한다. USB CDC 출력 한 줄도
길어지지만 포맷은 낮은 우선순위 `ioTask`에서 수행하므로 제어 주기는 막지 않는다.

이 변경을 사용한 재현 로그와 분석 절차는
[`지연_개선_실험/`](%EC%A7%80%EC%97%B0_%EA%B0%9C%EC%84%A0_%EC%8B%A4%ED%97%98/)에 있다.

---

## 가속 종료 소프트 복귀

`e054139` · 2026-09-03 23:01 푸시

`지연_개선_실험/soft_return_rtos.ino` 에서 제어 부분만 옮겼다. 그 파일에 있던
속도 피드포워드(`v_des`)와 CAN 진단은 **가져오지 않았다.**

### 무엇을 해결하려는가

직접보상 목표각은 **현재** 가속도만 본다. 그래서 가속이 끝나면 `θ_ref` 가
곧바로 0 으로 사라지고 트레이가 급히 수평으로 돌아온다. 그런데 액체는 과거
가속의 상태를 아직 갖고 있어서, 그 급정지가 **새 슬로싱을 만든다.**

가속 종료 시점에 남아 있는 목표각을 잠시 유지한 뒤 최소저크 곡선으로 0 까지
보낸다. **시작 구간은 건드리지 않으므로** 직접보상의 빠른 반응은 그대로다.

### 상태 기계 — 축마다 독립

```
DIRECT  →  HOLD  →  RETURN  →  LEVEL
```

| 상태 | 하는 일 |
|---|---|
| `DIRECT` | `ref` 를 그대로 통과. 평소 동작 |
| `HOLD` | 종료 시점의 `ref` 를 `SR_HOLD_MS` 동안 유지 |
| `RETURN` | `SR_RETURN_MS` 동안 최소저크로 0 까지 |
| `LEVEL` | 통과. 새 가속이 오면 `DIRECT` 로 |

종료 판정은 **`ACC_LPF` 를 걸기 전의 `raw_ref`** 로 한다. 필터를 통과한 값은
가속이 끝나도 꼬리가 남아 판정이 늦다.

```cpp
if (a <= SR_END_DEG) {
  if (++s.quietTicks >= dwellTicks) {
    s.holdAngle = ref;       // 현재 출력과 같아 진입 시 불연속이 없다
```

`holdAngle` 을 `ref`(필터 통과값)로 잡는 것이 요점이다. 판정은 `raw_ref` 로
빠르게 하고, 유지할 값은 지금 실제로 나가고 있는 값을 쓴다. 그래서 상태가
바뀌는 순간 목표각에 계단이 생기지 않는다.

최소저크 곡선은 5차 다항식이다.

```cpp
float smooth = x * x * x * (10.0f + x * (-15.0f + 6.0f * x));
float out = s.holdAngle * (1.0f - smooth);
```

시작과 끝에서 속도·가속도가 모두 0 이라 복귀 자체가 슬로싱을 새로 만들지
않는다. 선형 램프는 양끝에서 가속도가 튄다.

### 새 가속이 꼬리보다 우선한다

```cpp
if (s.phase != SR_DIRECT && a >= SR_ACTIVE_DEG) {
  softReturnResetAxis(s);
  s.sawActive = true;
  return ref;
}
```

`HOLD`/`RETURN` 중에 새 가속이 들어오면 즉시 `DIRECT` 로 돌아간다. 꼬리를
지키느라 실제 가속을 놓치면 본래 목적에 어긋난다. 전환 계단은 `CMD_LPF` 와
슬루가 제한한다.

### ZV 와 동시에 쓰지 않는다

목적이 겹친다. 둘 다 목표각을 성형해 슬로싱을 줄이는 것이라 겹쳐 쓰면
서로의 타이밍을 무너뜨린다. `sr1` 이 `ZV_ON` 을 끄고, `zv1` 이
`SOFT_RETURN_ON` 을 끈다.

```cpp
if (SOFT_RETURN_ON)      shaped = softReturnStep(...)
else if (ZV_ON)          shaped = ZV 성형
else                     shaped = ref
```

### 명령

| 명령 | 기본 | 뜻 |
|---|---|---|
| `sr1` / `sr0` | **꺼짐** | 켜기 / 끄기 (켜면 ZV 자동 꺼짐) |
| `sra<값>` | 1.50° | 이 이상을 실제 가속으로 인정 |
| `sre<값>` | 0.75° | 이 아래가 지속되면 종료 |
| `srd<값>` | 30 ms | 종료 확인 시간 |
| `srh<값>` | 100 ms | 남은 목표각 유지 시간 |
| `srr<값>` | 120 ms | 최소저크 복귀 시간 |

> ⚠ `sra`/`sre`/`srd`/`srh`/`srr` 은 `sr` 보다 **먼저** 검사해야 한다.
> 순서가 뒤바뀌면 `sra2` 가 `sr` 접두에 걸려 `substring(2)="a2"` →
> `toInt()=0` 으로 소프트복귀가 조용히 꺼진다. `ag`/`g`, `kpr`/`kp` 와 같은
> 함정이다.

`sra > sre` 를 명령 단계에서 검사한다. 뒤집히면 종료 판정이 성립하지 않는다.

### 상태는 ctrlTask 만 만진다

```cpp
if (srResetRequest || !SOFT_RETURN_ON) {
  softReturnReset();
  srResetRequest = false;
}
```

`ioTask` 는 설정값만 바꾸고 `srResetRequest` 를 세운다. 축 상태(`phase`,
`quietTicks`, `holdAngle`)는 `ctrlTask` 하나만 초기화·갱신한다. 두 태스크가
같은 상태 기계를 만지면 전환 도중의 조합이 나온다.

`arm`/`disarm` 에서도 초기화한다. 기울어진 채 남은 `holdAngle` 이 다음 arm
때 되살아나지 않게 한다.

### 아직 실측 전이다

기본값 `100ms 유지 / 120ms 복귀` 는 팀원분이 정한 출발점이고, 물을 올린
상태에서 확인한 값이 아니다. 슬로싱 주기(11×11 용기, 350mL 에서 456ms)와의
관계를 재봐야 한다.

### `?` 에 성형기 상태를 넣었다

`1fc56cc` 까지는 `?` 를 쳐도 ZV 와 소프트복귀가 켜져 있는지 알 수 없었다.
ZV 는 처음부터 `printStatus` 에 없었고, 소프트복귀 줄은 넣었다고 적었는데
치환이 조용히 실패해 실제로는 안 들어가 있었다.

```
       ZV OFF   2.40Hz  z=0.020  2임펄스  지연 +102ms
       소프트복귀 ON    sra 1.50°  sre 0.75°
                       srd 30ms(확인)  srh 100ms(유지)  srr 120ms(복귀)
       소프트복귀 상태  안쪽 HOLD / 바깥 DIRECT
```

값마다 **어느 명령으로 바꾸는지 이름을 붙였다.** 표를 다시 찾지 않고 바로
고칠 수 있다. 헤더 주석의 명령표에도 `sr` 계열 6개를 넣었다.

세 번째 줄은 지금 어느 국면인지 보여준다. 밀었다 놓고 바로 `?` 를 치면
`HOLD` 나 `RETURN` 이 잡힌다. 성형이 실제로 도는지 눈으로 확인할 수 있는
유일한 수단이다 — `zv_pitch` 는 스트림에 있지만 국면은 로그에 없다.

---

## 합력각 직접 방식으로 바꿨다

`37f9c0e` · 2026-09-03 23:33 푸시

팀원분의 `zv_shaping_rtos__direct_force_sr_v2.ino` 에서 제어 개선 네 가지만
가져왔다. 기본값 변경과 속도 피드포워드는 **가져오지 않았다.**

### 1. θ_ref — 중력 제거 대신 합력각을 직접 쓴다

```cpp
// 전 : 중력을 빼서 선형가속을 복원한 뒤 각도로
p_lin     = ay - one_g * sin(θ_base);
raw_ref_p = -atan2(p_lin, one_g);

// 후 : 합력 벡터의 방향을 그대로
force_pitch = atan2(force_ay, √(force_ax² + force_az²));
ref_pitch   = θ_base - force_pitch;
```

두 방식 다 최종 지령에서 `θ_base` 가 소거된다.

```
want = ACC_GAIN·ref − GAIN·θ_base = −θ_force      (GAIN = ACC_GAIN 일 때)
```

차이는 정확도다. 예전 방식은 `one_g` 를 **상수**로 썼는데, 가속 중에는 비력의
크기가 `g` 가 아니다. 그래서 경사면에서 가속할 때 오차가 남았다.

| 차체 기울기 | 가속 | 정답 | 새 방식 | 예전 방식 |
|---|---|---|---|---|
| 0° | 0.3g | −16.70° | −16.70° | −16.70° |
| 20° | 0.3g | −16.70° | −16.70° | **−15.74°** |
| 30° | 0.3g | −16.70° | −16.70° | **−14.56°** |

30° 에서 2.1° 덜 기운다. 합력각 방식은 벡터의 **방향만** 보므로 모든 각도에서
정확하고 `g_scale` 오차에도 영향을 받지 않는다.

### 2. 각도가 아니라 벡터를 거른다

```cpp
force_ax = ACC_LPF * ax + (1 - ACC_LPF) * force_ax;   // 성분 상태에서
... 3축 모두 ...
force_pitch = atan2f(force_ay, ...);                  // 그 뒤 한 번만 각도로
```

축별로 각도를 따로 거르면 두 축이 동시에 움직일 때 벡터의 길이와 방향이 서로
어긋난다. `ACC_LPF` 의 의미가 "목표각 필터" 에서 "3축 벡터 필터" 로 바뀌었다.
기본값 0.20 은 그대로 두었다 — 1차 필터라 시간상수가 같다.

### 3. SR 에 CONFIRM 단계 — 붙잡는 각도가 안 깎인다

```cpp
// 전 : dwell 이 끝난 뒤에 잡는다
if (s.quietTicks >= dwellTicks) { s.holdAngle = ref; }

// 후 : 문턱을 넘는 순간 직전 값을 잡고, 확인은 CONFIRM 에서
s.holdAngle = s.lastActiveAngle;
s.phase = SR_CONFIRM;
```

예전 방식은 30ms 의 dwell 동안 `ACC_LPF` 가 이미 목표각을 0 쪽으로 깎아놓아
**HOLD 가 실제 피크보다 약했다.** 문턱을 넘기 직전 값을 따로 들고 있다가
(`lastActiveAngle`) 그것을 붙잡는다.

`CONFIRM` 중에 가속이 다시 올라오면 `DIRECT` 로 되돌아간다. 오판을 물릴 수
있게 됐다.

```
DIRECT → CONFIRM → HOLD → RETURN → LEVEL
            ↑ 여기서 되돌아갈 수 있다
```

### 4. 자세 보정 게이트

자이로 예측과 가속도계 각이 `SR_ACTIVE_DEG` 이상 벌어지면 그 축은 자이로
예측만 쓴다. 상보필터가 수평가속을 기울기로 학습하는 것(경사/가속 모호성)을
막는다.

> ⚠ **이 게이트는 모터 지령을 바꾸지 않는다.** `want = ref − θ_base` 에서
> `ref = θ_base − θ_force` 이므로 `θ_base` 가 소거되기 때문이다.
> 게이트가 있든 없든 지령은 `−θ_force` 다.
>
> 바뀌는 것은 두 가지다.
>
>   1. 로그의 `pitch` / `ref` 값이 정직해진다
>   2. **SR 의 종료 판정이 정직해진다** ← 실질적 이득
>
> 게이트가 없으면 가속 중 `θ_base` 가 가속을 흡수해 `raw_ref` 가 씻겨나가고,
> SR 이 "가속이 끝났다" 고 조기 오판한다.

`?` 에 `자세보정게이트 TRACK/BLOCK` 으로 현재 상태가 나온다.

### 가져오지 않은 것

| 항목 | v2 | 여기 | 이유 |
|---|---|---|---|
| `MAX_RATE` | 60 | **120 유지** | `결과_분석.md` 가 요구 변화율 p95 를 109~112 로 측정했다. 60 이면 절반이 잘린다 |
| `SOFT_RETURN_ON` | true | **false 유지** | 올려도 동작이 안 바뀌어야 한다는 규칙 |
| `KP_PITCH`/`KD_PITCH` | 4.0/0.20 | **2.0/0.13 유지** | 실험이 채택한 값은 2.0/0.13 이다 |
| `CMD_LPF` | 0.30 | **0.15 유지** | 실험은 0.30 을 지지하지만 이번 변경과 섞지 않는다 |
| 속도 피드포워드 | 있음 | **없음** | 앞서 제거하기로 한 건 |

### ZV 와의 관계 — 아직 정리 안 됨

시뮬레이션상 2.19Hz 를 안 깨우려면 어떤 방법이든 한 주기(456ms)에 걸쳐
움직여야 한다. ZV 는 그 구조가 주기에서 유도되지만, SR 의 세 시간
(30+100+120 = 250ms)은 슬로싱 주기와 무관하게 정해진 값이다.

그리고 **SR 은 종료 구간만 손댄다.** 가속이 시작될 때의 급변은 그대로다.
ZV 는 양쪽을 모두 성형한다.

지금 코드는 둘을 상호배타로 묶어놓았는데, 역할이 겹친다기보다 SR 이 ZV 의
부분집합에 가깝다. 주파수를 실측한 뒤 다시 볼 문제다.

---

## 실측 기본값

`c8d912d` · 2026-09-04 02:13 푸시

```cpp
KP_PITCH 4.0    KD_PITCH 0.20    MAX_RATE 120    CMD_LPF 0.30    CAN_DIV 1    ZV_ON true
```

카트 위에서 pitch 축을 20초씩 밀며 사슬을 구간별로 잘라 쟀다. 한 번에 하나씩 바꿨다.

| 구간 | `f0.15 d2` | `f0.30` | `f0.30 d1` |
|---|---|---|---|
| ACC_LPF | 10 | 10 | 10 |
| ZV | 100 | 100 | 100 |
| **CMD_LPF** | 40 | **15** | 15 |
| 슬루 (`r120`) | 0 | 0 | 0 |
| **모터** (`kpp4 kdp0.2`) | 75 | 75 | **60** |
| **구간 합** | **225** | **200** | **185** |

두 변경 다 예측한 자리에서 예측한 만큼 빠졌고 상관 0.99 이상으로 안정성 손상은 없다.
슬루는 `r120` 에서 클리핑 0% — 병목이 아니다.

### `kpp6 kdp0.25` 는 두 번 다 실패했다

한 번은 arm 3초 만에 CAN 피드백 두절(`TX실패 58`), 한 번은 arm 도 못 갔다. 그 뒤
직접 돌려본 결과는 **모터가 뚝뚝 끊기고 액체가 요동**. `Kd` 는 엔코더 속도 잡음을,
`Kp` 는 IMU 잡음 한 눈금을 그대로 토크 계단으로 만든다. 그 고주파 떨림이 물의
2·3차 모드(3.6/4.6Hz)를 직접 친다. CAN 이 죽은 것도 토크 스파이크 → 24V 처짐으로
보인다.

**모터 구간 60ms 가 이 하드웨어의 바닥이다.** 지연을 강성으로 더 줄이는 길은
닫혔고, 총지연 85ms(ZV 제외) 위에서 설계해야 한다. 매끄러움이 지연만큼 중요하다는
것도 여기서 확인됐다.

### 슬로싱 실측 2.0 Hz

`g0 ag0 zv0 arm` 으로 트레이를 고정 용기처럼 붙잡고 카트를 밀어 수면을 셌다.
**1초에 2회 왕복, 주기 500ms.** 책상 계산값 2.19Hz 보다 9% 낮은데, 짐벌이
완전 강체가 아니라 결합계 주파수가 내려간 것으로 본다.

### `zf` 는 아직 2.40 이다

실측 2.0 과 20% 어긋나지만 그대로 두었다. 두 목표가 충돌하기 때문이다.

| `zf` | ZV 자체 상쇄 | 밀기 슬로싱 반대위상 (지연 85ms 포함) |
|---|---|---|
| 2.40 | 80% | **86%** |
| 2.00 | **99%** | 48% |

두 번째 임펄스가 물에 닿는 시각은 `85ms(지연) + 간격` 인데, 밀기가 만든 슬로싱의
반대 위상은 250ms 다. `zf2.4` 의 간격 208ms 가 우연히 그 근처(293ms)에 앉아 있어
"반대 위상 한 방에 잡히는" 것이 보인다. `zf2.0` 이면 335ms 로 밀려 절반으로 약해진다.

지연이 0 이면 두 최적이 250ms 로 일치한다. 지연이 85ms 로 고정된 지금은 절충점을
눈으로 A/B 해서 정한다. 결과가 나오면 여기 적는다.

---

## 각도 상한을 기구 한계까지

`0d9216a` · 2026-09-04 02:29 푸시

```
ACC_REF_LIMIT   20° → 45°     합력 목표각 상한  (0.36g → 1.0g)
LIMIT_DEG       25° → 45°     지령 상한
ACT_LIMIT_DEG   50° → 55°     폭주 차단 (지령 상한 +10°)
```

### 세게 밀어도 트레이가 더 안 기울던 이유

세 캡처 모두 `raw_pitch` 최대가 **정확히 20.0°** 였다. `ACC_REF_LIMIT` 에 잘린
것이다. 보통 리듬으로 밀 때도 1.4~2.6% 가 상한에 붙어 있었고, 세게 밀면
그 비율만 올라갈 뿐 트레이는 20° 에서 멈춘다. 20° 는 0.36g 다.

그 위에 사슬 손실이 곱해진다 — ACC_LPF 0.75, ZV 0.83, 모터 0.95 — 그래서
실제 `act` 는 9~12° 에서 끝났다. 짧고 센 밀기일수록 필터가 더 깎는다.

`want` 의 25° 상한과 슬루(`r120`)는 안 걸렸다.

기구 한계가 45° 로 확인돼 세 값을 거기 맞췄다. 폭주 차단은 지령 상한 바로
위에 두면 정상 동작이 차단에 걸리므로 10° 여유를 둔다.

> 목표가 커지면 요구 변화율도 커진다. 전에 17° 목표에서 155°/s 가 나왔으니
> 40° 목표면 `r120` 이 잘라낼 수 있다. `pre` 와 `cmd` 의 차이로 확인할 것.

### 위상 문제는 센서 없이는 우연이다 — 받아들이기로 했다

밀기가 이미 만든 출렁임을 트레이가 반대 위상으로 잡는 것은 **가끔** 된다.
트레이의 타이밍은 밀기 시작 시점에 고정(지연 85ms + ZV 간격)돼 있고 액체의
위상은 밀기의 길이·모양에 따라 매번 다르기 때문이다. 겹치면 거의 안 흔들리고,
어긋나면 오히려 키운다. 우연의 분포다.

이걸 우연이 아니게 만들려면 액체의 위상을 아는 신호가 필요하다.

| 방법 | 결론 |
|---|---|
| 트레이 IMU 를 루프에 | 시도해봤으나 **물이 너무 가벼워 IMU 가 액체 상태를 못 읽는다** |
| 별도 액체 센서 | 지금 살 수 없다 |
| 차체 IMU 에서 반작용력 대역통과 | 트레이 IMU 도 못 읽는 힘이 차체까지 올 가능성은 낮다 |

**차체 IMU 만으로 하는 개루프의 한계로 받아들인다.** ZV 가 보장하는 것은
트레이 자신의 움직임이 출렁임을 만들지 않는 것까지이고, 밀기가 만든 출렁임에
대한 위상은 보장하지 않는다.

이 결정의 함의 하나 — `zf` 는 실측값 2.0 이 맞다. 2.4 가 좋아 보였던 것은
반대 위상 우연이 잘 맞은 경우였는데, 그 우연을 포기하기로 했으니 남는 것은
ZV 가 **보장하는** 자체 상쇄이고, 그것은 `zf` 가 정확할 때 최대다.

---

## `zf` 를 실측값 2.00 으로

`188e86a` · 2026-09-04 02:44 푸시

```cpp
volatile float ZV_FREQ = 2.00f;   // 2.40 에서
```

2.40 은 이전 서보 코드에서 역산한 값이었다. 카트 위에서 잰 2.0 이 이 리그의
값이다. ZV 반주기 간격이 208ms 에서 **250ms** 로 바뀐다.

눈으로 A/B 한 결과 2.0 이 낫다고 판단됐고, 위상 문제를 우연으로 받아들이기로
한 결정과도 맞는다 — 남는 것은 ZV 가 보장하는 자체 상쇄이고 그것은 `zf` 가
정확할 때 최대다 (20% 오차에서 잔류 ~20%, 정확할 때 ~1%).

물 높이나 용기가 바뀌면 다시 잰다. 계산상 350mL 기준이고, 높이가 절반이면
주파수가 약 15% 내려간다.

---

## 가속도계 LPF2

`a329132` · 2026-09-04 03:01 푸시

```
CTRL1_XL  0x68 → 0x6A     LPF2_XL_EN
CTRL8_XL  (신규) 0x40     HPCF_XL = 010 → 차단 ODR/20 ≈ 20.8Hz
```

### "세게 밀어도 트레이가 안 커진다" 의 진짜 원인

45° 상한을 풀고 세게 밀어 캡처했더니:

```
raw 45.0  →  ref 19.1  →  zv 15.7  →  cmd 15.2  →  act 12.7
```

슬루는 안 걸렸다(`pre−cmd` 최대 2.3°). 손실은 `raw → ref`, 즉 ACC_LPF 였다.
그런데 파형을 펼쳐 보니 `raw` 의 ±45° 는 **전부 30ms 단발이고 샘플마다
부호가 뒤집혔다.** 밀기가 아니라 바퀴·바닥 충격이다.

```
 6.12~6.30 s   raw +3 → +9 → +7   ref +2 → +10          ← 실제 밀기 (약 0.5초)
 6.48 s        raw +39.9           ref +17.5             ← 30ms 충격 하나
 6.84/6.99/7.14  raw −40 / +43 / −45                     ← 충격, 부호 교대
 7.2~7.5 s     raw −8 ~ −10        act −11               ← 제동. 트레이가 따라감
```

**지속되는 가속은 8~10° = 0.15~0.18g** 이고 트레이는 그것을 −11° 까지
따라갔다. 손으로 카트를 밀어 0.2g 이상을 지속시키기는 어렵다. 더 세게
밀면 충격만 커진다. **트레이는 낼 수 있는 가속에 맞는 각도까지 정확히
가고 있었다.** 상한이 문제였던 것이 아니라 거기까지 갈 가속이 없었다.

### 그래도 고칠 것이 있었다

충격 하나가 `ref` 를 실제 가속의 두 배(17.5°)로 튀게 했다. 가속도계가
416Hz 로 돌면서 내부 필터 없이(대역 208Hz) 100Hz 로 읽히니 진동이
앨리어싱으로 접혀 들어온 것이다. 그것을 막느라 `ACC_LPF` 를 0.20 으로
무겁게 두었고, 그 대가로 진짜 가속의 진폭도 25% 깎였다.

센서 안에서 미리 거른다. 차단 20.8Hz 는 나이퀴스트(50Hz) 아래에 넉넉히
있고 슬로싱(2Hz)·제어 대역에는 ~10ms 만 얹는다.

`CTRL1_XL_VAL` 이 바뀌었으므로 센서 리셋 감지(`readReg(REG_CTRL1_XL) !=
CTRL1_XL_VAL`)도 새 값과 비교한다.

### 다음

`raw` 가 깨끗해졌는지 캡처로 확인한 뒤, `ad` 를 0.20 → 0.30~0.40 으로 풀어
진짜 가속의 진폭 손실을 되찾는다. 그 전까지 `ad0.20` 유지.

---

## 모터 피드포워드

`56440cd` · 2026-09-04 03:28 푸시

```
ff1 / ff0     켜기 / 끄기        ★ 기본 꺼짐
fj<값>        안쪽 관성 J        ★ 0.0038 kg·m²  (실측)
fjr<값>       바깥 관성 J        ★ 0  (미측정 → 관성 항 없음, v_des 만)
```

### 왜

모터 구간 지연 70ms 가 총지연의 절반 이상인데 `Kp` 로는 못 내린다는 것이
확인됐다 (`kpp6` — 토크 계단, 물 요동, CAN 두절). 그런데 빠른 서보는 원래
강성이 아니라 **피드포워드**로 대역폭을 얻는다. HIWIN 백서가 말하는 "응답
시간이 결정적" 인 시스템들이 그렇게 한다.

MIT 프레임에는 그 자리가 이미 있다.

```
τ = Kp·(p_des − p) + Kd·(v_des − v) + t_ff
                          ↑ 0                ↑ 0     ← 지금까지 비워둠
```

지령은 CMD_LPF·슬루를 거친 매끈한 신호라, 미분해도 잡음이 늘지 않는다.
`Kp`/`Kd` 를 올리는 것과 결정적으로 다른 점이다.

### J 추정

`Kp4 Kd0.2` 로그 세 개에서 `Kp·(cmd−act) = J·θ̈ + b·θ̇ + c·sgn(θ̇)` 을
최소제곱으로 맞췄다.

| 로그 | J [kg·m²] | b [N·m·s] | c [N·m] | R² | fn | ζ |
|---|---|---|---|---|---|---|
| `lag_d1` | 0.0040 | 0.208 | 0.021 | 0.89 | 5.0 Hz | 0.82 |
| `lpf2` | 0.0034 | 0.202 | 0.026 | 0.88 | 5.4 Hz | 0.86 |
| `hard_push` | 0.0039 | 0.210 | 0.015 | 0.83 | 5.1 Hz | 0.84 |

세 로그가 일치한다. `b ≈ 0.21 = Kd` 라 **모터를 끌어당기는 것이 거의 전부
`Kd·v` 항**이고 마찰은 무시할 만하다. `v_des = θ̇_cmd` 를 주면 그 항이
추종 중에 사라지고, `t_ff = J·θ̈_cmd` 가 관성을 미리 민다.
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

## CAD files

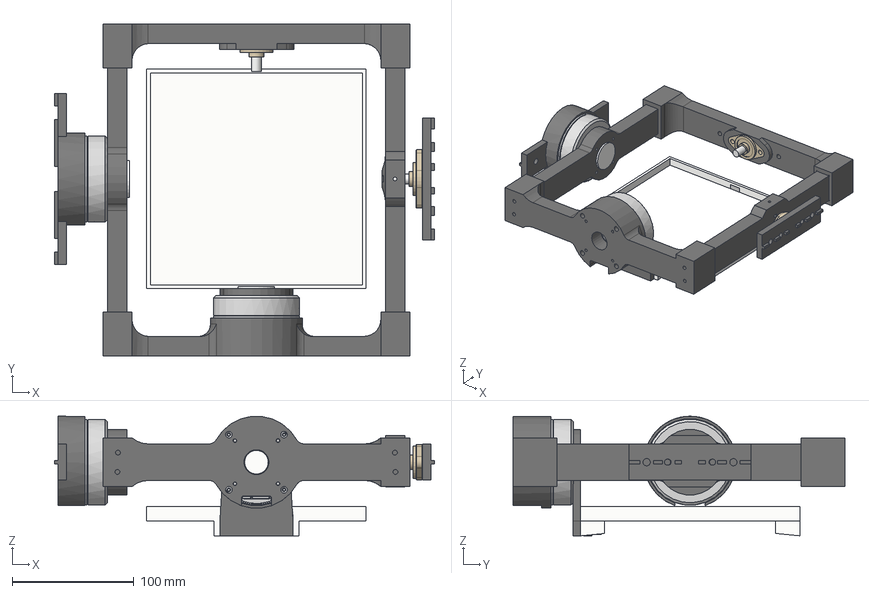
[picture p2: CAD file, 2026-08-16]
hardware/CAD/step 파일 모음/수하물_트레이.step
311.6 x 272.1 x 98.2 mm

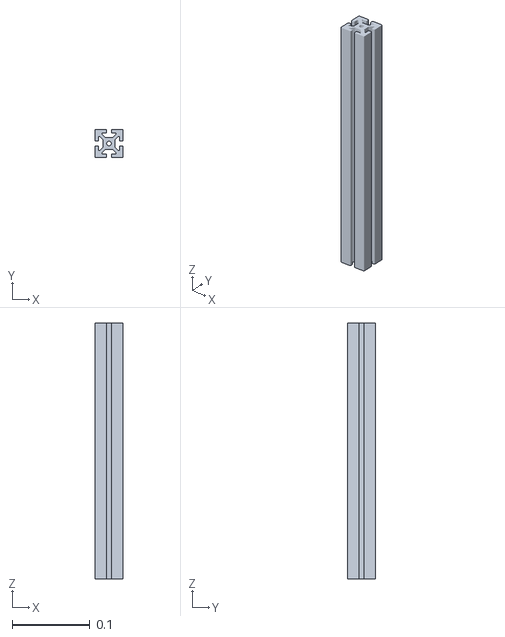
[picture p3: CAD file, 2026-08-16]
hardware/CAD/new_robot/meshes/Default.stl
0.036 x 0.036 x 0.33

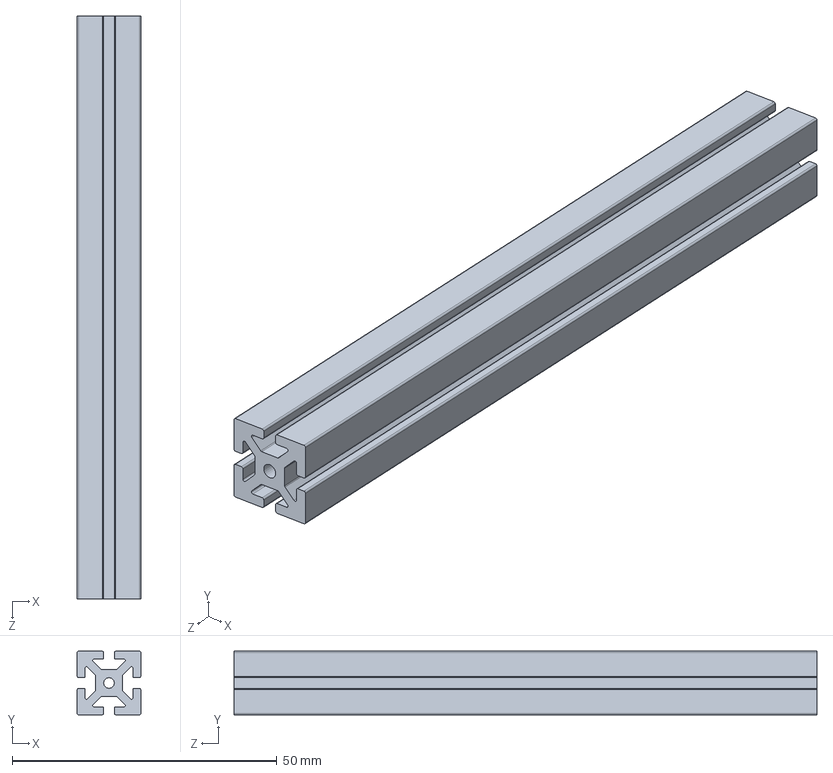
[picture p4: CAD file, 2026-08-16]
hardware/CAD/step 파일 모음/80-20 Extrude aliminium.SLDPRT
12.0 x 12.0 x 110.0 mm

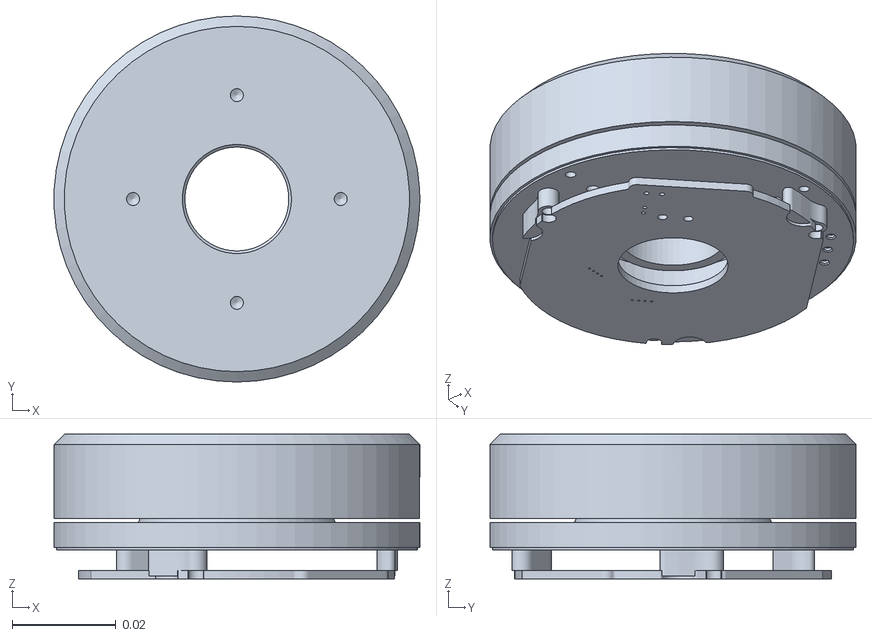
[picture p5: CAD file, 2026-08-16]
hardware/CAD/new_robot/meshes/M3_______1.stl
0.0704 x 0.0705 x 0.0279

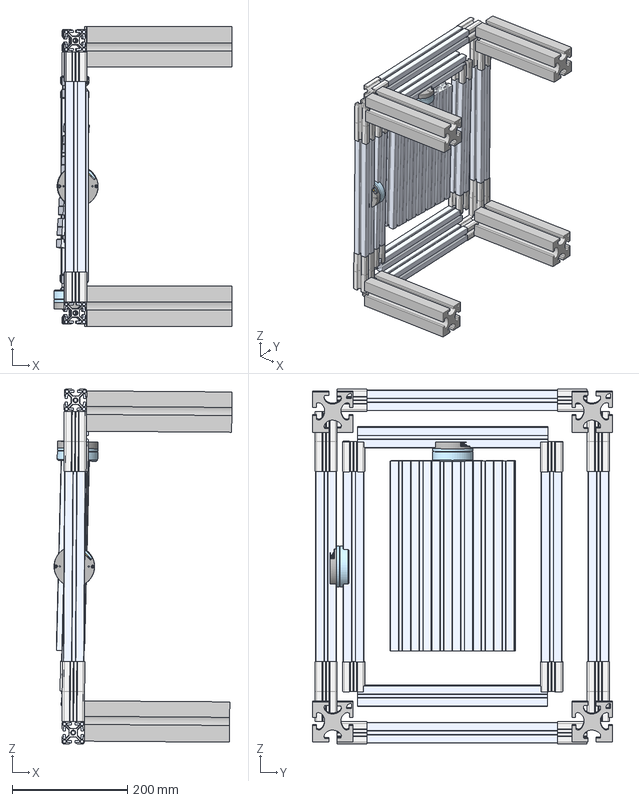
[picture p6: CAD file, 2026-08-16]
hardware/CAD/step 파일 모음/new_robot_tray_part.step
308.9 x 520.1 x 616.2 mm
BJJ02040274-GL60II�ű��-1-solid1 x 2
GB_FASTENER_SCREWS_HSHCS M3X5-S-1-solid1 x 2
M3 ���ƿ�1 x 2
GL60_V1.0-240806A-1-solid86 x 2
GB_FASTENER_SCREWS_HSHCS M3X5-S-4-solid1 x 2
GB_FASTENER_SCREWS_HSHCS M3X5-S-2-solid1 x 2
GL60_V1.0-240806A-1-solid87 x 2

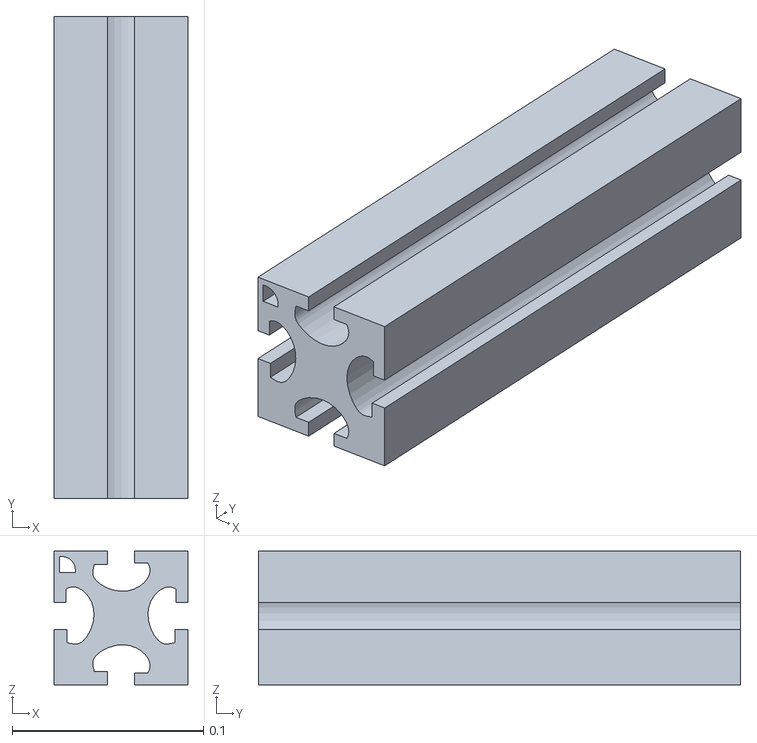
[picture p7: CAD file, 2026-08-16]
hardware/CAD/new_robot/meshes/Body2.stl
0.07 x 0.252 x 0.07

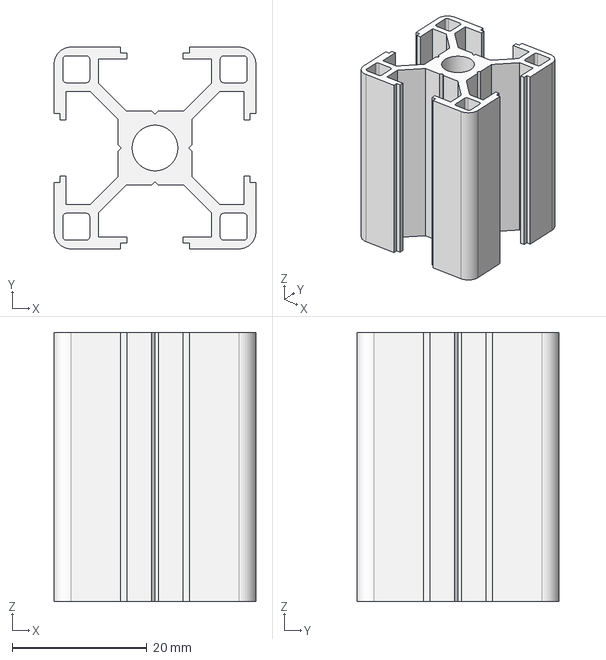
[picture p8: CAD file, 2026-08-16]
hardware/CAD/step 파일 모음/Aluminum profile 3030 OB3030Q.stp
30.0 x 30.0 x 40.0 mm

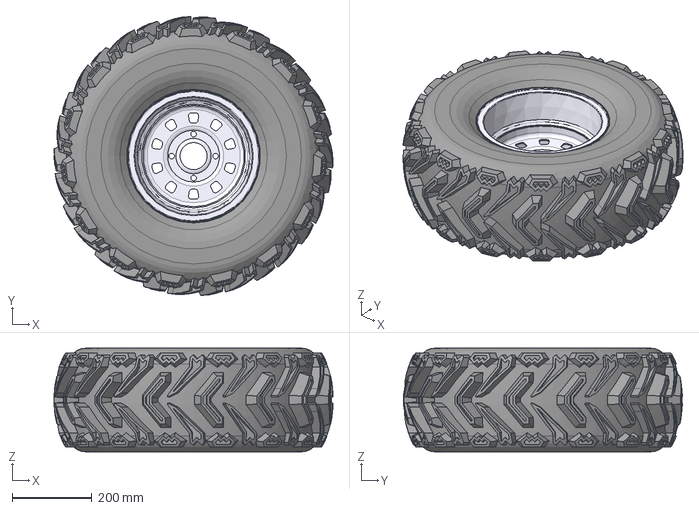
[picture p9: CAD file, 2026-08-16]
hardware/CAD/step 파일 모음/Wheel BKT W 207_1.stp
699.2 x 699.2 x 260.0 mm
Колісний диск
Шина700

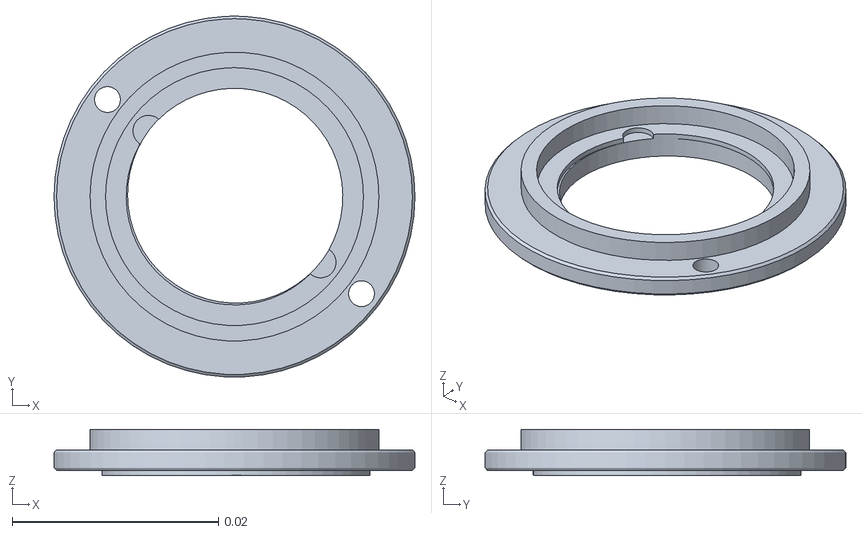
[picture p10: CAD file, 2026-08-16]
hardware/CAD/new_robot/meshes/NONE.stl
0.035 x 0.035 x 0.0045

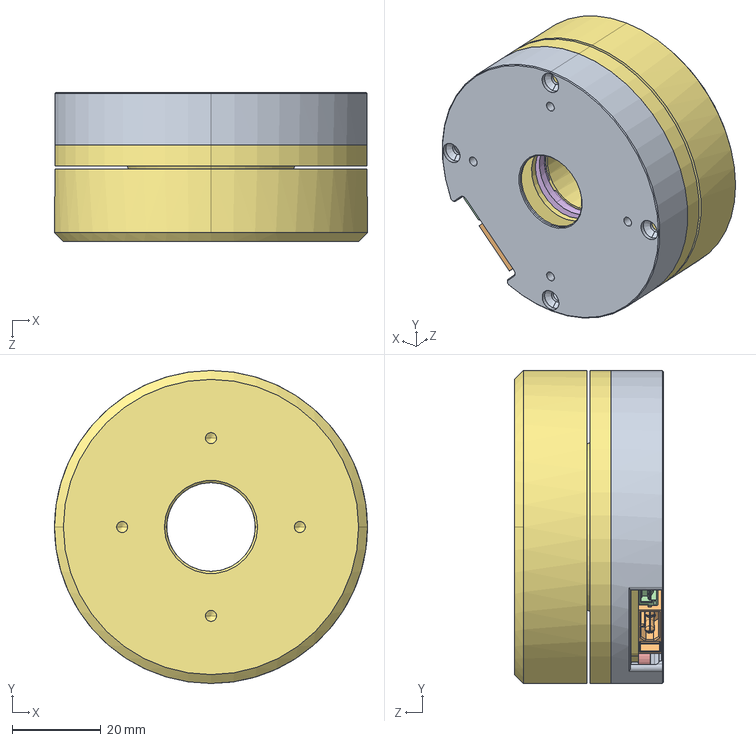
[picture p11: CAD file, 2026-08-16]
hardware/CAD/step 파일 모음/GL60II-3D.STEP
70.5 x 70.5 x 33.6 mm

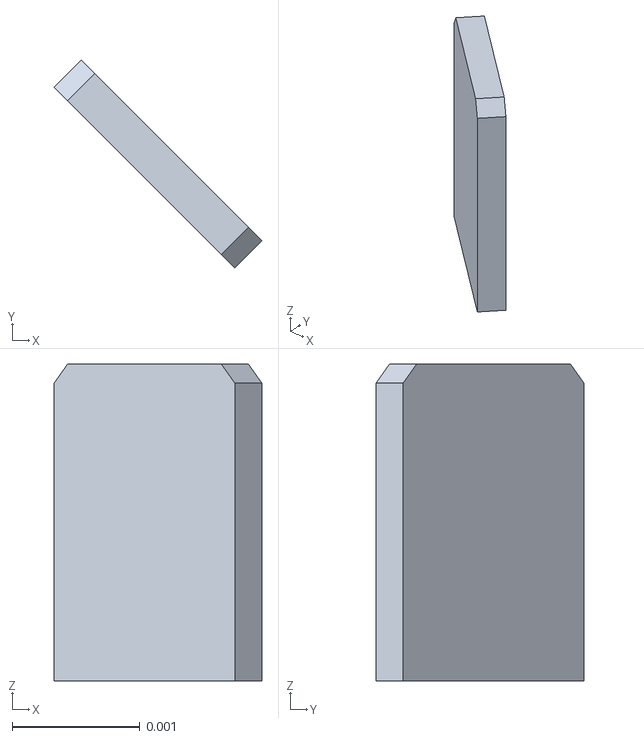
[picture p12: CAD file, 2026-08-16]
hardware/CAD/new_robot/meshes/GL60_V1_0_240806A_1_solid86.stl
0.00163 x 0.00163 x 0.00248

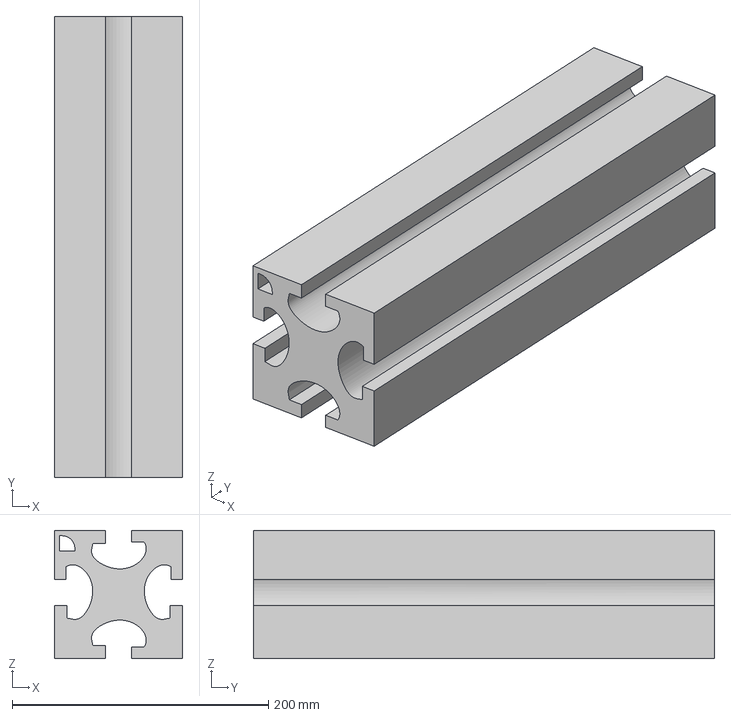
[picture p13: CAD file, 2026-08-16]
hardware/CAD/step 파일 모음/sample.step
100.0 x 360.0 x 100.0 mm

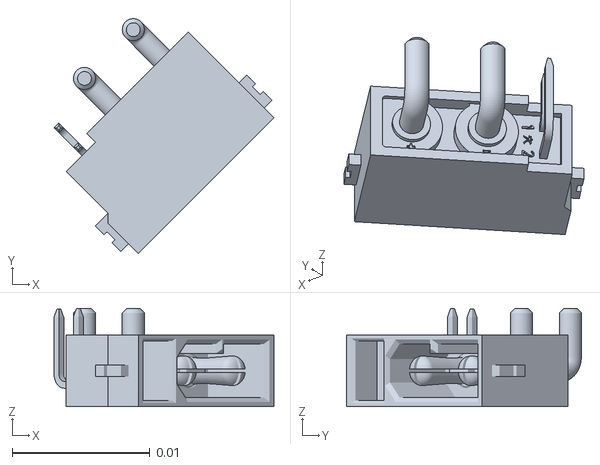
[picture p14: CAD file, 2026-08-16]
hardware/CAD/new_robot/meshes/NONE_1.stl
0.0159 x 0.017 x 0.00712

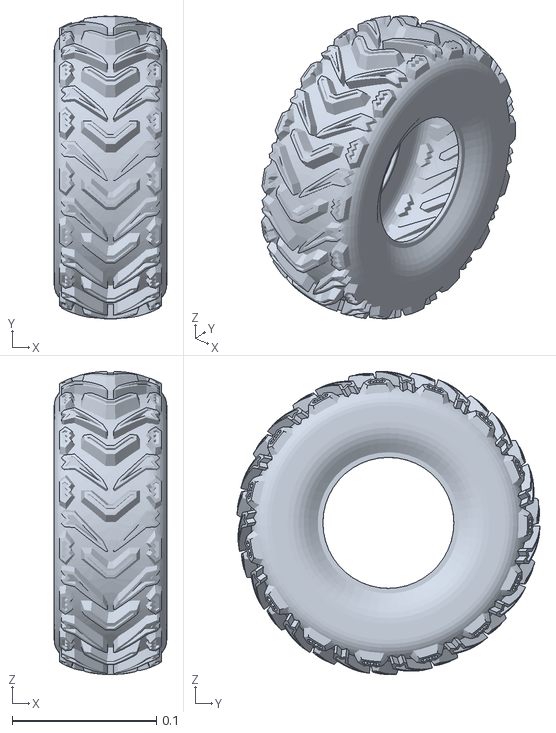
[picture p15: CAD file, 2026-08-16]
hardware/CAD/new_robot/meshes/____700.stl
0.078 x 0.21 x 0.21

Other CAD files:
hardware/CAD/new_robot/meshes/_____________.stl
hardware/CAD/new_robot/meshes/Part_1.stl
hardware/CAD/new_robot/meshes/GL60_V1_0_240806A_1_solid87.stl
hardware/CAD/new_robot/meshes/BJJ02040274_GL60II_______1_solid1.stl
hardware/CAD/new_robot/meshes/GB_FASTENER_SCREWS_HSHCS_M3X5_S_1_solid1.stl
hardware/CAD/new_robot/meshes/GB_FASTENER_SCREWS_HSHCS_M3X5_S_2_solid1.stl
hardware/CAD/new_robot/meshes/GB_FASTENER_SCREWS_HSHCS_M3X5_S_4_solid1.stl

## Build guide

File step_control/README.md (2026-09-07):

## 참고

- [Pololu DRV8825 Stepper Motor Driver Carrier](https://www.pololu.com/product/2133)
- [TI DRV8825 Datasheet](https://www.ti.com/lit/ds/symlink/drv8825.pdf)

---

## 제어 ESP32-S3 에 DRV8825 두 개 — 배선표

| DRV8825 핀 | 드라이버 #1 | 드라이버 #2 |
|---|---|---|
| STEP | GPIO 15 | GPIO 14 |
| DIR | GPIO 16 | GPIO 21 |
| ENABLE | GND | GND |
| RESET | 3V3 | 3V3 |
| SLEEP | 3V3 | 3V3 |
| M0 / M1 / M2 | 미연결 | 미연결 |
| FAULT | 미연결 | 미연결 |
| GND (맨 아래) | ESP32 GND | ESP32 GND |
| VMOT | 18V (+) | 18V (+) |
| GND (VMOT 아래) | 18V (−) | 18V (−) |
| A1, A2 | 코일 1 | 코일 1 |
| B1, B2 | 코일 2 | 코일 2 |

- VMOT–GND 사이 전해 100µF/35V, 드라이버마다 하나.
- 18V(−) 와 ESP32 GND 공통.
- 4·5 는 CAN 이 쓰므로 안 씀.

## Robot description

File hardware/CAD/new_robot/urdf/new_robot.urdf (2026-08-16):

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
<robot name="new_robot">
    <link name="body2">
        <inertial>
            <mass value="0.000770683" />
            <origin xyz="-2.43868e-08 0.126 -4.07954e-08" rpy="0 -0 0" />
            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
        </inertial>
        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
    </link>
    <link name="body2_1">
        <inertial>
            <mass value="0.000770683" />
            <origin xyz="-2.43868e-08 0.126 -4.07954e-08" rpy="0 -0 0" />
            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
        </inertial>
        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
    </link>
    <link name="body2_2">
        <inertial>
            <mass value="0.000770683" />
            <origin xyz="-2.43868e-08 0.126 -4.07954e-08" rpy="0 -0 0" />
            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
        </inertial>
        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
    </link>
    <link name="body2_3">
        <inertial>
            <mass value="0.000770683" />
            <origin xyz="-2.43868e-08 0.126 -4.07954e-08" rpy="0 -0 0" />
            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
        </inertial>
        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
    </link>
    <link name="default">
        <inertial>
            <mass value="0.000267863" />
            <origin xyz="0.00375 0.018 -0.165" rpy="0 -0 0" />
            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
        </inertial>
        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
    </link>
    <link name="default_1">
        <inertial>
            <mass value="0.000267863" />
            <origin xyz="-3.46945e-18 -3.46945e-18 -0.165" rpy="0 -0 0" />
            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
        </inertial>
        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
    </link>
    <link name="default_10">
        <inertial>
            <mass value="0.000267863" />
            <origin xyz="-3.46945e-18 -3.46945e-18 -0.165" rpy="0 -0 0" />
            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
        </inertial>
        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
    </link>
    <link name="default_11">
        <inertial>
            <mass value="0.000267863" />
            <origin xyz="-0.01725 -0.018 -2.77556e-17" rpy="0 -0 0" />
            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
        </inertial>
        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
    </link>
    <link name="default_12">
        <inertial>
            <mass value="0.000267863" />
            <origin xyz="-0.01725 -0.018 -2.77556e-17" rpy="0 -0 0" />
            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
        </inertial>
        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
    </link>
    <link name="default_13">
        <inertial>
            <mass value="0.000267863" />
            <origin xyz="-3.46945e-18 -3.46945e-18 -0.165" rpy="0 -0 0" />
            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
        </inertial>
        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
    </link>
    <link name="default_2">
        <inertial>
            <mass value="0.000267863" />
            <origin xyz="-3.46945e-18 -3.46945e-18 -0.165" rpy="0 -0 0" />
            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
        </inertial>
        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
    </link>
    <link name="default_3">
        <inertial>
            <mass value="0.000267863" />
            <origin xyz="-3.46945e-18 -3.46945e-18 0.165" rpy="0 -0 0" />
            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
        </inertial>
        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
    </link>
    <link name="default_4">
        <inertial>
            <mass value="0.000267863" />
            <origin xyz="-0.01725 0.018 -2.77556e-17" rpy="0 -0 0" />
            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
        </inertial>
        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
    </link>
    <link name="default_5">
        <inertial>
            <mass value="0.000267863" />
            <origin xyz="-3.46945e-18 -0.0075 0.165" rpy="0 -0 0" />
            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
        </inertial>
        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
    </link>
    <link name="default_6">
        <inertial>
            <mass value="0.000267863" />
            <origin xyz="-0.01725 -0.018 -2.77556e-17" rpy="0 -0 0" />
            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
        </inertial>
        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
    </link>
    <link name="default_7">
        <inertial>
            <mass value="0.000267863" />
            <origin xyz="-3.46945e-18 -0.0075 -2.77556e-17" rpy="0 -0 0" />
            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
        </inertial>
        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
    </link>
    <link name="default_8">
        <inertial>
            <mass value="0.000267863" />
            <origin xyz="-3.46945e-18 -0.0075 0.165" rpy="0 -0 0" />
            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
        </inertial>
        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
    </link>
    <link name="default_9">
        <inertial>
            <mass value="0.000267863" />
            <origin xyz="-0.01725 0.018 -2.77556e-17" rpy="0 -0 0" />
            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
        </inertial>
        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
    </link>
    <link name="part_1">
        <inertial>
            <mass value="2.44526e-05" />
            <origin xyz="-5.42101e-18 -6.72205e-18 -0.026" rpy="0 -0 0" />
            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
        </inertial>
        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
    </link>
    <link name="part_1_1">
        <inertial>
            <mass value="2.44526e-05" />
            <origin xyz="-6.72205e-18 5.42101e-18 -0.026" rpy="0 0 -1.5708" />
            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
        </inertial>
        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
    </link>
    <link name="part_1_10">
        <inertial>
            <mass value="2.44526e-05" />
            <origin xyz="-6.72205e-18 5.42101e-18 0.026" rpy="0 0 -1.5708" />
            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
        </inertial>
        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
    </link>
    <link name="part_1_11">
        <inertial>
            <mass value="2.44526e-05" />
            <origin xyz="-5.42101e-18 -6.72205e-18 -0.026" rpy="0 -0 0" />
            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
        </inertial>
        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
    </link>
    <link name="part_1_12">
        <inertial>
            <mass value="2.44526e-05" />
            <origin xyz="-5.42101e-18 -6.72205e-18 -0.026" rpy="0 -0 0" />
            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
        </inertial>
        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
    </link>
    <link name="part_1_13">
        <inertial>
            <mass value="2.44526e-05" />
            <origin xyz="6.72205e-18 -5.42101e-18 -0.026" rpy="0 -0 1.5708" />
            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
        </inertial>
        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
    </link>
    <link name="part_1_14">
        <inertial>
            <mass value="2.44526e-05" />
            <origin xyz="-5.42101e-18 -6.72205e-18 0.026" rpy="0 -0 0" />
            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
        </inertial>
        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
    </link>
    <link name="part_1_15">
        <inertial>
            <mass value="2.44526e-05" />
            <origin xyz="-6.72205e-18 5.42101e-18 -0.026" rpy="0 0 -1.5708" />
            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
        </inertial>
        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
    </link>
    <link name="part_1_16">
        <inertial>
            <mass value="2.44526e-05" />
            <origin xyz="-5.42101e-18 -6.72205e-18 0.026" rpy="0 -0 0" />
            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
        </inertial>
        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
    </link>
    <link name="part_1_17">
        <inertial>
            <mass value="2.44526e-05" />
            <origin xyz="0.01144 -0.0195 -0.026" rpy="0 -0 0" />
            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
        </inertial>
        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
    </link>
    <link name="part_1_18">
        <inertial>
            <mass value="2.44526e-05" />
            <origin xyz="-5.42101e-18 -6.72205e-18 0.026" rpy="0 -0 0" />
            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
        </inertial>
        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
    </link>
    <link name="part_1_19">
        <inertial>
            <mass value="2.44526e-05" />
            <origin xyz="-7.37257e-18 0.0065 -0.026" rpy="0 -0 0" />
            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
        </inertial>
        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
    </link>
    <link name="part_1_2">
        <inertial>
            <mass value="2.44526e-05" />
            <origin xyz="0.01144 0.0195 0.026" rpy="0 -0 0" />
            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
        </inertial>
        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
    </link>
    <link name="part_1_20">
        <inertial>
            <mass value="2.44526e-05" />
            <origin xyz="-5.42101e-18 -6.72205e-18 0.026" rpy="0 -0 0" />
            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
        </inertial>
        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
    </link>
    <link name="part_1_21">
        <inertial>
            <mass value="2.44526e-05" />
            <origin xyz="-5.42101e-18 -6.72205e-18 -0.026" rpy="0 -0 0" />
            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
        </inertial>
        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
    </link>
    <link name="part_1_3">
        <inertial>
            <mass value="2.44526e-05" />
            <origin xyz="-0.00165 0.00127877 -0.026" rpy="0 -0 0" />
            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
        </inertial>
        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
    </link>
    <link name="part_1_4">
        <inertial>
            <mass value="2.44526e-05" />
            <origin xyz="-0.01144 0.0195 -0.026" rpy="0 -0 0" />
            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
        </inertial>
        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
    </link>
    <link name="part_1_5">
        <inertial>
            <mass value="2.44526e-05" />
            <origin xyz="-5.42101e-18 -6.72205e-18 -0.026" rpy="0 -0 0" />
            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
        </inertial>
        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
    </link>
    <link name="part_1_6">
        <inertial>
            <mass value="2.44526e-05" />
            <origin xyz="-5.42101e-18 -6.72205e-18 0.026" rpy="0 -0 0" />
            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

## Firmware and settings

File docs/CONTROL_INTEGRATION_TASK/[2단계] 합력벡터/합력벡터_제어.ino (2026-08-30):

/*
 * 합력벡터_제어.ino
 * -----------------------------------------------------------------------------
 * 2단계 — 합력 벡터 목표각 (ZV 입력성형은 아직 없음)
 *
 * 1단계 [모터_수평제어_I2C.ino](../[1단계]%20수평제어/모터_수평제어_I2C.ino) 에서
 * 목표각 θ_ref 만 0 이 아니게 바뀐 것이다. 나머지는 전부 같다.
 *
 *   1단계 :  θ_ref = 0                    →  motor_cmd = −θ_base   (수평 유지)
 *   2단계 :  θ_ref = atan(a_linear / g)   →  motor_cmd = θ_ref − θ_base
 *
 * ─────────────────────────────────────────────────────────────────────────────
 * 왜 수평이 정답이 아닌가
 *
 * 가속하는 차 안의 물컵을 생각하면 된다. 컵을 수평으로 붙잡고 있으면 물은
 * 뒤로 쏠린다. 액체 입장에서는 중력과 관성력의 **합력**이 진짜 아래쪽이므로,
 * 컵 바닥을 그 합력에 수직으로 놓아야 수면이 컵 기준으로 평평해진다.
 *
 *     정지·등속  :  합력 = 중력        →  θ_ref = 0      (수평이 정답)
 *     가속 중    :  합력 = 중력+관성력  →  θ_ref ≠ 0      (기울여야 정답)
 *
 * 그래서 수평제어와 안티슬로싱이 별개의 모드가 아니다. 아래 한 식이 두 경우를
 * 모두 덮는다. 경사면에 서 있으면 a_linear 가 0 이라 θ_ref 도 0 이 되어
 * 자동으로 절대 수평이 된다.
 *
 * ─────────────────────────────────────────────────────────────────────────────
 * 계산 순서
 *
 *   1. 상보필터로 차체 절대 자세 θ_base 를 얻는다            (1단계와 동일)
 *   2. 측정 가속도에서 중력 성분을 뺀다
 *
 *        a_lin_y = ay − g·sin(pitch)
 *        a_lin_x = ax − g·sin(roll)
 *
 *      가속도계는 기울어져 있기만 해도 중력을 읽는다. 그 몫을 빼야 순수한
 *      선형 가속만 남는다. 뺄 때 쓰는 각도가 1단계에서 만든 θ_base 다.
 *
 *   3. 합력이 수직에서 벗어난 각도
 *
 *        θ_ref = atan(a_lin / g)
 *
 *   4. 모터는 차체 기준으로 도므로 차체 자세를 뺀다
 *
 *        motor_cmd = θ_ref − θ_base
 *
 * ─────────────────────────────────────────────────────────────────────────────
 * ⚠ 켠 채로 부팅한다
 *
 * 부호를 실측으로 확정했으므로 (2026-08-29, DIR_ACC = +1) GAIN 1.0 / ACC_GAIN 1.0
 * 으로 부팅한다. arm 하는 순간 수평제어와 합력 항이 함께 살아 있다.
 *
 * 되돌릴 때는 ag0 → g0.3 → stop 순서다. 합력 항만 끄면 1단계와 같아진다.
 *
 * ─────────────────────────────────────────────────────────────────────────────
 * 배선·모터는 1단계와 동일
 *   IMU  : LSM6DSOX, I2C 0x6A (CS→3V3, SDO→GND), SDA=11 SCL=12
 *   모터 : GL60II ×2, MIT 모드, CAN TX=4 / RX=5
 *          바깥축 0x01 (Master 0x00) / 안쪽축 0x02 (Master 0x11)
 *
 * ─────────────────────────────────────────────────────────────────────────────
 * 시리얼 명령 (115200)  —  ★ 부팅 기본값
 *
 *   동작
 *     arm            모터 활성화 (현재 위치를 영점으로 잡고 켠다)
 *     stop  / s      비활성화
 *     z              모터 영점 재설정 — 지금 트레이 자세를 0 으로
 *     t              시험 구동 8초 (IMU·제어식을 거치지 않는 CAN 경로 확인)
 *     q              스트림 출력 켜기/끄기
 *     ?              현재 상태 전부 출력
 *
 *   제어 게인                        기본값      범위        올릴 때
 *     g<값>   수평 게인              ★ 1.00     0 ~ 1.5     1.0 = 완전 수평
 *     ag<값>  합력 게인              ★ 1.00     0 ~ 1.5     ag0 이면 1단계와 동일
 *     ad<값>  합력 목표각 필터       ★ 0.20     0 ~ 1       작을수록 느리고 매끈
 *
 *   지령 응답                        기본값      범위        올릴 때
 *     r<값>   슬루 제한 [°/s]        ★ 30       5 ~ 400     ag 가 안 먹으면 여기
 *     f<값>   지령 저역통과          ★ 0.15     0 ~ 1       클수록 빠르고 거칠다
 *     d<값>   CAN 분주               ★ 2        1 ~ 20      2 = 50Hz 전송
 *
 *   모터                             기본값      범위        올릴 때
 *     kp<값>  강성 [N·m/rad]         ★ 1.0      0 ~ 500     3 은 Kd 0 에서 발산했다
 *     kd<값>  감쇠 [N·s/rad]         ★ 0.10     0 ~ 5       0 은 매뉴얼상 금지
 *     dp / dr 회전 방향 뒤집기       ★ −1 / +1  토글        안쪽 / 바깥
 *
 *   코드에만 있는 값 (명령 없음)
 *     DIR_ACC        ★ +1     합력 목표각 부호. 실측 확정
 *     LIMIT_DEG      ★ 25°    지령 각도 상한
 *     ACC_REF_LIMIT  ★ 20°    합력 목표각 자체의 상한
 *     ACT_LIMIT_DEG  ★ 50°    실제 위치가 넘으면 폭주로 보고 끈다
 *
 * 값을 바꿔도 저장되지 않는다. 전원을 껐다 켜면 위 기본값으로 돌아온다.
 * 좋은 값을 찾으면 알려줄 것 — 코드의 기본값으로 박는다.
 *
 * 되돌릴 때 순서:  ag0  →  g0.3  →  stop
 *   수평제어는 살려둔 채 합력 항만 끄는 것이 먼저다.
 * -----------------------------------------------------------------------------
 */

#include <Wire.h>
#include "driver/twai.h"

// =============================================================================
//  설정
// =============================================================================

// ── IMU (I2C) ──
#define PIN_SDA    11
#define PIN_SCL    12
#define I2C_HZ     400000
#define IMU_ADDR   0x6A      // SDO→GND. 3V3 이면 0x6B

// ── CAN ──
#define CAN_TX_PIN  GPIO_NUM_4
#define CAN_RX_PIN  GPIO_NUM_5

/* 제어모드 접두.  CAN ID = (모드 << 8) | 모터ID
 *   0x000 = MIT,  0x100 = 위치/속도,  0x200 = 속도
 */
#define CAN_MODE  0x000

#define CAN_ID_PITCH  0x02
#define CAN_ID_ROLL   0x01

/* 모터 회전 방향 부호. CAN 으로 나갈 때만 곱해진다 (sendBoth 참고).
 * 제어식에는 들어가지 않으므로 cmd_pitch / cmd_roll 은 이 값과 무관하게
 * 항상 물리적으로 맞는 값이다. +30° 기울면 −30° 가 찍힌다.
 *
 * ★ 두 값이 다른 것이 정상이다. 짐벌의 두 모터가 서로 마주보게 장착돼 있어
 *   같은 부호를 주면 한 축이 기울기를 키우는 쪽으로 돈다. 카단 구조에서는
 *   흔한 배치다. 2026-08-29 실측 확인 (dp 명령으로 뒤집어 확정).
 *
 * 이 부호가 흔들렸던 이유는 부호 자체가 아니라 배정이었다.
 *
 *     모터_수평제어.ino       CAN_ID_PITCH 0x01 (바깥축)   DIR +1  → 정상
 *     모터_수평제어_MIT.ino   CAN_ID_PITCH 0x02 (안쪽축)   DIR +1  → 반대
 *
 *   MIT 모드로 포팅하면서 0x01 과 0x02 가 뒤바뀌었다. 모터 장착 방향이
 *   서로 반대라 같은 +1 인데 물리 방향이 뒤집혔다. 배정을 되돌리는 대신
 *   현재 배정에 맞춰 부호를 잡았다.
 *
 * ⚠ 배정 자체는 아직 잠정이다 (README 의 "미확정" 절). IMU 를 손에 들고
 *   있어 짐벌 축과 고정된 관계가 없다. 차체에 실장한 뒤 dp / dr 로 확정할 것.
 */
float DIR_PITCH = -1.0f;    // [dp] 기본 −1   안쪽축 0x02
float DIR_ROLL  = +1.0f;    // [dr] 기본 +1   바깥축 0x01

// ── 제어 파라미터 ──
float GAIN            = 1.0f;    // [g]  기본 1.00   완전 수평 보상
const float LIMIT_DEG = 25.0f;   //      기본 25°    지령 각도 상한 (명령 없음)
float MAX_RATE        = 30.0f;   // [r]  기본 30°/s  ag 가 안 먹으면 여기부터
float CMD_LPF         = 0.15f;   // [f]  기본 0.15   클수록 빠르고 거칠다
int   CAN_DIV         = 2;       // [d]  기본 2      100Hz / 2 = 50Hz 전송

/* 모터 임피던스 게인 — 실측값 (2026-08-27)
 *   Kp 1     트레이를 잡는다. Kp 3 은 Kd 0 에서 발산했다.
 *   Kd 0.1   밀었다 놓으면 왕복 없이 복귀. 0.05 는 1회 오버슛.
 *
 * ⚠ MIT 모드에는 속도 제한이 없다. 목표가 튀면 Kp × 오차 가 즉시 토크로 나간다.
 *   Kp 20 에 0.5 rad 오차면 10 N·m 로 TMAX 포화다. 실제로 기구가 튕긴 적이 있다.
 * ⚠ Kd 가 0 이 아니면 미세 진동이 생긴다. 엔코더 속도 추정 노이즈에 곱해지는
 *   것이라 원리적으로 못 없앤다.
 */
float MOTOR_KP = 1.0f;           // [kp] 기본 1.0    3 은 Kd 0 에서 발산했다
float MOTOR_KD = 0.1f;           // [kd] 기본 0.10   0 은 매뉴얼상 금지

const float TORQUE_WARN = 3.0f;

/* ── 합력 벡터 (2단계) ────────────────────────────────────────────────────
 * ACC_GAIN 0 이면 θ_ref 가 항상 0 이라 1단계(수평 유지)와 완전히 같다.
 * 부호를 확인한 뒤 0.3 → 0.6 → 1.0 으로 올린다.
 *
 * DIR_ACC 는 합력 목표각의 부호. 가속 방향과 기울여야 할 방향의 관계는
 * IMU 장착 방향에 따라 달라지므로 실측으로 정한다.
 * 반대면 액체를 더 흔든다. 파일 끝 "부호 확인 절차" 참고.
 *
 * ACC_LPF 는 θ_ref 전용 저역통과. 선형 가속 추정은 노이즈가 크므로 그대로
 * 쓰면 지령이 떨린다. 다만 필터가 세면 지연이 늘어 슬로싱 억제에 불리하다.
 */
float ACC_GAIN = 1.0f;      // [ag] 기본 1.00  ag0 으로 끄면 1단계와 동일
float DIR_ACC  = +1.0f;     //      기본 +1    실측 확정 (명령 없음)
float ACC_LPF  = 0.2f;      // [ad] 기본 0.20  작을수록 느리고 매끈
const float ACC_REF_LIMIT = 20.0f;   //      기본 20°   θ_ref 상한 (명령 없음)

// 계산된 목표각 (표시·기록용)
float ref_pitch = 0, ref_roll = 0;

/* 폭주 차단 — 지령은 ±LIMIT_DEG 를 넘지 않으므로 실제 위치가 이 값을 넘으면
 * 우리가 시킨 움직임이 아니다.
 */
const float ACT_LIMIT_DEG = 50.0f;   //      기본 50°   폭주 차단 (명령 없음)
const uint32_t FB_TIMEOUT_MS = 300;
unsigned long lastFb = 0;

// ── MIT 변환 범위 — 드라이버 설정과 일치해야 한다 ──
const float P_MIN  = -12.5f, P_MAX  =  12.5f;   // rad
const float V_MIN  = -30.0f, V_MAX  =  30.0f;   // rad/s (VMAX 30)
const float KP_MIN =   0.0f, KP_MAX = 500.0f;
const float KD_MIN =   0.0f, KD_MAX =   5.0f;
const float T_MIN  = -10.0f, T_MAX  =  10.0f;

// ── LSM6DSOX 레지스터 (I2C·SPI 공통) ──
#define REG_WHO_AM_I   0x0F
#define REG_CTRL1_XL   0x10
#define REG_CTRL2_G    0x11
#define REG_CTRL3_C    0x12
#define REG_OUTX_L_G   0x22

#define WHO_AM_I_VAL   0x6C
#define CTRL1_XL_VAL   0x68    // 416Hz, ±4g
#define CTRL2_G_VAL    0x6C    // 416Hz, ±2000dps
#define CTRL3_C_VAL    0x44    // BDU=1, IF_INC=1

const float G_LSB    = 8192.0;
const float GYRO_LSB = 14.286;
const float dt       = 0.01;
const float alpha_cf = 0.98;

const float ACC_TRUST_FALLOFF = 0.5;
const float ACC_MAG_DEAD      = 0.05;
const uint16_t REJ_RUN_FAULT  = 100;

const uint8_t ST_FAULT_MIN = 0x8;

const char* statusName(uint8_t st) {
  switch (st) {
    case 0x0: return "Disable";
    case 0x1: return "Enable";
    case 0x8: return "과전압";
    case 0x9: return "저전압";
    case 0xA: return "과전류";
    case 0xB: return "MOS과열";
    case 0xC: return "권선과열";
    case 0xD: return "통신끊김";
    case 0xE: return "과부하";
    default:  return "미정의";
  }
}

// =============================================================================
//  상태 변수
// =============================================================================
float pitch_filtered = 0, roll_filtered = 0;
float gyro_bias_x = 0, gyro_bias_y = 0;
float g_scale = 1.0;

float cmd_pitch = 0, cmd_roll = 0;

bool  armed  = false;
bool  imu_ok = false;
bool  stream = true;
uint16_t rej_run = 0;

uint8_t  last_status[4] = {0xFF, 0xFF, 0xFF, 0xFF};
float    act_deg[4]     = {0, 0, 0, 0};
uint32_t fb_count = 0;
uint32_t i2c_err  = 0;             // I2C 읽기 실패 누적

unsigned long lastLoop = 0, lastPrint = 0, lastCheck = 0;
uint32_t n_win = 0, err_win = 0, err_reset = 0;


// =============================================================================
//  IMU — I2C
// =============================================================================
/* SPI 판과 다른 부분은 여기뿐이다.
 * I2C 에는 SPI 의 "읽기는 MSB=1" 같은 규칙이 없다. 레지스터 주소를 쓰고
 * repeated start 로 곧바로 읽는다. 연속 읽기는 CTRL3_C 의 IF_INC 가 1 이어야
 * 주소가 자동 증가한다 (CTRL3_C_VAL 0x44 에 포함).
 */
bool i2cWrite(uint8_t reg, uint8_t val) {
  Wire.beginTransmission(IMU_ADDR);
  Wire.write(reg);
  Wire.write(val);
  return Wire.endTransmission() == 0;
}

bool i2cRead(uint8_t reg, uint8_t *buf, uint8_t n) {
  Wire.beginTransmission(IMU_ADDR);
  Wire.write(reg);
  if (Wire.endTransmission(false) != 0) { i2c_err++; return false; }   // repeated start
  if (Wire.requestFrom((int)IMU_ADDR, (int)n) != n) { i2c_err++; return false; }
  for (uint8_t i = 0; i < n; i++) buf[i] = Wire.read();
  return true;
}

uint8_t readReg(uint8_t reg) {
  uint8_t v = 0;
  i2cRead(reg, &v, 1);        // 실패하면 0 — 파워다운 감지가 이를 잡는다
  return v;
}

void writeReg(uint8_t reg, uint8_t val) { i2cWrite(reg, val); }

// 자이로 3축 + 가속도 3축 (리틀엔디안, 자이로 먼저)
void readIMU(int16_t &ax, int16_t &ay, int16_t &az,
             int16_t &gx, int16_t &gy, int16_t &gz) {
  uint8_t b[12] = {0};
  i2cRead(REG_OUTX_L_G, b, 12);   // 실패하면 전부 0 → 아래 검사에 걸린다

  gx = (int16_t)((b[1]  << 8) | b[0]);
  gy = (int16_t)((b[3]  << 8) | b[2]);
  gz = (int16_t)((b[5]  << 8) | b[4]);
  ax = (int16_t)((b[7]  << 8) | b[6]);
  ay = (int16_t)((b[9]  << 8) | b[8]);
  az = (int16_t)((b[11] << 8) | b[10]);
}

void configSensor() {
  writeReg(REG_CTRL3_C, 0x01);          // 소프트 리셋
  delay(50);
  writeReg(REG_CTRL3_C,  CTRL3_C_VAL);
  writeReg(REG_CTRL1_XL, CTRL1_XL_VAL);
  writeReg(REG_CTRL2_G,  CTRL2_G_VAL);
  delay(100);
}


// =============================================================================
//  MIT 모드 CAN  (SPI 판과 동일)
// =============================================================================
uint16_t float_to_uint(float x, float xmin, float xmax, uint8_t bits) {
  float span = xmax - xmin;
  if (x < xmin) x = xmin;
  if (x > xmax) x = xmax;
  uint32_t maxv = (1UL << bits) - 1;
  uint32_t v = (uint32_t)((x - xmin) * ((float)(1UL << bits) / span));
  return (uint16_t)(v > maxv ? maxv : v);
}

float uint_to_float(uint16_t xi, float xmin, float xmax, uint8_t bits) {
  float span = xmax - xmin;
  return ((float)xi) * span / ((float)((1UL << bits) - 1)) + xmin;
}

/* MIT 제어 프레임 (매뉴얼 42p)
 *   D0 pos[15:8]  D1 pos[7:0]  D2 vel[11:4]  D3 vel[3:0]|kp[11:8]
 *   D4 kp[7:0]    D5 kd[11:4]  D6 kd[3:0]|t[11:8]        D7 t[7:0]
 */
void sendMIT(uint8_t id, float pos, float vel, float kp, float kd, float tff) {
  uint16_t p   = float_to_uint(pos, P_MIN,  P_MAX,  16);
  uint16_t v   = float_to_uint(vel, V_MIN,  V_MAX,  12);
  uint16_t kpi = float_to_uint(kp,  KP_MIN, KP_MAX, 12);
  uint16_t kdi = float_to_uint(kd,  KD_MIN, KD_MAX, 12);
  uint16_t t   = float_to_uint(tff, T_MIN,  T_MAX,  12);

  twai_message_t m = {};
  m.identifier = CAN_MODE | id;
  m.data_length_code = 8;
  m.data[0] = p >> 8;
  m.data[1] = p & 0xFF;
  m.data[2] = v >> 4;
  m.data[3] = ((v & 0x0F) << 4) | (kpi >> 8);
  m.data[4] = kpi & 0xFF;
  m.data[5] = kdi >> 4;
  m.data[6] = ((kdi & 0x0F) << 4) | (t >> 8);
  m.data[7] = t & 0xFF;
  twai_transmit(&m, pdMS_TO_TICKS(5));
}

void sendUniversal(uint8_t id, uint8_t last) {  // FB=에러해제 FC=enable FD=disable FE=영점
  twai_message_t m = {};
  m.identifier = CAN_MODE | id;
  m.data_length_code = 8;
  memset(m.data, 0xFF, 7);
  m.data[7] = last;
  twai_transmit(&m, pdMS_TO_TICKS(5));
}

void broadcastUniversal(uint8_t last) {
  sendUniversal(CAN_ID_PITCH, last);
  sendUniversal(CAN_ID_ROLL,  last);
}

/* DIR 은 여기서만 곱한다. 모터 배선·장착 방향을 고쳐도 제어식과 화면 숫자는
 * 흔들리지 않는다. 두 관심사를 한 노브에 묶으면 부호를 뒤집을 때마다 로그의
 * 의미가 같이 바뀌어 무엇을 보고 있는지 알 수 없게 된다.
 */
void sendBoth() {
  sendMIT(CAN_ID_PITCH, cmd_pitch * DIR_PITCH * DEG_TO_RAD, 0.0f, MOTOR_KP, MOTOR_KD, 0.0f);
  sendMIT(CAN_ID_ROLL,  cmd_roll  * DIR_ROLL  * DEG_TO_RAD, 0.0f, MOTOR_KP, MOTOR_KD, 0.0f);
}


// =============================================================================
//  arm / disarm
// =============================================================================
void motorsDisarm(const char *reason) {
  if (armed) Serial.printf(">>> DISARM — %s\n", reason);
  broadcastUniversal(0xFD);
  armed = false;
  cmd_pitch = 0;  cmd_roll = 0;
}

void motorsArm() {
  // 저장된 플래그를 믿지 말고 직접 읽는다 (워치독이 내린 뒤 스스로 안 올라온다)
  uint8_t id = readReg(REG_WHO_AM_I);
  imu_ok = (id == WHO_AM_I_VAL);
  if (!imu_ok) {
    Serial.printf("!! IMU 응답 0x%02X (기대 0x%02X) — arm 거부\n", id, WHO_AM_I_VAL);
    return;
  }
  rej_run = 0;

  Serial.println(">>> arm: 트레이 중립 / 차체 수평 상태여야 합니다");
  broadcastUniversal(0xFB);  delay(50);   // 에러 해제
  broadcastUniversal(0xFE);  delay(50);   // 현재 위치를 영점으로

  // enable 전에 목표를 현재 위치(0)로 박아둔다. 빼면 마지막 목표로 확 튄다.
  cmd_pitch = 0;  cmd_roll = 0;
  sendBoth();
  delay(50);

  broadcastUniversal(0xFC);  delay(100);  // enable

  for (int i = 0; i < 4; i++) act_deg[i] = 0;   // 영점 후 낡은 위치값 제거
  lastFb = millis();
  armed = true;
  Serial.printf(">>> ARMED  GAIN=%.2f  ACC_GAIN=%.2f  Kp=%.1f  Kd=%.2f  제한 ±%.0f°\n",
                GAIN, ACC_GAIN, MOTOR_KP, MOTOR_KD, LIMIT_DEG);
}


// =============================================================================
//  유틸
// =============================================================================
float slew(float target, float prev, float maxStep) {
  float d = target - prev;
  if (d >  maxStep) d =  maxStep;
  if (d < -maxStep) d = -maxStep;
  return prev + d;
}
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
void loop() {
  handleSerial();

  long behind = (long)(micros() - lastLoop);
  if (behind < 10000) return;                    // 100Hz
  if (behind > 100000) lastLoop = micros();      // 크게 밀리면 재동기
  else                 lastLoop += 10000;

  // ── 1. 자세 추정 ──
  int16_t ax, ay, az, gx, gy, gz;
  readIMU(ax, ay, az, gx, gy, gz);

  float rate_pitch = ((float)gx - gyro_bias_x) / GYRO_LSB;
  float rate_roll  = ((float)gy - gyro_bias_y) / GYRO_LSB;

  float pitch_acc = atan2((float)ay,  sqrt(pow((float)ax, 2) + pow((float)az, 2))) * (180.0 / PI);
  float roll_acc  = atan2((float)-ax, sqrt(pow((float)ay, 2) + pow((float)az, 2))) * (180.0 / PI);

  float fax = ax, fay = ay, faz = az;
  float a_mag = sqrtf(fax * fax + fay * fay + faz * faz) / G_LSB / g_scale;

  // 1g 에서 벗어난 만큼 가속도계 반영 비중을 줄인다
  float dev   = fabsf(a_mag - 1.0f);
  float trust = constrain(1.0f - dev / ACC_TRUST_FALLOFF, 0.0f, 1.0f);
  float alpha = 1.0f - (1.0f - alpha_cf) * trust;

  pitch_filtered = alpha * (pitch_filtered + rate_pitch * dt) + (1.0f - alpha) * pitch_acc;
  roll_filtered  = alpha * (roll_filtered  + rate_roll  * dt) + (1.0f - alpha) * roll_acc;

  n_win++;
  if (trust <= 0.0f) { err_win++; rej_run++; } else rej_run = 0;

  // ── 2. 이상 감지 ──
  if (a_mag < ACC_MAG_DEAD && readReg(REG_CTRL1_XL) != CTRL1_XL_VAL) {
    err_reset++;
    Serial.println("!! 센서 응답 없음 — 재설정");
    configSensor();
    motorsDisarm("센서 리셋");
  }
  if (rej_run > REJ_RUN_FAULT) {
    imu_ok = false;
    motorsDisarm("IMU 무보정 구간 과다");
  }

  drainCAN();

  // ── 3. 합력 벡터 목표각 ──
  /* 두 축의 부호 규약이 반대라는 점이 이 블록 전체를 지배한다.
   *
   *     pitch 는  +ay  로,   roll 은  -ax  로 각도를 정의했다 (README 참고).
   *
   * 그래서 roll 의 가속도 성분을 처음부터 -ax 로 잡는다. 그러면 중력 제거도
   * 목표각 계산도 두 축이 똑같은 식이 되어, 규약을 틀릴 자리가 한 곳뿐이다.
   * 축마다 부호를 따로 들고 있으면 두 곳에서 어긋난다 — 실제로 그랬다.
   *
   *   1차 : 중력 제거를 두 축 다 빼도록 써서 roll 만 중력이 두 배로 남았다.
   *          평평한데 ref_roll 이 -5°, 조금만 기울이면 상한에 포화.
   *   2차 : 목표각 부호를 DIR_ACC 하나로 공유해 pitch 만 반대가 됐다.
   *          정지 상태로는 안 보이고 가속할 때만 나타난다.
   */
  float one_g = G_LSB * g_scale;

  float acc_p =  (float)ay;     // pitch 규약의 가속도 성분
  float acc_r = -(float)ax;     // roll  규약의 가속도 성분  ★ 각도 정의와 동일

  /* 가속도계는 기울어져 있기만 해도 중력을 읽는다. theta_base 로 그 몫을
   * 계산해 빼야 순수한 선형 가속만 남는다.
   */
  float p_lin = acc_p - one_g * sinf(pitch_filtered * DEG_TO_RAD);
  float r_lin = acc_r - one_g * sinf(roll_filtered  * DEG_TO_RAD);

  /* 합력이 수직에서 벗어난 각도.  theta_ref = -atan(a_linear / g)
   *
   * 앞의 마이너스가 물리다. +Y 로 가속하면 액체는 -Y 로 쏠리므로 트레이의
   * +Y 쪽을 내려야 하고, 우리 규약에서 +pitch 는 +Y 가 올라가는 것이라
   * 목표각은 음수가 된다. DIR_ACC 는 실측용으로 남겨둔 뒤집기다.
   */
  float raw_ref_p = -atan2f(p_lin, one_g) * RAD_TO_DEG * DIR_ACC;
  float raw_ref_r = -atan2f(r_lin, one_g) * RAD_TO_DEG * DIR_ACC;

  raw_ref_p = constrain(raw_ref_p, -ACC_REF_LIMIT, ACC_REF_LIMIT);
  raw_ref_r = constrain(raw_ref_r, -ACC_REF_LIMIT, ACC_REF_LIMIT);

  // 선형 가속 추정은 노이즈가 크므로 목표각을 따로 저역통과
  ref_pitch = ACC_LPF * raw_ref_p + (1.0f - ACC_LPF) * ref_pitch;
  ref_roll  = ACC_LPF * raw_ref_r + (1.0f - ACC_LPF) * ref_roll;

  // ── 4. 제어  motor_cmd = θ_ref − θ_base ──
  /* ACC_GAIN 이 0 이면 θ_ref 항이 사라져 1단계(−θ_base)와 완전히 같아진다.
   * 모터는 차체 기준으로 돌므로 절대 목표각에서 차체 자세를 뺀다.
   */
  float want_pitch = ACC_GAIN * ref_pitch - pitch_filtered * GAIN;
  float want_roll  = ACC_GAIN * ref_roll  - roll_filtered  * GAIN;

  want_pitch = constrain(want_pitch, -LIMIT_DEG, LIMIT_DEG);
  want_roll  = constrain(want_roll,  -LIMIT_DEG, LIMIT_DEG);

  static float lpf_pitch = 0, lpf_roll = 0;
  lpf_pitch = CMD_LPF * want_pitch + (1.0f - CMD_LPF) * lpf_pitch;
  lpf_roll  = CMD_LPF * want_roll  + (1.0f - CMD_LPF) * lpf_roll;

  const float maxStep = MAX_RATE * dt;
  cmd_pitch = slew(lpf_pitch, cmd_pitch, maxStep);
  cmd_roll  = slew(lpf_roll,  cmd_roll,  maxStep);

  static int div_cnt = 0;
  if (armed && (++div_cnt >= CAN_DIV)) {
    div_cnt = 0;
    sendBoth();
  }

  // ── 5. 출력 ──
  if (stream && millis() - lastPrint > 20) {      // 50Hz
    lastPrint = millis();
    Serial.printf("pitch:%.2f,ref_pitch:%.2f,cmd_pitch:%.2f,act_pitch:%.2f,"
                  "roll:%.2f,ref_roll:%.2f,cmd_roll:%.2f,act_roll:%.2f\n",
                  pitch_filtered, ref_pitch, cmd_pitch,
                  act_deg[CAN_ID_PITCH & 0x03] * DIR_PITCH,
                  roll_filtered,  ref_roll,  cmd_roll,
                  act_deg[CAN_ID_ROLL  & 0x03] * DIR_ROLL);
  }

  if (millis() - lastCheck > 2000) {
    lastCheck = millis();
    uint8_t c1 = readReg(REG_CTRL1_XL);
    if (c1 != CTRL1_XL_VAL) {
      err_reset++;
      Serial.printf("!! 센서 리셋 CTRL1_XL=0x%02X — 재설정\n", c1);
      configSensor();
      motorsDisarm("센서 리셋");
    }
    Serial.printf("[stat] %s Kp=%.1f Kd=%.2f 모터P=%s R=%s 피드백:%lu | 무보정:%lu/%lu I2C오류:%lu\n",
                  armed ? "ARMED" : "STOP", MOTOR_KP, MOTOR_KD,
                  statusName(last_status[CAN_ID_PITCH & 0x03]),
                  statusName(last_status[CAN_ID_ROLL  & 0x03]),
                  fb_count, err_win, n_win, i2c_err);
    n_win = 0;  err_win = 0;
  }
}

/* -----------------------------------------------------------------------------
 * 부호 확인 절차 — ACC_GAIN 을 올리기 전에 반드시
 *
 * 합력 목표각의 부호가 반대면 가속할 때 액체를 **더** 흔드는 쪽으로 기울인다.
 * 수평제어는 틀려도 트레이가 반대로 기우는 것으로 금방 보이지만, 이건
 * 가속하는 순간에만 나타나므로 눈으로 알아채기 어렵다. 숫자로 확인한다.
 *
 * ── 1) 모터 없이 부호만 본다 ────────────────────────────────────────────
 *
 * arm 하지 않은 상태로 IMU 를 책상 위에서 한 방향으로 쭉 민다.
 * 출력의 ref_pitch / ref_roll 을 본다. ACC_GAIN 이 0 이어도 계산되어 찍힌다.
 *
 *   pitch:0.10,ref_pitch:-4.20,cmd_pitch:0.00,...
 *                    ↑ 여기
 *
 * 판정 기준 — 액체가 쏠리는 반대쪽으로 기울여야 한다.
 *
 *   보드의 +Y 축 방향으로 밀었을 때
 *     ref_pitch 가 음수  →  +Y 쪽이 내려감  →  맞다   (DIR_ACC = +1 유지)
 *     ref_pitch 가 양수  →  틀리다. DIR_ACC 를 −1 로
 *
 * 왜 음수여야 하는가. 컵을 +Y 로 가속하면 물은 −Y 쪽으로 쏠린다. 수면을
 * 컵 기준으로 평평하게 두려면 컵의 +Y 쪽을 내려야 한다. 우리 규약에서
 * +pitch 는 +Y 가 올라가는 것이므로 목표는 음수가 된다.
 *
 * roll 도 같은 방식으로 +X 방향으로 밀어 확인한다.
 * (+roll 은 +X 가 내려가는 것이므로 부호 방향이 pitch 와 반대다)
 *
 * ── 2) 정지 상태에서 0 근처인지 ────────────────────────────────────────
 *
 * 책상에 가만히 두면 ref 가 0 근처여야 한다. 계속 치우쳐 있으면 중력 성분을
 * 덜 뺀 것이므로 g_scale 과 θ_base 를 먼저 의심한다.
 *
 * 기울여 놓고 가만히 두었을 때도 0 근처여야 한다. 기울기만으로 ref 가
 * 생긴다면 중력 제거가 잘못된 것이다. 이 경우 ACC_GAIN 을 올리면 안 된다.
 *
 * ── 3) 게인을 조금씩 ───────────────────────────────────────────────────
 *
 *   ag0.3   →  ag0.6  →  ag1.0
 *
 * 각 단계에서 IMU 를 밀었다 세웠다 하며 트레이가 가속 반대쪽으로 기우는지 본다.
 * 소리·진동이 커지면 한 단계 내린다.
 *
 * ── 되돌리기 ───────────────────────────────────────────────────────────
 *
 *   ag0     합력 항이 사라져 1단계(수평 유지)와 완전히 같아진다.
 *
 * 무슨 일이 생기면 stop 보다 ag0 이 먼저다. 수평제어는 계속 살아 있다.
 *
 * -----------------------------------------------------------------------------
 * 아직 없는 것 — 3단계에서
 *
 * ZV 입력성형이 없다. 지금은 θ_ref 가 바뀌는 즉시 그대로 따라가므로, 목표각의
 * 급변 자체가 슬로싱을 새로 만들 수 있다. 3단계에서 θ_ref 에 Convolved ZV 를
 * 걸어 그 성분을 없앤다.
 *
 * 그리고 지연이 150~180ms 로 측정돼 있다. 슬로싱 주기 420ms 의 36% 라
 * 위상 여유가 부족하다. CMD_LPF·슬루·Kp 를 손봐야 할 수 있다.
 * ---------------------------------------------------------------------------*/

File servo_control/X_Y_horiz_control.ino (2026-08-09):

#include <SPI.h>
#include <PID_v1.h>

// --- 핀 설정 ---
const int CS_ACTIVE = 5;  // 상단 트레이에 붙은 IMU 센서의 선택(Chip Select) 핀 (BMI160으로 교체)
const int CS_FIXED = 4;   // 하단 베이스에 붙은 IMU 센서의 선택(Chip Select) 핀 (ICM-42688 유지)
const int MOTOR_Y = 22;   // Y축 제어용 모터(서보 또는 PWM) 출력 핀
const int MOTOR_X = 16;   // X축 제어용 모터(서보 또는 PWM) 출력 핀
const int SCK_PIN = 18;   // SPI 통신용 시계(Clock) 핀
const int SDO_PIN = 19;   // SPI 데이터 입력(MISO) 핀
const int SDI_PIN = 23;   // SPI 데이터 출력(MOSI) 핀


// --- PWM 및 수평 설정 ---
const int PWM_FREQ = 333;  // 모터에 보내는 PWM 신호의 주파수 (333Hz)
const int PWM_RES = 10;    // PWM 해상도 (10비트 = 0~1023 단계로 정밀 제어)
int HORIZ_X = 460;         // X축이 수평일 때 모터에 전달할 기본값 (중점)
int HORIZ_Y = 510;         // Y축이 수평일 때 모터에 전달할 기본값 (중점)

// 모터의 기계적 파손을 막기 위한 이동 범위 제한값
const int LIMIT_X_MIN = 300, LIMIT_X_MAX = 650;
const int LIMIT_Y_MIN = 400, LIMIT_Y_MAX = 800;

// --- 물리 상수 및 매핑 비율 ---
const float G_LSB = 16384.0;  // 가속도 센서가 1G(중력)를 감지했을 때 뱉는 Raw 데이터 값
const float GYRO_LSB = 16.4;  // 자이로 센서가 초당 1도 회전할 때 뱉는 Raw 데이터 값

// 계산된 각도(degree)를 모터 제어용 수치(LSB)로 바꿀 때 곱해주는 비율 (1도당 약 286단위)
const float SCALE_FACTOR_X = 286.0;
const float SCALE_FACTOR_Y = 286.0;

// --- 영점(Bias) 변수 ---
double static_bias_X = 0;  // X축 시스템 전체의 정적 오프셋
double static_bias_Y = 0;  // Y축 시스템 전체의 정적 오프셋
float gyro_bias_x = 0;     // 하단 센서의 자이로 X축 센서 오차 (정지 상태인데 0이 아닐 경우)
float gyro_bias_y = 0;     // 하단 센서의 자이로 Y축 센서 오차

float gyro_bias_x_a = 0;  // 상단 센서의 자이로 X축 센서 오차
float gyro_bias_y_a = 0;  // 상단 센서의 자이로 Y축 센서 오차
float acc_z_error = 0;    // 가속도 센서 Z축이 완벽한 1G가 아닐 때의 오차

// --- 상보 필터 변수 ---
float pitch_filtered = 0;        // 하단 베이스의 필터링된 피치(앞뒤 기울기) 각도
float roll_filtered = 0;         // 하단 베이스의 필터링된 롤(좌우 기울기) 각도
float tray_pitch_filtered = 0;  // 상단 트레이의 필터링된 피치 각도
float tray_roll_filtered = 0;   // 상단 트레이의 필터링된 롤 각도

const float dt = 0.01;        // 루프가 한 번 도는 시간 (10ms = 0.01초)
const float alpha_cf = 0.98;  // 상보 필터 계수. 자이로 데이터에 98%의 신뢰도를 줌

//ZV
const int ZV_BUFFER_SIZE = 40;
const int DELTA_IDX = 21;  // 1차 모드 지연
const int delta_idx = 11;  // 3차 모드 지연

// X축, Y축 각각 독립적인 메모리 공간 할당
float zv_buffer_x[ZV_BUFFER_SIZE] = {
  0,
};
float zv_buffer_y[ZV_BUFFER_SIZE] = {
  0,
};
int zv_head_x = 0;
int zv_head_y = 0;

// --- PID 및 제어 변수 ---
float filteredRelDiffX = 0, filteredRelDiffY = 0;  // 필터링된 상대 오차값 (사용처 확인 필요)
const float alpha_XY = 0.2;                        // LPF(저주파 통과 필터) 계수
const int deadzone = 0;                            // 불감대 설정 (0이면 사용 안 함)

double Kp_X = 0.01, Ki_X = 0.00, Kd_X = 0.000;  // X축 PID 게인값
double Kp_Y = 0.0051, Ki_Y = 0.00, Kd_Y = 0.000;  // Y축 PID 게인값

// --- X축 비선형 Gain Scheduling 파라미터 ---
const double Kp_X_MAX = 0.007;   // 오차 클 때 (기존값 유지)
const double Kp_X_MIN = 0.002;  // 오차 0에 가까울 때
const double ERROR_MAX_DEG = 23.0; // 이 각도 이상이면 Kp_MAX 그대로 사용

double setpointX = 0, setpointY = 0;      // 우리가 가고자 하는 목표 각도
double inputX, outputX, inputY, outputY;  // PID의 입력(현재각)과 출력(모터힘)

// PID 객체 초기화: 입력값, 출력값 저장처, 목표값, 게인, 제어방향(REVERSE) 설정
PID pidX(&inputX, &outputX, &setpointX, Kp_X, Ki_X, Kd_X, DIRECT);
PID pidY(&inputY, &outputY, &setpointY, Kp_Y, Ki_Y, Kd_Y, REVERSE);

#define SPI_SPEED 1000000
#define SPI_MODE SPI_MODE0

// -------------------------------------------------------------
// [하단 ICM-42688용 기존 함수 유지]
// -------------------------------------------------------------
void writeReg(int cs, uint8_t reg, uint8_t data) {
  SPI.beginTransaction(SPISettings(SPI_SPEED, MSBFIRST, SPI_MODE));
  digitalWrite(cs, LOW);
  delayMicroseconds(20);
  SPI.transfer(reg);
  SPI.transfer(data);
  digitalWrite(cs, HIGH);
  SPI.endTransaction();
}

void readIMU(int cs, int16_t &ax, int16_t &ay, int16_t &az, int16_t &gx, int16_t &gy, int16_t &gz) {
  uint8_t b[12];
  SPI.beginTransaction(SPISettings(SPI_SPEED, MSBFIRST, SPI_MODE));
  digitalWrite(cs, LOW);
  delayMicroseconds(20);
  SPI.transfer(0x1F | 0x80);
  for (int i = 0; i < 12; i++) b[i] = SPI.transfer(0x00);
  digitalWrite(cs, HIGH);
  SPI.endTransaction();
  ax = (int16_t)((b[0] << 8) | b[1]);
  ay = (int16_t)((b[2] << 8) | b[3]);
  az = (int16_t)((b[4] << 8) | b[5]);
  gx = (int16_t)((b[6] << 8) | b[7]);
  gy = (int16_t)((b[8] << 8) | b[9]);
  gz = (int16_t)((b[10] << 8) | b[11]);
}

// -------------------------------------------------------------
// [상단 BMI160용 전용 함수 추가]
// -------------------------------------------------------------
void writeReg_BMI(int cs, uint8_t reg, uint8_t data) {
  SPI.beginTransaction(SPISettings(SPI_SPEED, MSBFIRST, SPI_MODE));
  digitalWrite(cs, LOW);
  delayMicroseconds(20);
  SPI.transfer(reg & 0x7F); // BMI Write: MSB 0
  SPI.transfer(data);
  digitalWrite(cs, HIGH);
  SPI.endTransaction();
}

void readIMU_BMI(int cs, int16_t &ax, int16_t &ay, int16_t &az, int16_t &gx, int16_t &gy, int16_t &gz) {
  uint8_t b[12];
  SPI.beginTransaction(SPISettings(SPI_SPEED, MSBFIRST, SPI_MODE));
  digitalWrite(cs, LOW);
  delayMicroseconds(20);
  SPI.transfer(0x0C | 0x80); // BMI Data 주소 | Read: MSB 1
  for (int i = 0; i < 12; i++) b[i] = SPI.transfer(0x00);
  digitalWrite(cs, HIGH);
  SPI.endTransaction();
  // BMI160 Little Endian 처리
  gx = (int16_t)((b[1] << 8) | b[0]);
  gy = (int16_t)((b[3] << 8) | b[2]);
  gz = (int16_t)((b[5] << 8) | b[4]);
  ax = (int16_t)((b[7] << 8) | b[6]);
  ay = (int16_t)((b[9] << 8) | b[8]);
  az = (int16_t)((b[11] << 8) | b[10]);
}

// 목표값(target)이 들어오면 진동을 줄이기 위해 과거값들과 섞는 함수
float applyConvolvedZV(float target, float *buffer, int &head) {
  buffer[head] = target;  // 현재 들어온 목표값을 버퍼의 현재 위치에 저장

  // 현재 시점(0), 지연 시점 1, 지연 시점 2, 결합 시점 3의 인덱스를 계산 (버퍼 오버플로우 방지 처리 포함)
  int idx_0 = head;
  int idx_1 = (head - DELTA_IDX + ZV_BUFFER_SIZE) % ZV_BUFFER_SIZE;
  int idx_2 = (head - delta_idx + ZV_BUFFER_SIZE) % ZV_BUFFER_SIZE;
  int idx_3 = (head - (DELTA_IDX + delta_idx) + ZV_BUFFER_SIZE) % ZV_BUFFER_SIZE;

  // 4개 시점의 목표값을 각각 0.25씩 나누어 합침 (입력을 부드럽게 쪼갬)
  float shaped_target = 0.25 * buffer[idx_0] + 0.25 * buffer[idx_1] + 0.25 * buffer[idx_2] + 0.25 * buffer[idx_3];

  head = (head + 1) % ZV_BUFFER_SIZE;  // 다음 데이터 저장을 위해 인덱스 한 칸 이동
  return shaped_target;                // 진동이 제거된 목표 각도 반환
}

void setup() {
    // SPI.begin() 이전에 추가
  pinMode(27, OUTPUT);
  digitalWrite(27, HIGH);
  delay(1000);
  Serial.println("CS_ACTIVE(27) HIGH 설정됨");

  // 일부러 LOW로 내렸다가 다시 HIGH
  digitalWrite(27, LOW);
  delay(100);
  digitalWrite(27, HIGH);
  Serial.println("CS 토글 완료");

  Serial.begin(115200);
  ledcAttach(MOTOR_X, PWM_FREQ, PWM_RES);
  ledcAttach(MOTOR_Y, PWM_FREQ, PWM_RES);
  ledcWrite(MOTOR_X, HORIZ_X);  // 시작 시 X축 수평 위치로 이동
  ledcWrite(MOTOR_Y, HORIZ_Y);  // 시작 시 Y축 수평 위치로 이동

  pinMode(SDO_PIN, INPUT);
  pinMode(CS_ACTIVE, OUTPUT);
  pinMode(CS_FIXED, OUTPUT);
  digitalWrite(CS_ACTIVE, HIGH);
  digitalWrite(CS_FIXED, HIGH);
  SPI.begin(SCK_PIN, SDO_PIN, SDI_PIN);
  delay(500);

  // setup() 안, SPI.begin() 이후 ~ writeReg 호출 이전에 추가
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

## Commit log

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2026-08-27 Stop treating the Enable status as a motor fault
    data[0]'s upper nibble is a status code, not an error code: 0 is
    Disable and 1 is Enable, with faults starting at 8. The check treated
    anything nonzero as a fault, so arming enabled the motor, the motor
    reported Enable, and the sketch immediately disarmed it — the motors
    never moved. Fault detection now starts at 0x8 and decodes the code to
    a name.
    Adds a "t" sweep command that drives both motors ±0.5 rad without
    touching the IMU or the control law, so a CAN-side problem can be told
    apart from a control-side one, and surfaces the per-motor status and
    feedback count in the status and stat lines.
    [모터_수평제어.ino]
2026-08-27 Make arming bumpless and calm the response for hand-held testing
    Arming cleared errors, zeroed, then enabled without ever setting a
    target, so the driver drove to whatever target it still held — after a
    sweep that is 0.5 rad, a 28 degree lurch independent of gain. Command
    the current position before enabling.
    The 100Hz accumulator also replayed every missed tick after a long
    call, so the 6-second sweep left it 600 iterations behind, integrating
    six seconds of gyro at once and flooding the bus. Resync instead when
    more than 0.1s behind.
    Adds a command low-pass filter and drops the default velocity limit,
    since with the IMU hand-held the motor faithfully chases hand tremor.
    v and f command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
    [모터_수평제어.ino]
2026-08-27 Log actual motor position and throttle the CAN send rate
    A 12-second capture showed the command holding to within 0.09 degrees
    while the motor still oscillated, so the cause is past the control code.
    Decode the position from the feedback frame and print it beside the
    command, and raise the print rate to 50Hz, so the oscillation's
    amplitude and period can actually be measured.
    Position/velocity drivers can restart their internal trajectory on every
    frame, so resending an unchanged target at 100Hz may keep it from
    settling. Send at 50Hz by default — the rate motor_test.ino ran at —
    adjustable with the d command.
    Adds capture.py to the repo (it was only in the session scratchpad) and
    reco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
    [capture.py, 모터_수평제어.ino]
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2026-08-27 Add MIT-mode leveling sketch to get a damping term
    Reading both drivers showed identical gains — Position KP 54, damping
    factor 4 — so the outer axis oscillating while the inner one held to
    ±0.03° is its inertia, not its configuration. Position/velocity mode
    cannot fix that: its cascade has no derivative term at all, and the
    gains live in driver flash.
    MIT mode carries Kp and Kd in every frame and runs an impedance law, so
    with v_des at zero the Kd term becomes the viscous damping the loop is
    missing. The manual warns outright that kd of zero makes the motor
    oscillate and lose control, which matches the symptom.
    Control law, IMU handling, and the safety limits are unchanged from
    모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
    [모터_수평제어_MIT.ino]
2026-08-27 Add q to toggle the 50Hz stream
    The stream scrolls too fast to type tuning commands into, which is the
    whole workflow for finding Kd.
    [모터_수평제어_MIT.ino]
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2026-08-27 Cut power when the motor leaves the commanded range
    Commands never exceed ±25°, so an actual position past ±50° is not
    something we asked for. Disarm there. During the addressing failure the
    motor turned three times, 1080°, while the code did nothing; this stops
    it at 50°.
    Feedback older than 300ms disarms too, so that check cannot pass on a
    stale position after the bus goes quiet.
    Default Kp drops to 1 — about 0.44 N·m at the angle limit — since the
    zero-torque check now clears the way to raise it from the bottom.
    [모터_수평제어_MIT.ino]
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2026-08-28 Set the measured gains and record how they were found
    Kp 1 holds the tray; Kp 3 diverged with no damping, reproducing the
    manual's warning. Kd 0.1 returns without overshoot where 0.05 overshoots
    once and 0 rings for several cycles. Defaults now match.
    Records what the earlier servo build's P-only success actually rested
    on: the servo had its own inner damping loop. MIT removes that, which is
    why the same approach diverges here.
    Two open items kept visible rather than buried: any nonzero Kd adds fine
    vibration from encoder velocity noise, which matters when the payload is
    liquid, and a high-frequency whine appeared once at Kd 0.1 without
    reproducing.
    [모터_수평제어_MIT.ino]
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2026-08-28 Re-read the IMU on arm instead of trusting a latched flag
    imu_ok was only ever set true in setup, so once the watchdog cleared it
    the sketch refused to arm until a reboot — even after the fault was
    fixed. The loose VIN contact put it in exactly that state. Arm now reads
    WHO_AM_I directly and reports the value it got when refusing.
    Also clears the stored motor positions on arm, since zeroing makes them
    meaningless and the position-limit check could otherwise disarm on a
    stale reading from the axis that has not reported yet.
    [모터_수평제어_MIT.ino]
2026-08-28 Add a continuous MIT-mode motor sweep test
    motor_test.ino only speaks the position/velocity protocol, so it does
    nothing now that both drivers are in MIT. This runs until stopped rather
    than for a fixed few seconds.
    The target only ever advances by rate×dt per 50Hz tick, so no setting
    can turn it into a step. That matters here because MIT has no velocity
    limit — porting the old ±0.5 rad jump straight over put out full torque
    and threw the rig.
    Stops on its own if a motor reports a fault, if actual position runs
    past the sweep amplitude by more than 25°, or if feedback goes quiet for
    300ms. Stopping walks the target back to zero before disabling so
    nothing is left held at an angle.
    [motor_test_MIT.ino]
2026-08-28 Throttle sensor recovery so the console stays usable
    configSensor blocks for 150ms and was being called every 10ms loop while
    the IMU was down, which left no room for serial input — arm and stop
    would not register during the very fault they were needed for. Retry
    once a second instead.
    Recovery still does not re-arm on its own; a sensor that glitches should
    not bring motors back by itself. It now says when the sensor answers
    again so re-arming is a single keystroke, and reports the WHO_AM_I value
    and fault count when it does not, which points at the VIN contact that
    is actually failing here.
    [모터_수평제어_MIT.ino]
2026-08-28 Revert "Throttle sensor recovery so the console stays usable"
    This reverts commit 32ac6ea760227ff5e6d2c3676c402123c2e92f7b.
    [모터_수평제어_MIT.ino]
2026-08-29 Default the MIT sweep test to Kd 0 so it runs quietly
    The test only needs to show the motors turn, not hold a position, and Kd
    is what makes the whine: the driver multiplies it by an encoder velocity
    estimate that jitters even at rest. motor_test.ino is silent because the
    position/velocity cascade handles damping internally and we send no Kd
    at all.
    Kd 0 measured silent and convergent at Kp 1, but the manual warns
    against it for position control and Kp 3 did diverge, so the Kp ceiling
    drops to 2 here. Actual holding control stays in 모터_수평제어_MIT.ino
    with Kd 0.1.
    [motor_test_MIT.ino]
2026-08-29 Start the sweep test between the two failure modes, not at one end
    Kd 0 removed the whine but left stick-slip: with Kp 1 the torque at a
    few degrees of error barely clears static friction, so the motor sticks,
    slips, and sticks again. Kd is what makes motion continuous, so zero
    buys quiet at the cost of smooth.
    Default to 0.05 and raise the Kp ceiling to 5 so both directions are
    reachable. Records why motor_test.ino manages smooth and quiet at once:
    its cascade runs Position KP 54 with an integrator, which MIT has no
    equivalent of.
    [motor_test_MIT.ino]
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2026-08-29 Add an I2C build of the leveling sketch
    The base IMU answers over I2C at 0x6A with the right WHO_AM_I while
    returning 0x00 on every SPI attempt, so the die is fine and only the SPI
    path is gone. I2C at 400kHz reads the twelve data bytes in about 0.3ms
    against a 10ms control period, so nothing is lost by moving.
    Only the sensor layer changes — I2C has no read bit, CS ties high and
    SDO to ground for the address, freeing GPIO10 and 13. Control law,
    gains, complementary filter, trust weighting, runaway cutoff, and the
    serial commands are unchanged from the SPI version.
    Counts failed I2C transfers and shows them in the stat line, since a
    rising count points at pull-ups or wiring rather than a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
    [모터_수평제어_I2C.ino]
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2026-08-29 Show the sweep test's current values at boot
    The a and r commands were already there but the banner only listed
    their syntax, so the values in effect were invisible and the sweep
    looked fixed at whatever it started as. Print each setting alongside its
    range, and state the resulting period so the effect of a change is
    readable before running.
    Raises the rate ceiling to 150 deg/s. Defaults stay where they are.
    [motor_test_MIT.ino]
2026-08-29 Add stage 2: resultant-vector target angle
    Replaces the fixed zero target with the direction of gravity plus the
    inertial reaction, so the tray sits perpendicular to what the liquid
    actually feels. Standing still or on a slope the linear term is zero and
    this reduces to stage 1, which is why leveling and anti-slosh are one
    law rather than two modes to switch between.
    ACC_GAIN defaults to 0, so a fresh upload behaves exactly like stage 1
    while ref_pitch and ref_roll are still computed and printed. A wrong
    sign here tilts into the slosh instead of against it, and unlike a
    leveling sign error it only shows during acceleration — so the target is
    verifiable on the bench before any of it reache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
    [합력벡터_제어.ino]
2026-08-29 Fix the sign of the roll gravity term
    The two axes define their angle from different accelerometer signs —
    pitch from +ay, roll from −ax — so gravity enters ay as +g·sin and ax as
    −g·sin. Subtracting it from both left roll carrying gravity twice over.
    It showed as ref_roll reading −5° while sitting flat at a roll of 2.5°,
    exactly double, and saturating the 20° limit at a modest tilt. ref_pitch
    was correct throughout, which is what pointed at the axis rather than
    the formula.
    Caught by the static check: a target angle must stay near zero when the
    board is tilted but not accelerating.
    [합력벡터_제어.ino]
2026-08-29 Fix the target-angle sign and make both axes symmetric
    The same convention mismatch that broke gravity removal broke the target
    angle too. pitch takes its angle from +ay and roll from -ax, so a single
    shared DIR_ACC cannot satisfy both: pitch needed -1 where roll needed +1.
    Accelerating along +Y reads ay = +A, and the tray must drop its +Y edge,
    which is negative pitch by our convention — so the target angle carries a
    minus sign that the code did not have. Nothing about this shows up while
    the sensor is still, and a push always produces an accelerate/decelerate
    pair, so the logged signs alone cannot separate the two. Derived instead.
    Rather than carry a per-axis sign, roll now takes its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
    [합력벡터_제어.ino]
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2026-08-29 Flip the inner axis and add runtime sign commands
    Tilting the IMU showed the outer axis turning against the tilt, as it
    should, while the inner axis turned with it. Turning with the tilt is
    positive feedback: it grows the error, and raising the gain would
    diverge. Worth catching before ACC_GAIN goes up.
    DIR_PITCH multiplies the whole expression, so the leveling and resultant
    terms flip together — both are tray-frame angles, so that is right.
    The sign stays provisional. Which motor answers to pitch is still a
    placeholder, and with the IMU held in hand it has no fixed relationship
    to the gimbal axes at all, so this has to be rechecked once it is
    mounted. Added dp and dr to flip each axis a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
    [합력벡터_제어.ino]
2026-08-29 Revert the inner-axis flip and move DIR to the send path
    The earlier flip read a holding artifact as a sign error. With the IMU in
    hand it is not attached to the gimbal, so which physical axis pitch
    answers to is decided by how the sensor is held; turning it 90 degrees
    swaps the two. With the signs left different (-1 and +1), exactly one
    axis looks wrong at any orientation, which is what was observed. Both
    axes go back to +1, and the sign cannot be settled until the IMU is
    mounted on the chassis.
    DIR no longer multiplies the control expression, only the value sent over
    CAN. It used to flip the printed command along with the motor direction,
    so correcting the wiring sense changed what the lo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
    [합력벡터_제어.ino]
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2026-08-29 Make DIR_PITCH -1 the default
    Confirmed with dp: both axes now turn against the tilt.
    The sign was never the thing that changed. Porting from position/velocity
    mode to MIT swapped CAN_ID_PITCH from 0x01 to 0x02, moving pitch from the
    outer motor to the inner one, and the two motors are mounted facing each
    other — so the same +1 came out reversed. That is why the direction was
    right in 모터_수평제어.ino and wrong in every file after it.
    So the two signs differing is the correct state, not a symmetric pair as
    I claimed earlier. Facing motors are ordinary in a cardan gimbal. It also
    explains the report that exactly one axis always turned the wrong way
    whichever way the sensor was held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
    [합력벡터_제어.ino]
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2026-08-29 Document the boot defaults in the header
    Values changed over serial do not persist, so after a power cycle every
    knob is back to its compiled default — but the file gave no single place
    to see what those are. Without that there is nothing to judge a new value
    against.
    The header now lists every command with its boot default, valid range,
    and a note on when to reach for it, and each declaration carries its
    command letter inline. Also lists the four values that exist only in code
    so it is clear they are not missing commands.
    Compiles for esp32s3.
    [합력벡터_제어.ino]
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2026-08-30 Let capture.py send a sequence of commands
    Opening the port resets the board, so anything set from the serial
    monitor beforehand is gone by the time recording starts. --cmd now
    accepts a comma-separated list and sends each one on its own line, with
    the responses recorded between them.
    Sending them as one line silently half-worked: the sketch matched the ag
    prefix and parsed "1.0,zv1" as 1.0, so ACC_GAIN was set and the rest
    vanished with no error.
    [capture.py]
2026-08-30 Boot with leveling and the resultant term already on
    GAIN 1.0 and ACC_GAIN 1.0 are now the compiled defaults in both stages.
    ACC_GAIN started at 0 so that uploading could not tilt the tray the wrong
    way before the sign was known; that was settled by measurement, so the
    guard has served its purpose and typing two commands after every reset
    only invites forgetting one.
    Reverting is still ag0 first, which leaves leveling running, then g0.3,
    then stop.
    Both compile for esp32s3.
    [ZV_입력성형.ino, 합력벡터_제어.ino]
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2026-09-01 Split the impedance gains per axis
    Cross-correlating command against actual position puts the inner axis at
    108 ms and the outer at 189 ms, reproduced across two captures. Corrected
    for that lag both track well (+0.96, +0.93), so nothing is inverted — the
    outer axis is simply late. At zero lag the correlations are +0.68 and
    +0.19, which is why watching it suggests it turns the wrong way.
    189 ms is 45% of the 420 ms slosh period, near antiphase, so with liquid
    aboard that axis would feed the sloshing rather than damp it.
    It is not short of torque: it reaches 0.94 of the commanded amplitude. It
    is short of bandwidth, because the outer axis carries the inner gimbal and
    the tray, and w scale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
    [zv_shaping_rtos.ino]
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2026-09-01 Feed the command's derivative as v_des
    MIT torque is Kp(p_des - p) + Kd(v_des - v) + t_ff, and v_des was zero, so
    the damping term read -Kd*v — it braked every intended move, not just
    disturbances. At 90 deg/s and Kd 0.22 that is 0.35 N.m of opposition,
    needing 3.3 degrees of position error at Kp 6 to overcome, or 16% of a 20
    degree amplitude. Measured tracking sits at 0.87.
    We generate cmd, so its derivative is known exactly rather than estimated.
    Taken after the slew limiter so it cannot exceed MAX_RATE, and filtered
    only lightly — heavy filtering would delay the feedforward and defeat it.
    DIR multiplies the velocity as well as the position. Without that, flipping
    an axis would leave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
    [zv_shaping_rtos.ino]
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2026-09-02 Report CAN bus state so a silent motor can be diagnosed
    Motors stopped responding to arm and t with the IMU fine and the drivers
    powered. The status line said feedback 0 and TX failures 0, which does not
    separate the two causes: twai_transmit returns ESP_OK once a frame is
    queued, so the counter stays at zero even with the bus dead.
    The controller's own error counters do separate them. Any listening node
    acknowledges a CAN frame, so wiring or transceiver loss drives the TX
    error counter to 255 and the state to BUS_OFF, while a driver that is
    merely in the wrong ControlMode still acknowledges — error counter 0,
    state RUNNING, and only the feedback missing.
    printCanStatus reports state and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
    [zv_shaping_rtos.ino]
2026-09-02 Recover from CAN bus-off instead of needing a reboot
    Diagnosis came back BUS_OFF with TX error 128, RX error 0 and two frames
    stuck in the queue: nothing on the bus is acknowledging, so this is the
    physical layer, not a driver mode.
    TWAI does not leave BUS_OFF on its own — twai_initiate_recovery must be
    called, and twai_start again once the state drops to STOPPED. Without
    that, fixing the wiring still leaves the board dead until it is power
    cycled, which is how this session got stuck.
    Recovery also needs a working bus to complete, since it waits on 128
    runs of eleven recessive bits. So sitting in RECOVERING is itself the
    signal that the wiring is still broken, which is more useful than
    s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
    [zv_shaping_rtos.ino]
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2026-09-02 Test the transceiver at the pin level
    The NO_ACK test said nothing loops back, but its report line came out
    mangled so the sent count was lost — split into short lines with ASCII
    labels.
    Added a check below the protocol entirely. A transceiver pulls the bus
    dominant when TXD is low and reads that same bus back on RXD, so dropping
    the TWAI driver and toggling the pins by hand tests one chip and nothing
    else. TX high to RX high and TX low to RX low means the chip and its 3.3V
    are fine; RX stuck low points at an unpowered transceiver or a shorted
    H/L pair; RX refusing to follow TX down points at the GPIO4 wiring or the
    transmit side of the chip.
    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
    [zv_shaping_rtos.ino]
2026-09-02 Try both pin orientations, and fix the newline placeholder
    The pin test printed a literal @@ because the newline substitution missed
    that block. Swept the whole file for leftovers.
    The result it did show is useful: RX idles high, so the transceiver has
    power, and it will not follow TX down, so the transmit path is what is
    broken. Two causes look alike there, and one of them is testable without
    touching wires — GPIO4 on RXD and GPIO5 on TXD would leave the test
    pressing an output pin and reading an input, which reads exactly like a
    dead transmitter. So the test now runs both orientations and says if they
    are swapped.
    If neither orientation works, the message leads with the Rs (S/STB/EN)
    p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
    [zv_shaping_rtos.ino]
2026-09-02 Check the GPIO pins themselves before blaming the wiring
    Both orientations report 1 1 1, so the transmit path never pulls the bus
    dominant. Before more wire-chasing, rule out the microcontroller: drive
    each pin low and high and read it back. A pin that will not follow its
    own drive is either held externally or damaged, and no amount of wiring
    work would fix that.
    Correcting an earlier claim here too — a shorted CANH/CANL was described
    as giving RX low. It gives RX high: the receiver needs 0.9 V of difference
    to read dominant, and a short forces the difference to zero, so the bus
    reads recessive forever. A short produces exactly the 1 1 1 seen here,
    which puts it alongside a floating Rs pi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
    [zv_shaping_rtos.ino]
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2026-09-02 Scan for the pins the transceiver is actually on
    A second transceiver behaves identically, so the chip was the wrong
    suspect and the test is pointing somewhere I had not looked. What the
    readings actually describe is a pin with nothing on it: GPIO4 follows its
    own drive, GPIO5 reads high in every case, and neither orientation
    responds — which is what an unconnected input does.
    So 'cs' drives each candidate pin and reads all the others, looking for
    one that follows. Same approach as the CS-pin sweep that found the IMU.
    If a pair turns up, the wiring is on different pins than the code names;
    if none does, the transceiver is not reaching the ESP32 at all and the
    pin numbers in the code are n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
    [zv_shaping_rtos.ino]
2026-09-02 Pull the scan's read pins up to reject phantom pairs
    The sweep returned six pairs, but floating pins couple to their
    neighbours capacitively with nothing to load them, so most were noise.
    A pull-up separates them: a real RXD output sinks current and stays low
    against it, while coupling loses and reads high.
    One pair looks real and explains every earlier reading — GPIO5 driving
    GPIO6, one pin over from the GPIO4/GPIO5 the code names. That leaves
    GPIO4 on nothing, has the test reading the transceiver's TXD input as its
    RX, and never touches the actual RXD, which is why the reversed
    orientation failed too despite driving the right pin.
    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
    [zv_shaping_rtos.ino]
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2026-09-03 Restore the raw_pitch/raw_roll log fields
    Puts back the teammate's commit on top of the rolled-back sketch — the
    Snap fields, the assignment from raw_ref_p/r, and the two names in the
    stream line. Applied from that commit directly so the wording is theirs.
    check_tuning.py needs these to measure raw->act and separate the input
    filters from the motor; without them only cmd->act is available.
    Nothing else comes back with it: no velocity feedforward, no CAN
    diagnostics.
    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
    [zv_shaping_rtos.ino]
2026-09-03 Add the soft return on acceleration release
    Ported the control part of 지연_개선_실험/soft_return_rtos.ino. The
    velocity feedforward and the CAN diagnostics in that file were left out.
    The direct-compensation target only sees present acceleration, so it
    collapses to zero the moment acceleration stops and the tray snaps level
    while the liquid is still carrying the earlier motion — the snap starts
    fresh sloshing. This holds whatever target remains at release, then runs
    a minimum-jerk curve to zero. The onset is untouched, so the fast
    response of direct compensation stays.
    Release is judged on raw_ref, before ACC_LPF, because the filtered value
    keeps a tail after the acceleration ends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
    [zv_shaping_rtos.ino]
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
